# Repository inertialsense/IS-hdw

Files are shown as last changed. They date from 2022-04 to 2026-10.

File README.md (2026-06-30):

Inertial Sense Logo

# Hardware Design Files

The Inertial Sense hardware design files are made available to facilitate product hardware development and integration.

 - **Products** - 3D models and resources for the IMX, Rugged, IG, EVB, and related products useful for printed circuit board CAD and circuit board designs.  Example PCB projects including the IG-1 and EVB-2.  Libraries for schematic and layout designs for printed circuit board. 

------

## LICENSE



Use these Hardware Design files as you wish.  Inertial Sense is not liable for any claim, damages, or other liability resulting from their use.  See the included *LICENSE* file for details.

------

## Support

Email - support@inertialsense.com

------

(c) 2014-2026 Inertial Sense, Inc.

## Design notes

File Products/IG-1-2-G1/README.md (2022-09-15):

# IG-1-G1

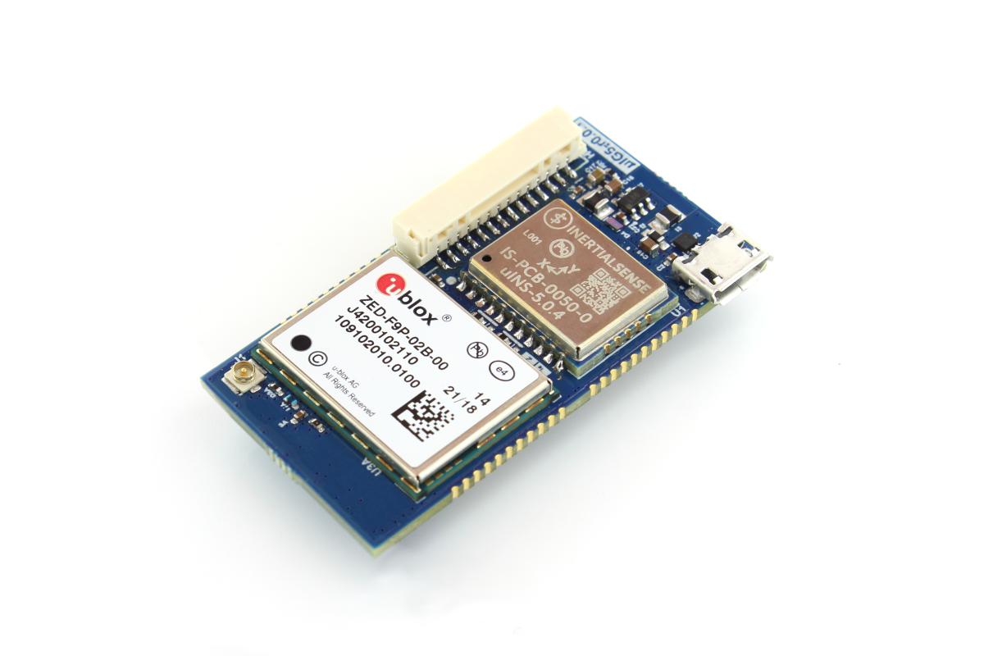
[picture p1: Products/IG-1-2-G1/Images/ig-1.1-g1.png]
IG-1


The InertialSense IG-1 module combines the IMX-5 and a ublox ZED-F9P multi-band GNSS receiver in a compact surface mount modular form factor. 

## Features

- **Tactical Grade IMU (w/ IMX-5)**
  - **Gyro: 1.5 °/hr Bias Instability, 0.16 °/√hr ARW**
  - **Accel: 19 μg Bias Instability, 0.02 m/s/√hr VRW**
- **High Accuracy INS (w/ IMX-5):  0.03° Roll/Pitch, 0.1° Dynamic Heading**
- Up to 1KHz IMU and INS Output Data Rate
- Dual onboard multi-band (L1/L2/E5) GNSS receivers
- Dual U.FL antenna ports for GPS compassing
- Small form factor:  65.2 x 24.5 x 5.9 mm
- Light weight:  <15g
- Low power consumption:  <1500mW
- Surface Mount Reflowable
- Breakout header and micro USB interface to the IMX
- UART x3, SPI interfaces
- Onboard voltage regulation for 3.3V - 17V input

## Applications

- Drone Navigation
- Unmanned Vehicle Payloads
- Ground and Aerial Survey
- Automotive Navigation
- Stabilized Platforms
- Antenna and Camera Pointing
- First Responder and Trackers
- Health, Fitness, and Sport Monitors
- Robotics and Ground Vehicles
- Maritime

## LICENSE



Use these Hardware Design files as you wish.  Inertial Sense is not liable for any claim, damages, or other liability resulting from their use.  See the included *LICENSE* file for details.

------

## Support

Email - support@inertialsense.com

------

(c) 2014-2022 Inertial Sense, Inc.

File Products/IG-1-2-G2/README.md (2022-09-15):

# IG-1-G2

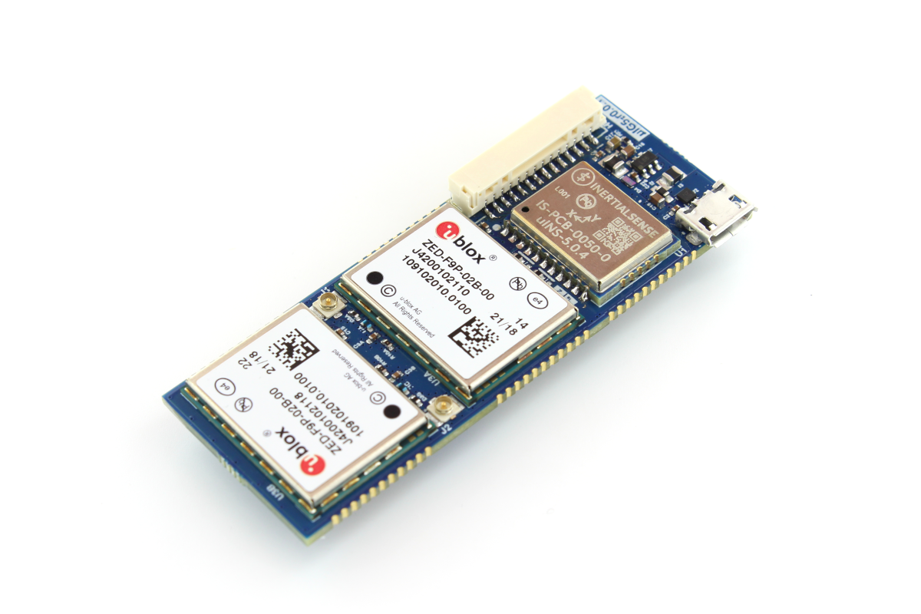
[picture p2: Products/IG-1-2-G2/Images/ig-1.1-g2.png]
IG-1


The InertialSense IG-1-G2 module combines the IMX-5 and two ublox ZED-F9P multi-band GNSS receivers in a compact surface mount modular form factor. 

## Features

- **Tactical Grade IMU (w/ IMX-5)**
  - **Gyro: 1.5 °/hr Bias Instability, 0.16 °/√hr ARW**
  - **Accel: 19 μg Bias Instability, 0.02 m/s/√hr VRW**
- **High Accuracy INS (w/ IMX-5):  0.03° Roll/Pitch, 0.1° Dynamic Heading**
- Up to 1KHz IMU and INS Output Data Rate
- Dual onboard multi-band (L1/L2/E5) GNSS receivers
- Dual U.FL antenna ports for GPS compassing
- Small form factor:  65.2 x 24.5 x 5.9 mm
- Light weight:  <15g
- Low power consumption:  <1500mW
- Surface Mount Reflowable
- Breakout header and micro USB interface to the IMX
- UART x3, SPI interfaces
- Onboard voltage regulation for 3.3V - 17V input

## Applications

- Drone Navigation
- Unmanned Vehicle Payloads
- Ground and Aerial Survey
- Automotive Navigation
- Stabilized Platforms
- Antenna and Camera Pointing
- First Responder and Trackers
- Health, Fitness, and Sport Monitors
- Robotics and Ground Vehicles
- Maritime

## LICENSE



Use these Hardware Design files as you wish.  Inertial Sense is not liable for any claim, damages, or other liability resulting from their use.  See the included *LICENSE* file for details.

------

## Support

Email - support@inertialsense.com

------

(c) 2014-2022 Inertial Sense, Inc.

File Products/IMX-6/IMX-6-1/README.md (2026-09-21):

# IMX-6

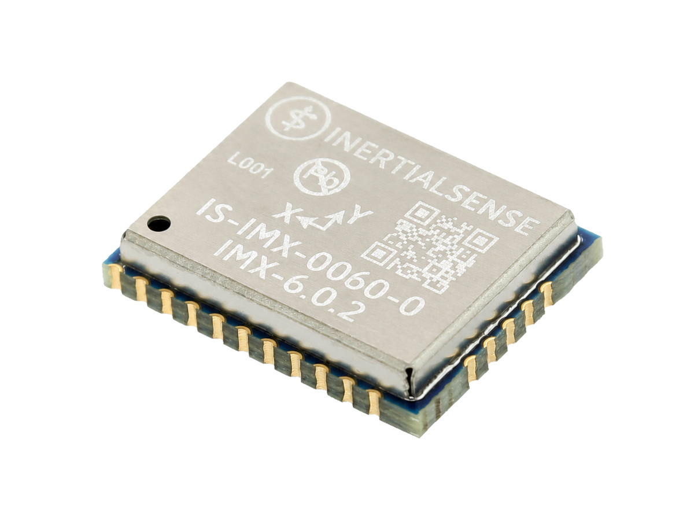
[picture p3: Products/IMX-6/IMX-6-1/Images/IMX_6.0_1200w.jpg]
IMX-6


The **IMX-6**™ is a 10-DOF sensor module consisting of a tactical grade Inertial Measurement Unit (IMU), magnetometer, and barometer. Output includes angular rate, linear acceleration, magnetic vector, and barometric pressure and altitude. IMU calibration consists of bias, scale factor, cross-axis alignment, and temperature compensation. The IMX-6 includes Attitude Heading Reference System (**AHRS**) sensor fusion to estimate roll, pitch, and heading. Adding GNSS input to the IMX-6 enables onboard Inertial Navigation System (**INS**) sensor fusion for roll, pitch, heading, velocity, and position.

## Features

- **Tactical Grade IMU**
  - **Gyro: 0.95 °/hr Bias Instability, 0.10 °/√hr ARW**
  - **Accel: 4.0 µg Bias Instability, 0.011 m/s/√hr VRW**
- **INS, AHRS**
  - **Dynamic: 0.03° Roll/Pitch, 0.09° Heading**
  - **Static: 0.1° Roll/Pitch, 0.5° Heading**
- **Surface Mount Reflowable (PCB Module)**
- Up to 1 KHz IMU and 500 Hz INS Output Data Rate
- Small Form Factor:  15.6 x 12.5 x 2.9 mm
- Light Weight:  0.9 g
- Low power consumption:  <110 mW
- External GNSS Support (Multi-Band)
- Attitude (Roll, Pitch, Yaw, Quaternions), Velocity, and Position UTC Time Synchronized
- Triple Redundant IMUs Calibrated for Bias, Scale Factor, Cross-axis Alignment, and G-sensitivity
- -40°C to 85°C Sensor Temperature Calibration
- Binary and NMEA ASCII Protocol
- Barometric Pressure and Humidity
- Strobe In/Out Data Sync (Camera Shutter Event) 
- Fast Integration with SDK and Example Software

## Applications

- Drone Navigation
- Unmanned Vehicle Payloads
- Ground and Aerial Survey
- Automotive Navigation
- Stabilized Platforms
- Antenna and Camera Pointing
- First Responder and Trackers
- Health, Fitness, and Sport Monitors
- Robotics and Ground Vehicles
- Maritime

## LICENSE



Use these Hardware Design files as you wish.  Inertial Sense is not liable for any claim, damages, or other liability resulting from their use.  See the included *LICENSE* file for details.

------

## Support

Email - support@inertialsense.com

------

(c) 2014-2026 Inertial Sense, Inc.

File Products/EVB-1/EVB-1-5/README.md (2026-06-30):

# EVB-1

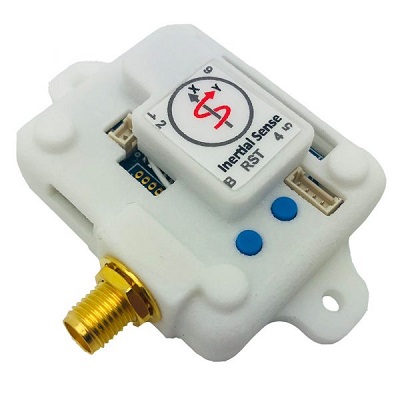
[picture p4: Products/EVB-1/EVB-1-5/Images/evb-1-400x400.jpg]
evb-1


The Inertial Sense EVB1.x is a development board which contains the Inertial Sense µINS, µAHRS, or µIMU module. The EVB1.x functions as a breakout and communications board with the following features:

- Access to all communications pins on the module
- USB connection, either directly to the module or through an on-board FTDI chip
- Integrated RS232 / RS485 transceiver

## LICENSE



Use these Hardware Design files as you wish.  Inertial Sense is not liable for any claim, damages, or other liability resulting from their use.  See the included *LICENSE* file for details.

------

## Support

Email - support@inertialsense.com

------

(c) 2014-2026 Inertial Sense, Inc.

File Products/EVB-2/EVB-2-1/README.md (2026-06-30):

# EVB-2 Evaluation Board

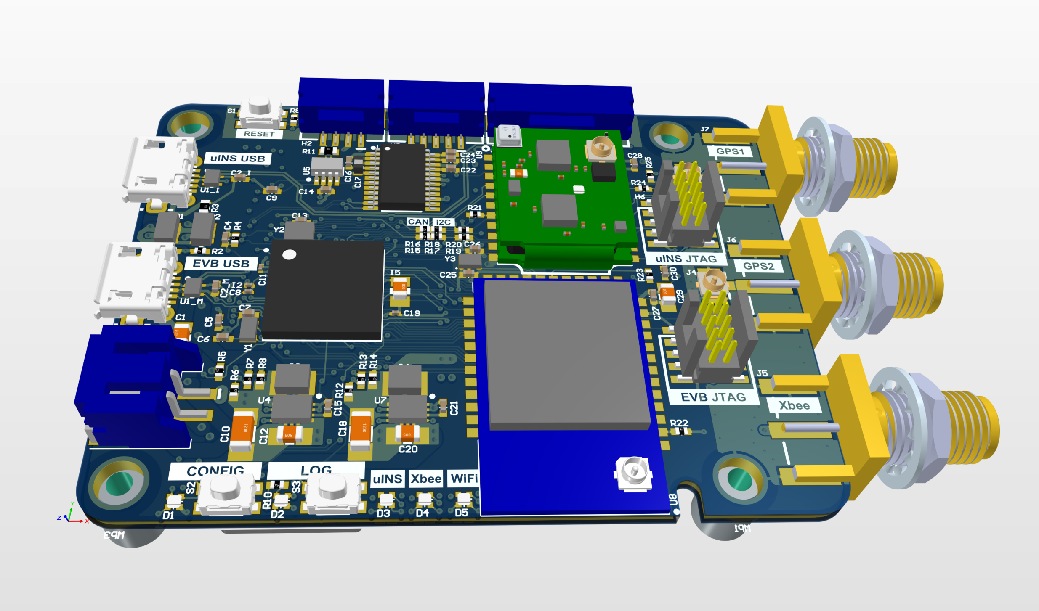
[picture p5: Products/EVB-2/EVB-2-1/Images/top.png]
EVB-2


The Inertial Sense [EVB-2](https://docs.inertialsense.com/user-manual/hardware/EVB2/) is a development board which contains the Inertial Sense µINS, µAHRS, or µIMU module. The EVB-2 builds on the foundation established by the EVB-1, but adds these and other new features.

The EVB-2 PCB assembly design files are provided in Altium Designer format.

## Features

- 915MHz Xbee radio for RTK (real-time-kinematics)
- Wi-Fi and Bluetooth Low energy (BLE) for remote data viewing and logging operation
- Onboard logging to micro SD card.
- Companion Microchip SAME70 processor that serves as a communication bridge between the µINS, µAHRS, or µIMU and all other interfaces.

- **Tactical Grade IMU (w/ IMU-5)**
  - **Gyro: 1.5 °/hr Bias Instability, 0.16 °/√hr ARW**
  - **Accel: 19 μg Bias Instability, 0.02 m/s/√hr VRW**

- **High Accuracy INS (w/ IMU-5):  0.03° Roll/Pitch, 0.1° Dynamic Heading**
- Up to 1KHz IMU and INS Output Data Rate
- Dual onboard GNSS receivers
- Dual SMA antenna ports for GPS compassing
- Size:  70.5 x 45.0 x 12.6 mm
- UART x3, RS232, RS485, CAN, and SPI interfaces
- Integrated CAN and RS232 / RS485 transceivers
- Voltage regulation for 3.3V - 17V input

## Applications

- Drone Navigation
- Unmanned Vehicle Payloads
- Ground and Aerial Survey
- Automotive Navigation
- Stabilized Platforms
- Antenna and Camera Pointing
- First Responder and Trackers
- Health, Fitness, and Sport Monitors
- Robotics and Ground Vehicles
- Maritime

------

## LICENSE



Use these Hardware Design files as you wish.  Inertial Sense is not liable for any claim, damages, or other liability resulting from their use.  See the included *LICENSE* file for details.

------

## Revision Info

### r2.1.2

+ Move TIOA1 (TC input) pin from GPIO1 to GPIO9 for measuring encoder velocity on to GPIO9 (multi-tie).  We would not like to have to tie GPIO9 and GPIO3 together offboard the EVB-2 for wheel encoder input.  We share the QDEC and TC input on the same line for angle and velocity measurement.

+ Consider adding a TC input to each of the QDEC channel A lines so all wheel encoder inputs support velocity measurement.
+ Add second CAN transceiver from EVB E70 to H2 and remove CAN jumper.  We can share H2 with IMX and EVB-E70.  Connect transceivers disable line to jumper or EVB disable line.
+ Enlarge fiducials from 0.76mm to 1.0mm on both sides.
+ Fix the I2C line (SDA, SCL) reversal on EVB-2 SAME70.

________________________________________________________________________________

### r2.1.0

+ Dual purpose reset line to reset IMX and MCU using an RC filters.  One resets
  quickly and the other follows after a delay.
+ Consider loading ICE debugger header for SAME70 MCU by default to support
  developers.
+ Expose IMX data ready pin GPIO13 on H7.
+ Fix top layer copper pour for XBee regulator input that connects C20 pin 2 to
  XBee regulator U7 pin 1.
+ Cut trace (disconnect) VUSB from ESD protection for both USB ports.  It's
  causing voltage to appear on FET switches and partially enable.
+ Add EVB version number to PCB
+ Consider switching battery to Seiko MS621T for -40 to 85 C temp range.
+ Add jumper selection of CAN transceiver to IMX and EVB processor for CAN
  support.
+ Consider exposing SAME70 chip erase (PB12) to SMT resistor pads to 3.3V.
+ Fix reversed IMX CAN Rx and Tx lines.  (Double check this).

________________________________________________________________________________

### r2.0.1

+ Add inverted bold labels for I/O headers.
+ Reverse the H1 power pin order so pin 1 is positive and pin 2 ground.
+ Add fiducials to help SMT machine alignment.
+ Invert and increase label size for I/O headers so they are easier to read.
+ Move to new button style
+ Fit shorter U.FL cables
+ Fix error that applied H1 voltage to the USB port in the power schematic
+ Remove or fix XBee USB power FET logic (Q3).
+ Remove R51 and connect with trace.
+ Fix RX line of XOR gate.
+ Add version label.
+ Update manufacturing docs for new U.FL cables (current cables are good)
+ Jumper to G1_SDA and G2_SCL to CAN transceiver to support future generation
  of IMX which will have new processor with CAN stack. 
+ Consider consolidating the power input FET arrays
+ Move INS reset from common reset to MCU pin.
+ Move voltage sensing circuit to analog capable pin of MCU instead of on INS.
+ Connect QDEC2 and QDEC4 lines to H8 so we can support 3 quadrature encoders.
+ Move to 0.0033uF caps on SS/TR lines on voltage regulators to bring rise time
  into spec.

------

## Support

Email - support@inertialsense.com

------

(c) 2014-2026 Inertial Sense, Inc.

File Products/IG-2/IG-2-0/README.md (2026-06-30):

# IG-2.0

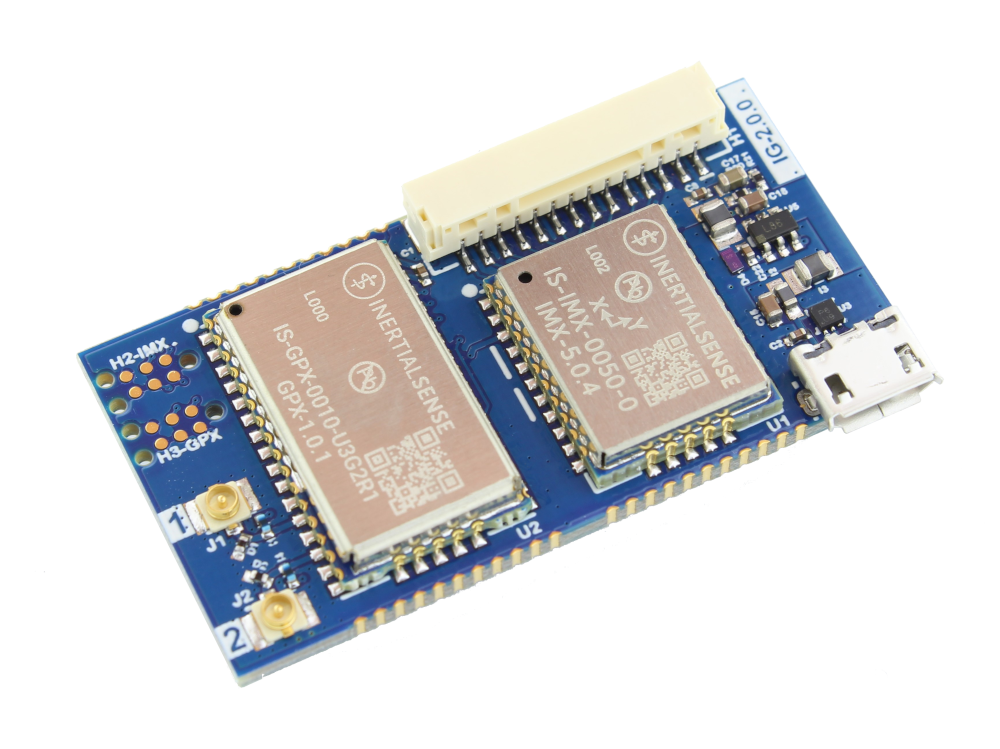
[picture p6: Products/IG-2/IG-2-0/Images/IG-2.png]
IG-2.0


The InertialSense IG-2.0 module combines the IMX-5 and GPX-1 dual multi-band GNSS receiver in a compact surface mount modular form factor. 

## Features

- **Tactical Grade IMU (w/ IMX-5)**
  - **Gyro: 2.0 °/hr Bias Instability, 0.23 °/√hr ARW**
  - **Accel: 27 µg Bias Instability, 0.020 m/s/√hr VRW**
- **High Accuracy INS (w/ IMX-5):  0.03° Roll/Pitch, 0.1° Dynamic Heading**
- Up to 1KHz IMU and INS Output Data Rate
- Dual onboard multi-band (L1/L5) GNSS receivers
- Dual U.FL antenna ports for GPS compassing
- Small form factor:  65.2 x 24.5 x 5.9 mm
- Light weight:  <15g
- Low power consumption:  <1500mW
- Surface Mount Reflowable
- Breakout header and micro USB interface to the IMX
- UART x3, SPI interfaces
- Onboard voltage regulation for 3.3V - 17V input

## Applications

- Drone Navigation
- Unmanned Vehicle Payloads
- Ground and Aerial Survey
- Automotive Navigation
- Stabilized Platforms
- Antenna and Camera Pointing
- First Responder and Trackers
- Health, Fitness, and Sport Monitors
- Robotics and Ground Vehicles
- Maritime

## LICENSE



Use these Hardware Design files as you wish.  Inertial Sense is not liable for any claim, damages, or other liability resulting from their use.  See the included *LICENSE* file for details.

------

## Support

Email - support@inertialsense.com

------

(c) 2014-2026 Inertial Sense, Inc.

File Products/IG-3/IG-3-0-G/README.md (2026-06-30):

# IG-2.1

IG-2.1

The InertialSense IG-2.1 module combines the IMX-6 and GPX-1 dual multi-band GNSS receiver in a compact surface mount modular form factor. 

## Features

- **Tactical Grade IMU (w/ IMX-6)**
  - **Gyro: 1.5 °/hr Bias Instability, 0.10 °/√hr ARW**
  - **Accel: 2.8 µg Bias Instability, 0.013 m/s/√hr VRW**
- **High Accuracy INS (w/ IMX-6):  0.03° Roll/Pitch, 0.1° Dynamic Heading**
- Up to 1KHz IMU and INS Output Data Rate
- Dual onboard multi-band (L1/L5) GNSS receivers
- Dual U.FL antenna ports for GPS compassing
- Small form factor:  65.2 x 24.5 x 5.9 mm
- Light weight:  <15g
- Low power consumption:  <1500mW
- Surface Mount Reflowable
- Breakout header and micro USB interface to the IMX
- UART x3, SPI interfaces
- Onboard voltage regulation for 3.3V - 17V input

## Applications

- Drone Navigation
- Unmanned Vehicle Payloads
- Ground and Aerial Survey
- Automotive Navigation
- Stabilized Platforms
- Antenna and Camera Pointing
- First Responder and Trackers
- Health, Fitness, and Sport Monitors
- Robotics and Ground Vehicles
- Maritime

## LICENSE



Use these Hardware Design files as you wish.  Inertial Sense is not liable for any claim, damages, or other liability resulting from their use.  See the included *LICENSE* file for details.

------

## Support

Email - support@inertialsense.com

------

(c) 2014-2026 Inertial Sense, Inc.

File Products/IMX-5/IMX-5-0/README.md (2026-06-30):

# IMX-5

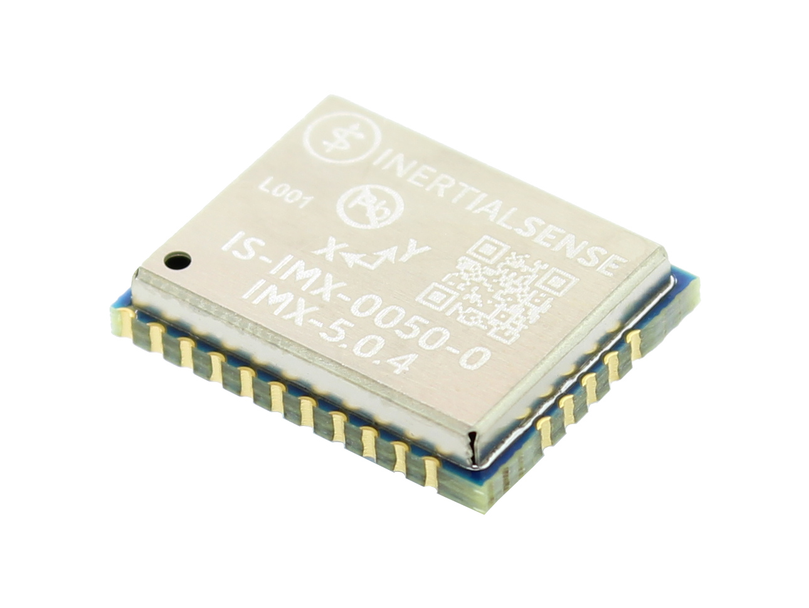
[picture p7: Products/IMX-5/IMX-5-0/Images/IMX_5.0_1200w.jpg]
IMX-5


The **IMX-5**™ is a 10-DOF sensor module consisting of a tactical grade Inertial Measurement Unit (IMU), magnetometer, and barometer. Output includes angular rate, linear acceleration, magnetic vector, and barometric pressure and altitude. IMU calibration consists of bias, scale factor, cross-axis alignment, and temperature compensation. The IMX-5 includes Attitude Heading Reference System (**AHRS**) sensor fusion to estimate roll, pitch, and heading. Adding GNSS input to the IMX-5 enables onboard Inertial Navigation System (**INS**) sensor fusion for roll, pitch, heading, velocity, and position.

## Features

- **Tactical Grade IMU**
  - **Gyro: 2.0 °/hr Bias Instability, 0.23 °/√hr ARW**
  - **Accel: 27 µg Bias Instability, 0.020 m/s/√hr VRW**
- **INS, AHRS**
  - **Dynamic: 0.04° Roll/Pitch, 0.13° Heading**
  - **Static: 0.1° Roll/Pitch, 0.5° Heading**
- **Surface Mount Reflowable (PCB Module)**
- Up to 1 KHz IMU and 142 Hz INS Output Data Rate
- Small Form Factor:  15.6 x 12.5 x 2.9 mm
- Light Weight:  0.8 g
- Low power consumption:  <110 mW
- External GNSS Support (Multi-Band)
- Attitude (Roll, Pitch, Yaw, Quaternions), Velocity, and Position UTC Time Synchronized
- Triple Redundant IMUs Calibrated for Bias, Scale Factor, Cross-axis Alignment, and G-sensitivity
- -40°C to 85°C Sensor Temperature Calibration
- Binary and NMEA ASCII Protocol
- Barometric Pressure and Humidity
- Strobe In/Out Data Sync (Camera Shutter Event) 
- Fast Integration with SDK and Example Software

## Applications

- Drone Navigation
- Unmanned Vehicle Payloads
- Ground and Aerial Survey
- Automotive Navigation
- Stabilized Platforms
- Antenna and Camera Pointing
- First Responder and Trackers
- Health, Fitness, and Sport Monitors
- Robotics and Ground Vehicles
- Maritime

## LICENSE



Use these Hardware Design files as you wish.  Inertial Sense is not liable for any claim, damages, or other liability resulting from their use.  See the included *LICENSE* file for details.

------

## Support

Email - support@inertialsense.com

------

(c) 2014-2026 Inertial Sense, Inc.

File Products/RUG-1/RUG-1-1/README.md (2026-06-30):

# Rugged-1

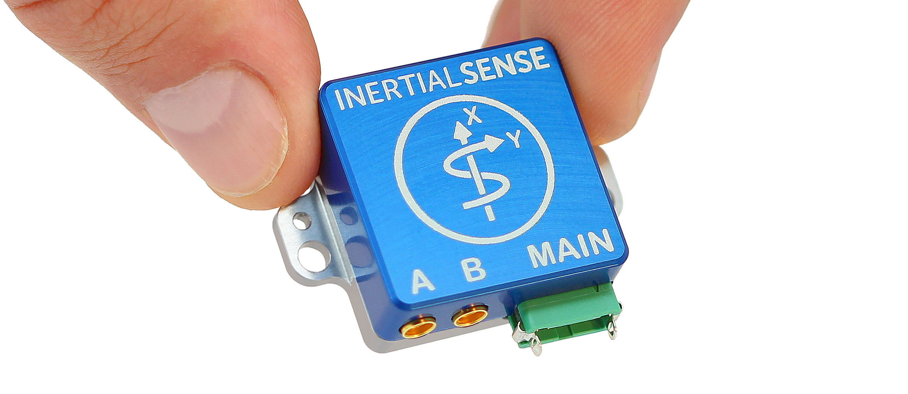
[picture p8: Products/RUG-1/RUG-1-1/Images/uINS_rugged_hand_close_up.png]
Rugged-1


The Inertial Sense Rugged-1 is a ruggedized carrier board and case for the Inertial Sense µINS, µAHRS, or µIMU module. The Rugged-1 has similar functions compared to the EVB-1, but in a more compact form factor with the following added features:

## Features

- **Tactical Grade IMU (w/ IMU-5)**

- - **Gyro: 1.5 °/hr Bias Instability, 0.16 °/√hr ARW**
  - **Accel: 19 μg Bias Instability, 0.02 m/s/√hr VRW**
- **High Accuracy INS (w/ IMU-5):  0.03° Roll/Pitch, 0.1° Dynamic Heading**
- Up to 1KHz IMU and INS Output Data Rate
- Dual onboard multi-band (L1/L2/E5) GNSS receivers
- Dual MMCX antenna ports for GPS compassing
- Size:  25.4 x 25.4 x 11.2 mm
- Light weight:  10.5g
- Low power consumption:  <1100mW
- UART x3, RS232, RS485, CAN, and SPI interfaces
- Integrated CAN and RS232 / RS485 transceivers
- Voltage regulation for 3.3V - 17V input

## Applications

- Drone Navigation
- Unmanned Vehicle Payloads
- Ground and Aerial Survey
- Automotive Navigation
- Stabilized Platforms
- Antenna and Camera Pointing
- First Responder and Trackers
- Health, Fitness, and Sport Monitors
- Robotics and Ground Vehicles
- Maritime

## LICENSE



Use these Hardware Design files as you wish.  Inertial Sense is not liable for any claim, damages, or other liability resulting from their use.  See the included *LICENSE* file for details.

------

## Support

Email - support@inertialsense.com

------

(c) 2014-2026 Inertial Sense, Inc.

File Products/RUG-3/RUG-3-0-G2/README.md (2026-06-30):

# RUG-3-IMX-5-Dual	(Rugged-3 Dual)

<center>

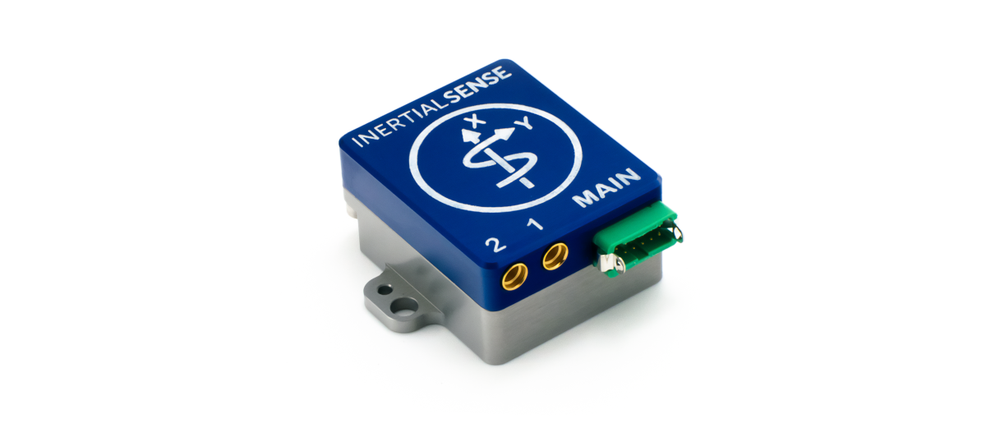
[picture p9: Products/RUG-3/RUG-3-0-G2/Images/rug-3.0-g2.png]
RUG-3-IMX-5-Dual


<center/>

The **RUG-3-IMX-5-Dual** adds a rugged aluminum enclosure and RS232, RS485, and CAN bus to the IMX-5. The **RUG-3-IMX-5-RTK** includes a multi-frequency GNSS receiver with RTK precision position enabling INS sensor fusion for roll, pitch, heading, velocity, and position. The **RUG-3-IMX-5-Dual** includes two multi-frequency GNSS receivers with RTK precision position and dual GNSS heading/compass. 

## Features

- **Tactical Grade IMU (w/ IMU-5)**
  - **Gyro: 2.0 °/hr Bias Instability, 0.23 °/√hr ARW**
  - **Accel: 27 µg Bias Instability, 0.020 m/s/√hr VRW**
- **High Accuracy INS (w/ IMU-5):  0.03° Roll/Pitch, 0.1° Dynamic Heading**
- Up to 1KHz IMU and INS Output Data Rate
- Dual onboard multi-band (L1/L2/E5) GNSS receivers
- Dual MMCX antenna ports for GPS compassing
- Size:  25.4 x 25.4 x 20.0 mm
- Light weight:  14g
- Low power consumption:  <1500mW
- UART x3, RS232, RS485, CAN, and SPI interfaces
- Integrated CAN and RS232 / RS485 transceivers
- Voltage regulation for 3.3V - 17V input

## Applications

- Drone Navigation
- Unmanned Vehicle Payloads
- Ground and Aerial Survey
- Automotive Navigation
- Stabilized Platforms
- Antenna and Camera Pointing
- First Responder and Trackers
- Health, Fitness, and Sport Monitors
- Robotics and Ground Vehicles
- Maritime

## LICENSE



Use these Hardware Design files as you wish.  Inertial Sense is not liable for any claim, damages, or other liability resulting from their use.  See the included *LICENSE* file for details.

------

## Support

Email - support@inertialsense.com

------

(c) 2014-2026 Inertial Sense, Inc.

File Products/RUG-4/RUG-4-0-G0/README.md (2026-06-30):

# RUG-4-G0	(Rugged-4)

<center>

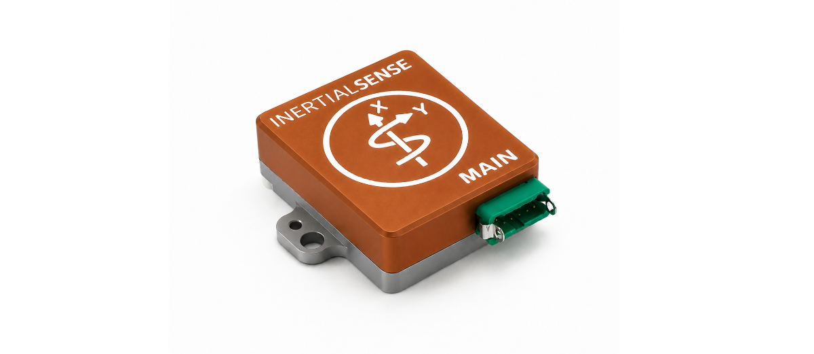
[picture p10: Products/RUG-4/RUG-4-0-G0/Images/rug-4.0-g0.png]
RUG-4-IMX-5


<center/>

The **RUG-4** adds a rugged aluminum enclosure and RS232, RS485, and CAN bus to the **IMX-6**.  Addition of an external GNSS receiver enables the onboard Inertial Navigation System (INS) sensor fusion for roll, pitch, heading, velocity, and position.  

## Features

- **Tactical Grade IMU**
  - **Gyro: 1.5 °/hr Bias Instability, 0.10 °/√hr ARW**
  - **Accel: 2.8 µg Bias Instability, 0.013 m/s/√hr VRW**
- **INS, AHRS**
  - **Dynamic: 0.03° Roll/Pitch, 0.09° Heading**
  - **Static: 0.1° Roll/Pitch, 0.5° Heading**
- Up to 1KHz IMU and INS Output Data Rate
- Dual onboard multi-band (L1/L2/E5) GNSS receivers
- Dual MMCX antenna ports for GPS compassing
- Size:  25.4 x 25.4 x 20.0 mm
- Light weight:  14g
- Low power consumption:  <1500mW
- UART x3, RS232, RS485, CAN, and SPI interfaces
- Integrated CAN and RS232 / RS485 transceivers
- Voltage regulation for 3.1V - 23V input (42V with R1 jumper)

## Applications

- Drone Navigation
- Unmanned Vehicle Payloads
- Ground and Aerial Survey
- Automotive Navigation
- Stabilized Platforms
- Antenna and Camera Pointing
- First Responder and Trackers
- Health, Fitness, and Sport Monitors
- Robotics and Ground Vehicles
- Maritime

## LICENSE



Use these Hardware Design files as you wish.  Inertial Sense is not liable for any claim, damages, or other liability resulting from their use.  See the included *LICENSE* file for details.

------

## Support

Email - support@inertialsense.com

------

(c) 2014-2026 Inertial Sense, Inc.

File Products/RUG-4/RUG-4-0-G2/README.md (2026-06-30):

# RUG-4-Dual	(Rugged-4 Dual)

<center>

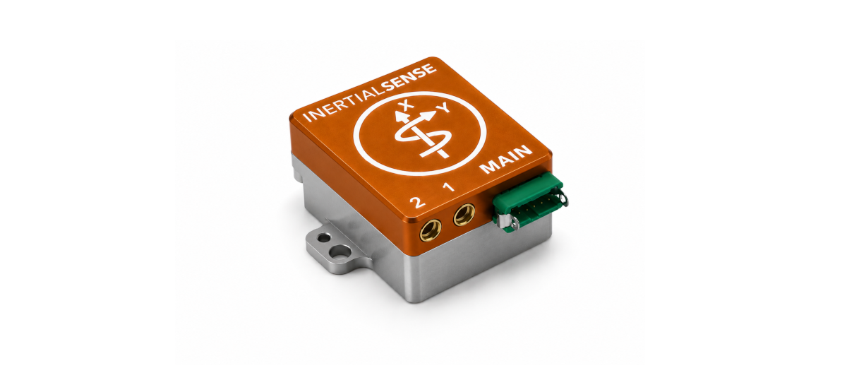
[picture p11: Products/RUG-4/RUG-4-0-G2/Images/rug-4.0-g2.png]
RUG-4-Dual


<center/>

The **RUG-4-Dual** adds a rugged aluminum enclosure and RS232, RS485, and CAN bus to the **IMX-6**. The **RUG-4-RTK** includes a multi-frequency GNSS receiver with RTK precision position enabling INS sensor fusion for roll, pitch, heading, velocity, and position. The **RUG-4-Dual** includes two multi-frequency GNSS receivers with RTK precision position and dual GNSS heading/compass. 

## Features

- **Tactical Grade IMU**
  - **Gyro: 1.5 °/hr Bias Instability, 0.10 °/√hr ARW**
  - **Accel: 2.8 µg Bias Instability, 0.013 m/s/√hr VRW**
- **INS, AHRS**
  - **Dynamic: 0.03° Roll/Pitch, 0.09° Heading**
  - **Static: 0.1° Roll/Pitch, 0.5° Heading**
- Up to 1KHz IMU and INS Output Data Rate
- Dual onboard multi-band (L1/L2/E5) GNSS receivers
- Dual MMCX antenna ports for GPS compassing
- Size:  25.4 x 25.4 x 20.0 mm
- Light weight:  14g
- Low power consumption:  <1500mW
- UART x3, RS232, RS485, CAN, and SPI interfaces
- Integrated CAN and RS232 / RS485 transceivers
- Voltage regulation for 3.1V - 23V input (42V with R1 jumper)

## Applications

- Drone Navigation
- Unmanned Vehicle Payloads
- Ground and Aerial Survey
- Automotive Navigation
- Stabilized Platforms
- Antenna and Camera Pointing
- First Responder and Trackers
- Health, Fitness, and Sport Monitors
- Robotics and Ground Vehicles
- Maritime

## LICENSE



Use these Hardware Design files as you wish.  Inertial Sense is not liable for any claim, damages, or other liability resulting from their use.  See the included *LICENSE* file for details.

------

## Support

Email - support@inertialsense.com

------

(c) 2014-2026 Inertial Sense, Inc.

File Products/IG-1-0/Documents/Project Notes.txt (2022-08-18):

IS-IG-r1.0.3 Project Notes   (- to do, + done, x skipped)

________________________________________________________________________________

Changes for r1.0.3
- Enable GPS PPS input on IMX-5 pin 20 (GPS.TIMEPULSE).  Connect GPS1.TIMEPULSE
  pin to this pin instead of IMX-5 G8 and connect to IG-1 pin 14 (GPS.TIMEPULSE)

________________________________________________________________________________

Changes for r1.0.2
+ Remove ground via that shorts GPS2 Tx line.
+ Fix incorrect header part number.
+ Move USB pads to prevent USB connector from shorting to USB castellated pads.
+ Switch GPS_RESET to G12/SWO/XSCL so that we can make G13/DRDY/XSDA (SPI data
  ready) available.

________________________________________________________________________________

Changes for r0.0.1
+ Remove LDO regulators to reduce power consumption.
+ Add second ZED-F9P.  Use SMD jumpers to connect between Ser2 and Ser1.

________________________________________________________________________________

Changes for r0.0
x Design tabs for mounting in plastic case.
x Make sure other GNSS modules will fit in area of ZED-F9P.

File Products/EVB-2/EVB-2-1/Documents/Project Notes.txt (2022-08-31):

IS-EVB r2.1.2 Project Notes   (- to do, + done, x skipped)

________________________________________________________________________________

Changes for r2.1.3 (future version)
+ Configure EVB-2 to support 2nd external GNSS and not CAN.  We can't support
  both at the same time.  No load U5 and load R17 and R18.
- Update IMX footprint (using either uINS-3.2 or uINS-4.0).  Pads are slightly
  different.
- Add weak pull-up resistor to U2B pin 6 (net M-G2/RXD1/TIOB1_INV) to prevent
  floating input.
- Add second I2C bus to H8 so we can use EVB I2C with using H7 (Luna bump, etc.) 

________________________________________________________________________________

Changes for r2.1.2
+ Fix the I2C line (SDA, SCL) reversal on EVB-2 SAME70.

________________________________________________________________________________

Changes for r2.1.1
+ Move TIOA1 (TC input) pin from GPIO1 to GPIO9 for measuring encoder velocity
  on to GPIO9 (multi-tie).  We would not like to have to tie GPIO9 and GPIO3
  together offboard the EVB-2 for wheel encoder input.  We share the QDEC and
  TC input on the same line for angle and velocity measurement.
+ Consider adding a TC input to each of the QDEC channel A lines so all wheel
  encoder inputs support velocity measurement.
+ Add second CAN transceiver from EVB E70 to H2 and remove CAN jumper.  We can
  share H2 with uINS and EVB-E70.  Connect transceivers disable line to jumper
  or EVB disable line.
+ Enlarge fiducials from 0.76mm to 1.0mm on both sides.

________________________________________________________________________________

Changes for r2.1.0
+ Dual purpose reset line to reset uINS and MCU using an RC filters.  One resets
  quickly and the other follows after a delay.
+ Consider loading ICE debugger header for SAME70 MCU by default to support
  developers.
+ Expose uINS data ready pin GPIO13 on H7.
+ Fix top layer copper pour for XBee regulator input that connects C20 pin 2 to
  XBee regulator U7 pin 1.
+ Cut trace (disconnect) VUSB from ESD protection for both USB ports.  It's
  causing voltage to appear on FET switches and partially enable.
+ Add EVB version number to PCB
+ Consider switching battery to Seiko MS621T for -40 to 85 C temp range.
X Consider Seiko SC-20S for 32.768 KHz crystal. Is it better?
+ Add jumper selection of CAN tranceiver to uINS and EVB processor for CAN
  support.
+ Consider exposing SAME70 chip erase (PB12) to SMT resistor pads to 3.3V.
+ Fix reversed uINS CAN Rx and Tx lines.  (Double check this).

________________________________________________________________________________

Changes for r2.0.1
X Consider adding a battery management IC.
+ Add inverted bold labels for I/O headers.
+ Reverse the H1 power pin order so pin 1 is positive and pin 2 ground.
+ Add fiducials to help SMT machine alignment.
+ Invert and increase label size for I/O headers so they are easier to read.
+ Move to new button style
+ Fit shorter U.FL cables
+ Fix error that applied H1 voltage to the USB port in the power schematic
+ Remove or fix XBee USB power FET logic (Q3).
+ Remove R51 and connect with trace.
+ Fix RX line of XOR gate.
+ Add version label.
+ Update manufacturing docs for new U.FL cables (current cables are good)
X Consider removing second micro USB connector and use a USB switch instead. We
  could use Microchip USB2422 or similar. Extra space freed up can be used for
  battery circuitry.
+ Jumper to G1_SDA and G2_SCL to CAN transciever to support future generation
  of uINS which will have new processor with CAN stack. 
+ Consider consolidating the power input FET arrays
+ Move INS reset from common reset to MCU pin.
+ Move voltage sensing circuit to analog capable pin of MCU instead of on INS.
+ Connect QDEC2 and QDEC4 lines to H8 so we can support 3 quadrature encoders.
x Add pull-up or pull-down resistors on serial Rx lines (or enable SAME70) for
  TTL serial.  (Not necessary. Both SAME70 and SP330 already includes these.)
+ Move to 0.0033uF caps on SS/TR lines on voltage regulators to bring rise time
  into spec.

________________________________________________________________________________

Changes for r2.0
+ parts: ATSAMS70, ATWINC3400-MR210UA122
+ WiFi/BT power down
+ Radio power down
+ XOR gate on GPIO serial port for hobby SBUS input.
+ Put chip erase on semi-convenient pads that can be shorted together.
+ SPI config enable pin on uINS should be controlled by MCU.
+ Consider adding dual LEDs for communications status for XBee and WINC.
+ Consider adding MOSFETs instead of two diodes to prioritize the USB power
  source to elimiate forward voltage drop and power loss.
+ Ensure MCU USB OTG ID detect is connected.
+ Consider making buttons vertical.
+ LED: uINS com, XBee, Wifi, Log/status (tri color).
X Add blue color line to communications LEDs IF there is room.
+ Move LED traces to closest PADs for easier routing.  Keep status/log on PWM.
+ Add series termination resistors inline with serial lines between Xbee and
  MCU.
X Do Xbee Tx/Rx pins go into tristate when powered down.  If not, we need a switch for
  radio data lines to connector.
X Do we need the RTS and CTS pins on the external radio header? If so, consider
  moving back to XBee serial. (We don't)
+ Equalize SD card trace lengths.
+ Double check USB pair spacing and trace lengths.
+ Reconsider whether we should share a common reset pin between uINS and MCU.
  (Jumper)
+ Run ground plane on L2 just below WiFi RTC trace.
+ Add SPI flash chip to uINS.  Use Micron# MT29F2G01ABAGDWB-IT:G TR
  (Digikey# 557-1664-1-ND) Datasheet is here:
  https://www.dropbox.com/s/32wbtqslqhy62je/m79a_2gb_3v_nand_spi.pdf?dl=0
  Dropbox (Inertial Sense)\IS Shared\Datasheets Manuals\Memory - Flash\NAND\m79a_2gb_3v_nand_spi.pdf
  Also added footprint for SOIC-8 memory chips
+ Add CAN jumpers to uINS (for future rev that has onboard CAN).  Use I2C pins
  on uINS.
+ Double check pin directions for serial ports and flow control (CTS, RTS) is
  correct.  Crossovers are needed.
X Consider adding 2 more GPIO pins to SAME70 GPIO header to fill the last two
  empty pins.
+ Check chip select for FLASH chip (added pullup)
+ Identify another RS232/422/485 chip. The one currently on the board only has
  2000 pieces in stock at digikey, is out of stock everywhere else. (SP330)
+ Add decoupling caps between 3.3V and GND planes at high speed digital layer
  transitions.
+ Consider connecting GPS timepulse pin to SAME70
X Consider connecting USB ID pin to uINS through jumper.
+ Check ATSAME70 part number
+ Push button on strobe pin? (control via software)
+ Add ground fence and reinforce connector GND planes
+ Cutback copper pour around GPS and 900MHz RF connectors.
+ Larry thinks non-threaded standoffs would be more versatile.
+ Removed copper below ATWINC BLE WiFi device so we have the option to use the
  integrated antenna module.
x Consider adding a board cutout for the ATWINC.  There's room.
+ Add U.FL cable install instructions (use picture of the real thing!).

________________________________________________________________________________

Changes for r1.4
X Headers for both serial ports (alternate LoRa radio and when USB is not
  connected.
X Power header/connector if USB is not used.
X Add SD card.
x Add SAMA5D27_SOM1 as embedded computer.
+ Ensure GPS timepulse on uINS pin 20 is tied to a header for access.
X Reversing Molex pin order so pin 1 matches Molex labels.  (This causes
  customers problems).
+ Add +3.3V and +5V (and extra grounds) on dev interface to power external
  devices.
+ Add H122039-ND CABLE ASSEM UFL-UFL 35MM 0.81 to BOM.
X Move connectors out of way of uINS pads so we can solder/desolder the uINS w/o
  removing the connectors. (We don't want to support removing uINS from EVB)
X Consider configuring the connector pinouts so that Tx and Rx are always the
  same pins, that way we can swap connectors and still get connectivity.
X Invert USB connector so USB-B label faces up.  Either get inverted style or
  move to the bottom of the board.
X Remove JTAG header and reset button.
X Add CAN bus interface back.
+ Change JTAG (SWD) connector pinout to use the SAM port not AVR, on the
  ATMELICE debugger.
+ Add solder paste back to uINS pads (so we can more quickly assemble the uINS).
X Get uINS to SMD reflow capability.  Assemble all headers.
+ Remove kapton tape from under the uINS.
+ Remove voltage divider to FTDI reset pin.  This is no longer necessary since
  we moved the FTDI VCC from +3.3V to USB.VBUS.  It used to be that this voltage
  divider would hold the device in a tri-state mode if no USB connection was
  present.  Now the device is entirely off.
+ Switch micro USB connector to through hole version to prevent pop-offs.
  Amphenol# 10118194-0001LF or Molex# 1050170001
+ Add 2nd GPS antenna connector (GPS compassing support).
+ Add Zigbee U.FL and SMA connector
X Espressif ESP32 Wifi/BT chip - move micro SD card to it?
+ Consider side actuating button:
    https://www.digikey.com/product-detail/en/panasonic-electronic-components/
    EVQ-P7J01P/P16767CT-ND/4429460
x Switch SMA connectors to rugged INS style RF connectors to save space.
X Switch back to AB USB connector so we can use the device as a master or a slave.
X Consider including ethernet port (ESP32 has support for it). External PHY and code is available,
  part number is LAN8720. Maybe better would be to use the ethernet if we are making a test bed
  networking board.
+ Fix chip select on SPI bus
+ Consider adding Pi SPI bus (MOSI, MISO, CLK, CS) to GPIO header.
X Consider adding wifi RP-SMA connector (not needed, range is pretty good)
X Consider integrating power header pins into comm header
+ Ensure the USB interface on the INS works or consider adding switch to connect
  Serial port on INS to Pi UART
+ Remove alignment pins for uINS
+ Add way to disable radio and plug in own radio
+ Removed uINS solder paste.
+ Consider moving Xbee radio Tx/Rx LEDs from FTDI to Tx/Rx lines using FETs.
x Consider adding another USB switch to switch INS between slave USB on hub
  and master on USB host post
x Consider adding third FTDI chip to connect uINS to USB hub in case USB driver
  falls through.
+ Decide to use 5mm or 6mm standoffs for compute module. (We chose 5mm).
+ Add RP-SMA part number and description for XBee part.
+ Consider adding notch for WiFi U.FL coax to route to 2nd GPS SMA connector...
+ Ensure all active parts have at least one 10nF decoupling cap.
+ Change board standoffs (non-Pi) to correct height.
+ Consider adding additional AP2331 to host USB port to prevent reset of RPi
  when device plugged in.
+ Confirm that varistor is rated correctly.
x Can we add Pi PWM to header to drive servo motors?  Would be nice to have 4
  PWM.  Maybe we can double up I/O to get this.
+ Method to disable Xbee radio? SMD power jumper?
+ Add dedicated oscilator so we don't have to do anything special on the PI.
  Consider using SiTime# SIT1533AI-H4-DCC-32.768E ($1, 2x1.2mm).
  Added a different part from the WiFi shield
+ Ensure that the USB interface to the uINS still works even if Pi power supply
  is not present.  (i.e. if H1 is not connected, the uINS and USB interface
  should still work).  Supply 3.3V (INS.3V3) to FTDI devices as long as it
  doesn't effect performance.
+ Fix H2 pin order - try to arrage so we get GPIO numbering in order.
x Reconsider need for XBee full handshake UART, add jumper to INS GPIO for DTR
  so it can program
+ Switching USB ESD protection to TI# TPD2EUSB30DRTR.
+ Reinforce SMD headers with copper pour to prefent them from tearing off.
X Change XBee power switch to MCU control?
+ Check JTAG pinouts

Items to test before fabrication:
- Ability to reconfigure Xbee modems through uINS.  Do we need to connect DTR for this?

________________________________________________________________________________

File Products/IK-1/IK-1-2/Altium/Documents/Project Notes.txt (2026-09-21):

IS-IK-r1.2.1 Project Notes   (- to do, + done, x skipped)

Changes for r1.2.2 (Future)
-

________________________________________________________________________________

Changes for r1.2.1 (Current)
+ Minor layout changes to address polygon pour over same net issue.

________________________________________________________________________________

Changes for r1.2.0
+ Fixed VSUB (+5V) through hole connection point that was incorrectly connected
  to ground.
+ Clean up design rules.

________________________________________________________________________________

Changes for r1.1.1
+ Fixed U2 USB TVS footprint.
+ Added keepout around USB-C connector alignment pins.

________________________________________________________________________________

Changes for r1.1.0 (Current)
+ Add VUSB (+5V) to a through hole that can be used to wire USB pigtail to. USB
  data and ground are already available.
+ Ensure VAUX (VUSB) jumper is always loaded.  Users must remove that for 1.8V
  operation.

________________________________________________________________________________

Changes for r1.0.0 (Current)
-

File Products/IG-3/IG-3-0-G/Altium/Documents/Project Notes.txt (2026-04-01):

IS-IG-r2.1.0 Project Notes   (- to do, + done, x skipped)

________________________________________________________________________________

Changes for r2.1.1 (Future)
- Consider making switching regulator configurable via jumper for 1.8V output.
  This could also be done by changing the resistor divider.

________________________________________________________________________________

Changes for r2.1.0 (Current)
+ Switch IMX-5 to IMX-6.  Connect VUSB (pin 30).
+ Switch SWD debug connector from TagConnect to Samtec SMT style.
+ Connect GPX GNSS2_PPS to IMX G13/DRDY/XSDA.
x Add supercap backup batter used on RUG (if it fits).

________________________________________________________________________________

Changes for r2.0.3
+ Add pull-up resistor on GPS reset line so that GPS will be disabled won't
  interfere with bootloader update.  Alternatively, the IMX could assert the
  GPS reset during bootloader update.
+ Add missing GPX I/O pins to IG-2 SMT pins: USB, chip erase (boot mode).

________________________________________________________________________________

Changes for r2.0.2
+ Add diode from 3.3V to VBAT to supply VBAT when powered (if USB is used or
  VBAT is not supplied).
+ Add 1-2uF cap to VBAT to suppress transients when main power is cut.

________________________________________________________________________________

Changes for r2.0.1
+ Expose GPX-1 serial port pins on IG pads so GPX can be accesse IF IMX5 is not
  loaded.
+ Separate reset lines between IMX5 and GPX1 so SWD debug interfaces aren't tied
  together.
+ Connected TRACE/SWO from lines to debugger interface and IMX and GPX.
+ Consider adding GPX-1 SPI to LGA pads.
x Consider adding shunt resistor to GPX-1 power.
+ Space tag-connect debug connnectors further appart so we can use both ports
  at the same time.  Ideal spacing is 5.5mm.
+ Fix version number on the silkscreen.

________________________________________________________________________________

Changes for r2.0.0
-

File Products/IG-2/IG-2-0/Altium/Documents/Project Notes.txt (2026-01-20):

IS-IG-r2.1.0 Project Notes   (- to do, + done, x skipped)

________________________________________________________________________________

Changes for r2.1.1 (Future)
-

________________________________________________________________________________

Changes for r2.1.0 (Current)
- Consider making switching regulator configurable via jumper for 1.8V output.
  This could also be done by changing the resistor divider.
- Consider adding the JTAG header (either SMD default style or tag connect with
  locking pins.
+ Connect GPX GNSS2_PPS to IMX G13/DRDY/XSDA.

________________________________________________________________________________

Changes for r2.0.3
+ Add pull-up resistor on GPS reset line so that GPS will be disabled won't
  interfer with bootloader update.  Alternatively, the IMX could assert the
  GPS reset during bootloader update.
+ Add missing GPX I/O pins to IG-2 SMT pins: USB, chip erase (boot mode).

________________________________________________________________________________

Changes for r2.0.2
+ Add diode from 3.3V to VBAT to supply VBAT when powered (if USB is used or
  VBAT is not supplied).
+ Add 1-2uF cap to VBAT to suppress transients when main power is cut.

________________________________________________________________________________

Changes for r2.0.1
+ Expose GPX-1 serial port pins on IG pads so GPX can be accesse IF IMX5 is not
  loaded.
+ Separate reset lines between IMX5 and GPX1 so SWD debug interfaces aren't tied
  together.
+ Connected TRACE/SWO from lines to debugger interface and IMX and GPX.
+ Consider adding GPX-1 SPI to LGA pads.
x Consider adding shunt resistor to GPX-1 power.
+ Space tag-connect debug connnectors further appart so we can use both ports
  at the same time.  Ideal spacing is 5.5mm.
+ Fix version number on the silkscreen.

________________________________________________________________________________

Changes for r2.0.0
-

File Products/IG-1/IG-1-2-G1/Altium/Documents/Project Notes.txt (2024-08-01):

IS-IG-r1.2.0-G1 Project Notes   (- to do, + done, x skipped)

________________________________________________________________________________

Changes for r1.2.1 (Future)
- 

________________________________________________________________________________

Changes for r1.2.0
x Consider adding Tag-Connect SWD interface.
+ Add diode from 3.3V to VBAT to supply VBAT when powered (if USB is used or
  VBAT is not supplied).
+ Add 1-2uF cap to VBAT to suppress transients when main power is cut.
+ Add pull-up resistor on GPS reset line so that GPS will be disabled won't
  interfere with bootloader update.  Alternatively, the IMX could assert the
  GPS reset during bootloader update.
+ Expose the ZED-F9P second serial port on IG-1 unused pads.
+ Switch the SMT pins/pads from ground to no connect for the pins that
  correspond with the IG-2 so they share the same footprint. 
________________________________________________________________________________

Changes for r1.1.1
+ Switched pin H1-4 from GPS_RESET_N to G13/DRDY/XSDA (SPI data ready).
+ Switched pin 4 on U1 LGA pads from GPS_RESET_N to RESERVED.
________________________________________________________________________________

Changes for r1.1.0
+ Enable GPS PPS input on IMX-5 pin 20 (GPS.TIMEPULSE).  Connect GPS1.TIMEPULSE
  pin to this pin instead of IMX-5 G8 and connect to IG-1 pin 14
  (GPS.TIMEPULSE).  This will free up the SPI bus for use on the IG-1.
+ Add jumper for GPS2.TIMEPULSE to IMX-5 G9 pin 10 to support GPS2 PPS input.

________________________________________________________________________________

Changes for r1.0.2
+ Remove ground via that shorts GPS2 Tx line.
+ Fix incorrect header part number.
+ Move USB pads to prevent USB connector from shorting to USB castellated pads.
+ Switch GPS_RESET to G12/SWO/XSCL so that we can make G13/DRDY/XSDA (SPI data
  ready) available.

________________________________________________________________________________

Changes for r0.0.1
+ Remove LDO regulators to reduce power consumption.
+ Add second ZED-F9P.  Use SMD jumpers to connect between Ser2 and Ser1.

________________________________________________________________________________

Changes for r0.0
x Design tabs for mounting in plastic case.
x Make sure other GNSS modules will fit in area of ZED-F9P.

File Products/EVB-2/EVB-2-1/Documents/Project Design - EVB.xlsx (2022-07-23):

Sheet: E70 Pinout
Primary Signal | LFBGA 144 Ball | Power Rail | I/O Type | Dir | Alternate | Dir | PIO Peripheral A | Dir | PIO Peripheral B | Dir | PIO Peripheral C | Dir | PIO Peripheral D | Dir | Reset State | EVB Connection | EVB Pin | Multi Tie |  | Unassigned Connections | Pin
PA0 | C11 | VDDIO | GPIO_AD | I/O | WKUP0(1) | I | PWMC0_PWMH0 | O | TIOA0 (QDEC0 A) | I/O | A17/BA1 | O | I2SC0_MCK | – | PIO,I,PU,ST | GPIO3 | QDEC0 A | Yes
PA1 | D12 | VDDIO | GPIO_AD | I/O | WKUP1(1) | I | PWMC0_PWML0 | O | TIOB0 (QDEC0 B) | I/O | A18 | O | I2SC0_CK | – | PIO,I,PU,ST | GPIO4 | QDEC0 B | Yes
PA2 | E12 | VDDIO | GPIO | I/O | WKUP2(1) | I | PWMC0_PWMH1 | O | – | – | DATRG | I | – | – | PIO,I,PU,ST
PA3 | F12 | VDDIO | GPIO_AD | I/O | PIODC0(2) | I | TWD0 | I/O | LONCOL1 | I | PCK2 | O | – | – | PIO,I,PU,ST | uINS - I2C | SDA
PA4 | K12 | VDDIO | GPIO | I/O | WKUP3/PIODC1(3) | I | TWCK0 | O | TCLK0 | I | UTXD1 | O | – | – | PIO,I,PU,ST | uINS - I2C | SCL
PA5 | M11 | VDDIO | GPIO_AD | I/O | WKUP4/PIODC2(3) | I | PWMC1_PWML3 | O | ISI_D4 | I | URXD1 | I | – | – | PIO,I,PU,ST | uINS - Ser0 | Tx (cross)
PA6 | B9 | VDDIO | GPIO_AD | I/O | – | – | – | – | PCK0 | O | UTXD1 | O | – | – | PIO,I,PU,ST | uINS - Ser0 | Rx (cross)
PA7 | L2 | VDDIO | CLOCK | I/O | XIN32(4) | I | – | – | PWMC0_PWMH3 | O | – | – | – | – | PIO,HiZ | Xin32
PA8 | M2 | VDDIO | CLOCK | I/O | XOUT32(4) | O | PWMC1_PWMH3 | O | AFE0_ADTRG | I | – | – | – | – | PIO,HiZ | Xout32
PA9 | M12 | VDDIO | GPIO_AD | I/O | WKUP6/PIODC3(3) | I | URXD0 | I | ISI_D3 | I | PWMC0_PWMFI0 | I | – | – | PIO,I,PU,ST | uINS - Ser1, SPI | Tx (cross) | Yes
PA10 | L9 | VDDIO | GPIO_AD | I/O | PIODC4(2) | I | UTXD0 | O | PWMC0_PWMEXTRG0 | I | RD | I | – | – | PIO,I,PU,ST | uINS - Ser1, SPI | Rx (cross) | Yes
PA11 | J9 | VDDIO | GPIO_AD | I/O | WKUP7/PIODC5(3) | I | QCS | O | PWMC0_PWMH0 | O | PWMC1_PWML0 | O | – | – | PIO,I,PU,ST | LED - Log | Red
PA12 | L10 | VDDIO | GPIO_AD | I/O | PIODC6(2) | I | QIO1 | I/O | PWMC0_PWMH1 | O | PWMC1_PWMH0 | O | – | – | PIO,I,PU,ST | LED - Log | Blue
PA13 | M3 | VDDIO | GPIO_AD | I/O | PIODC7(2) | I | QIO0 | I/O | PWMC0_PWMH2 | O | PWMC1_PWML1 | O | – | – | PIO,I,PU,ST | LED - Config | Green
PA14 | K6 | VDDIO | GPIO_CLK | I/O | WKUP8/PIODCEN1(3) | I | QSCK | O | PWMC0_PWMH3 | O | PWMC1_PWMH1 | O | – | – | PIO,I,PU,ST
PA15 | L5 | VDDIO | GPIO_AD | I/O | – | – | D14 | I/O | TIOA1 | I/O | PWMC0_PWML3 | O | I2SC0_WS | – | PIO,I,PU,ST | GPIO9 |  | Yes
PA16 | K5 | VDDIO | GPIO_AD | I/O | – | – | D15 | I/O | TIOB1 (QDEC0 Idx) | I/O | PWMC0_PWML2 | O | I2SC0_DI | – | PIO,I,PU,ST | GPIO2 | QDEC0 Idx | Yes |  |  | Header | Connection | EVB SAM Pins | Option1 | Pin | Option2 | Pin | Option3 | Pin | Option4 | Pin | Option5 | Pin
PA17 | J1 | VDDIO | GPIO_AD | I/O | AFE0_AD6(5) | I | QIO2 | I/O | PCK1 | O | PWMC0_PWMH3 | O | – | – | PIO,I,PU,ST | M-USB ID |  |  |  |  | H8-5 | M1 | PB4 | TXD1 (MISO) | PB4
PA18 | H2 | VDDIO | GPIO_AD | I/O | AFE0_AD7(5) | I | PWMC1_PWMEXTRG1 | I | PCK2 | O | A14 | O | – | – | PIO,I,PU,ST | SP330-SLEW |  |  |  |  | H8-6 | M2 | PA16, PA21 | RXD1 (MOSI) | PA21 | TIOB1 (QDEC0 Idx) | PA16 | AFE0_AD1 | PA21 | PWMC0_PWML2 | PA16
PA19 | H1 | VDDIO | GPIO_AD | I/O | AFE0_AD8/WKUP9(6) | I | – | – | PWMC0_PWML0 | O | A15 | O | I2SC1_MCK | – | PIO,I,PU,ST | SP330-SHDN |  |  |  |  | H8-7 | M3 | PA0, PA23, PE3 | SCK1 (SCLK) | PA23 | TIOA0 (QDEC0 A) | PA0 | AFE1_AD10(5) |  | PWMC0_PWMH0 | PA0 | TIOA10 | PE3
PA20 | H3 | VDDIO | GPIO_AD | I/O | AFE0_AD9/WKUP10(6) | I | – | – | PWMC0_PWML1 | O | A16/BA0 | O | I2SC1_CK | – | PIO,I,PU,ST | SP330-RXEN |  |  |  |  | H8-8 | M4 | PA1, PA24, | RTS1 (CS) | PA24 | TIOB0 (QDEC0 B) | PA1 |  |  | PWMC0_PWML0 | PA1
PA21 | K2 | VDDIO | GPIO_AD | I/O | AFE0_AD1/PIODCEN2(8) | I | RXD1 | I | PCK1 | O | PWMC1_PWMFI0 | I | – | – | PIO,I,PU,ST | GPIO2 | Rx | Yes |  |  | H8-9 | M5 | PB13, PC5, PC29 | DAC0 | PB13 | TIOA6 (QDEC2 A) | PC5 | AFE1_AD4 | PC29 | PWMC0_PWML2 | PB13 | TIOA5 | PC29
PA22 | K3 | VDDIO | GPIO_AD | I/O | PIODCCLK(2) | I | RK | I/O | PWMC0_PWMEXTRG1 | I | NCS2 | O | – | – | PIO,I,PU,ST |  |  |  |  |  | H8-10 | M6 | PC6, PD0 | DAC1 | PD0 | TIOB6 (QDEC2 B) | PC6 |  |  | PWMC1_PWML0 | PD0
PA23 | L4 | VDDIO | GPIO_AD | I/O | – | – | SCK1 | I/O | PWMC0_PWMH0 | O | A19 | O | PWMC1_PWML2 | O | PIO,I,PU,ST | GPIO3 | SCK | Yes |  |  | H8-11 | M7 | PC9 |  |  | TIOB7 (QDEC2 Idx) | PC9
PA24 | L7 | VDDIO | GPIO_AD | I/O | – | – | RTS1 | O | PWMC0_PWMH1 | O | A20 | O | ISI_PCK | I | PIO,I,PU,ST | GPIO4 | CS | Yes |  |  | H8-12 | M8 | PD27, PE4 |  |  | TIOB10 (QDEC3 Idx) | PE4 | AFE0_AD4 (PC29) | PE4 | PWMC0_PWML3 | PD27
PA25 | K8 | VDDIO | GPIO_AD | I/O | – | – | CTS1 | I | PWMC0_PWMH2 | O | A23 | O | MCCK | O | PIO,I,PU,ST | SD Card | CLK |  |  |  | H8-13 | M9 | PA15, PC13, PE0 |  |  | TIOA9 (QDEC3 A) | PE0 | AFE1_AD1/AFE1_AD10 | PC13/PE0 | PWMC0_PWMH3 | PC13 | TIOA1 | PA15
PA26 | J8 | VDDIO | GPIO_AD | I/O | – | – | DCD1 | I | TIOA2 | O | MCDA2 | I/O | PWMC1_PWMFI1 | I | PIO,I,PU,ST | SD Card | D2 |  |  |  | H8-14 | M10 | PC15, PE1 |  |  | TIOB9 (QDEC3 B) | PE1 | AFE1_AD2 | PC15 | PWMC0_PWML3 | PC15
PA27 | J10 | VDDIO | GPIO_AD | I/O | – | – | DTR1 | O | TIOB2 | I/O | MCDA3 | I/O | ISI_D7 | I | PIO,I,PU,ST | SD Card | D3 |  |  |  | H7-7 | uINS-Ser0.TxD | PA5 | URXD1 | PA5
PA28 | C9 | VDDIO | GPIO_AD | I/O | – | – | DSR1 | I | TCLK1 | I | MCCDA | I/O | PWMC1_PWMFI2 | I | PIO,I,PU,ST | SD Card | CMD |  |  |  | H7-8 | uINS-Ser0.RxD | PA6 | UTXD1 | PA6
PA29 | A6 | VDDIO | GPIO_AD | I/O | – | – | RI1 | I | TCLK2 | I | – | – | – | – | PIO,I,PU,ST | Xbee - UART | RST |  |  |  | H7-11 | uINS-Ser1.TxD, SPI | PA9 | URXD0 | PA9 | SPI0_MISO | PD20
PA30 | A10 | VDDIO | GPIO_AD | I/O | WKUP11(1) | I | PWMC0_PWML2 | O | PWMC1_PWMEXTRG0 | I | MCDA0 | I/O | I2SC0_DO | – | PIO,I,PU,ST | SD Card | D0 |  |  |  | H7-10 | uINS-Ser1.RxD, SPI | PA10 | UTXD0 | PA10 | SPI0_MOSI | PD21
PA31 | C8 | VDDIO | GPIO_AD | I/O | – | – | SPI0_NPCS1 | I/O | PCK2 | O | MCDA1 | I/O | PWMC1_PWMH2 | O | PIO,I,PU,ST | SD Card | D1 |  |  |  | H7-9 | uINS-Ser1.SCLK,SPI | PD22 |  |  | SPI0_SPCK | PD22
PB0 | H4 | VDDIO | GPIO_AD | I/O | AFE0_AD10/RTCOUT0(7) | I | PWMC0_PWMH0 | O | – | – | RXD0 | I | TF | I/O | PIO,I,PU,ST | Xbee - UART | Tx (cross) |  |  |  | H7-12 | uINS-Ser1.CS,SPI | PD12 |  |  | SPI0_NPCS2 | PD12
PB1 | G3 | VDDIO | GPIO_AD | I/O | AFE1_AD0/RTCOUT1(7) | I | PWMC0_PWMH1 | O | GTSUCOMP | O | TXD0 | I/O | TK | I/O | PIO,I,PU,ST | Xbee - UART | Rx (cross) |  |  |  | H7-6 | uINS-Ser2.TxD (I2C0.SCL) | PA4 | TWCK0 | PA4
PB2 | J2 | VDDIO | GPIO_AD | I/O | AFE0_AD5(5) | I | CANTX0 | O | – | – | CTS0 | I | SPI0_NPCS0 | I/O | PIO,I,PU,ST | Xbee - UART | CTS (no cross) |  |  |  | H7-5 | uINS-Ser2.RxD (I2C0.SDA) | PA3 | TWD0 | PA3
PB3 | J3 | VDDIO | GPIO_AD | I/O | AFE0_AD2/WKUP12(6) | I | CANRX0 | I | PCK2 | O | RTS0 | O | ISI_D2 | I | PIO,I,PU,ST | Xbee - UART | RTS (no cross) |  |  |  | H4-7 | Ext Radio Rx | PD25 | URXD2 | PD25 | PWMC0_PWML1 | PD25
PB4 | A12 | VDDIO | GPIO_AD | I/O | TDI(9) | I | TWD1 | I/O | PWMC0_PWMH2 | O | – | – | TXD1 | I/O | PIO,I,PD,ST | GPIO1 | Tx |  |  |  | H4-8 | Ext Radio Tx | PD26 | UTXD2 | PD26 | PWMC0_PWML2 | PD26
PB5 | C10 | VDDIO | GPIO_AD | I/O | TDO/TRACESWO/WKUP13(9) | O | TWCK1 | O | PWMC0_PWML0 | O | – | – | TD | O | O,PU | JTAG | SWO/TDO |  |  |  | H4-9 | Ext Radio Reset | PD7 |  |  | PWMC1_PWMH3 | PD7
PB6 | J11 | VDDIO | GPIO_AD | I/O | SWDIO/TMS(9) | I | – | – | – | – | – | – | – | – | PIO,I,ST | JTAG | SWDIO/TMS
PB7 | F9 | VDDIO | GPIO_AD | I/O | SWCLK/TCK(9) | I | – | – | – | – | – | – | – | – | PIO,I,ST | JTAG | SWCLK/TCK
PB8 | A3 | VDDIO | GPIO_AD | I/O | XOUT(10) | O | – | – | – | – | – | – | – | – | PIO,HiZ | Xout
PB9 | A2 | VDDIO | GPIO_AD | I/O | XIN(10) | I | – | – | – | – | – | – | – | – | PIO,HiZ | Xin
PB12 | G12 | VDDIO | GPIO_AD | I/O | ERASE(9) | I | PWMC0_PWML1 | O | GTSUCOMP | O | – | – | PCK0 | O | PIO,I,PD,ST
PB13 | B2 | VDDIO | GPIO_AD | I/O | DAC0(11) | O | PWMC0_PWML2 | O | PCK0 | O | SCK0 | I/O | – | – | PIO,I,PU,ST | GPIO5 | DAC | Yes
PC0 | E4 | VDDIO | GPIO_AD | I/O | AFE1_AD9(5) | I | D0 | I/O | PWMC0_PWML0 | O | – | – | – | – | PIO,I,PU,ST | Hardware Detect 0
PC1 | J4 | VDDIO | GPIO_AD | I/O | – | – | D1 | I/O | PWMC0_PWML1 | O | – | – | – | – | PIO,I,PU,ST | Hardware Detect 1
PC2 | K4 | VDDIO | GPIO_AD | I/O | – | – | D2 | I/O | PWMC0_PWML2 | O | – | – | – | – | PIO,I,PU,ST | Hardware Detect 2
PC3 | L3 | VDDIO | GPIO_AD | I/O | – | – | D3 | I/O | PWMC0_PWML3 | O | – | – | – | – | PIO,I,PU,ST | Config Button
PC4 | J5 | VDDIO | GPIO_AD | I/O | – | – | D4 | I/O | – | – | – | – | – | – | PIO,I,PU,ST
PC5 | L8 | VDDIO | GPIO_AD | I/O | – | – | D5 | I/O | TIOA6 (QDEC2 A) | I/O | – | – | – | – | PIO,I,PU,ST | GPIO5 | QDEC2 A | Yes
PC6 | K7 | VDDIO | GPIO_AD | I/O | – | – | D6 | I/O | TIOB6 (QDEC2 B) | I/O | – | – | – | – | PIO,I,PU,ST | GPIO6 | QDEC2 B
PC7 | M4 | VDDIO | GPIO_AD | I/O | – | – | D7 | I/O | TCLK6 | I | – | – | – | – | PIO,I,PU,ST | Log Button
PC8 | J12 | VDDIO | GPIO_AD | I/O | – | – | NWR0/NWE | O | TIOA7 | I/O | – | – | – | – | PIO,I,PU,ST | LED INS Rx
PC9 | G11 | VDDIO | GPIO_AD | I/O | – | – | NANDOE | O | TIOB7 (QDEC2 Idx) | I/O | – | – | – | – | PIO,I,PU,ST | GPIO7 | QDEC2 Idx
PC10 | F10 | VDDIO | GPIO_AD | I/O | – | – | NANDWE | O | TCLK7 | I | – | – | – | – | PIO,I,PU,ST | LED Bee Rx
PC11 | F11 | VDDIO | GPIO_AD | I/O | – | – | NRD | O | TIOA8 | I/O | – | – | – | – | PIO,I,PU,ST | LED Bee Tx
PC12 | F4 | VDDIO | GPIO_AD | I/O | AFE1_AD3(5) | I | NCS3 | O | TIOB8 | I/O | CANRX1 | I | – | – | PIO,I,PU,ST | CAN - Xcvr | Rx |  | Cross in transciever
PC13 | G2 | VDDIO | GPIO_AD | I/O | AFE1_AD1(5) | I | NWAIT | I | PWMC0_PWMH3 | O | SDA10 | O | – | – | PIO,I,PU,ST | GPIO9 |  | Yes
PC14 | E10 | VDDIO | GPIO_AD | I/O | – | – | NCS0 | O | TCLK8 | I | CANTX1 | O | – | – | PIO,I,PU,ST | CAN - Xcvr | Tx |  | Cross in transciever
PC15 | G1 | VDDIO | GPIO_AD | I/O | AFE1_AD2(5) | I | NCS1/SDCS | O | PWMC0_PWML3 | O | – | – | – | – | PIO,I,PU,ST | GPIO10 |  | Yes
PC16 | D11 | VDDIO | GPIO_AD | I/O | – | – | A21/NANDALE | O | – | – | – | – | – | – | PIO,I,PU,ST | SD Card | Detect
PC17 | B12 | VDDIO | GPIO_AD | I/O | – | – | A22/NANDCLE | O | – | – | – | – | – | – | PIO,I,PU,ST | WINC LED Rx
PC18 | B10 | VDDIO | GPIO_AD | I/O | – | – | A0/NBS0 | O | PWMC0_PWML1 | O | – | – | – | – | PIO,I,PU,ST | SP330 Duplex
PC19 | D8 | VDDIO | GPIO_AD | I/O | – | – | A1 | O | PWMC0_PWMH2 | O | – | – | – | – | PIO,I,PU,ST
PC20 | A9 | VDDIO | GPIO_AD | I/O | – | – | A2 | O | PWMC0_PWML2 | O | – | – | – | – | PIO,I,PU,ST | uINS SPI Enable
PC21 | A7 | VDDIO | GPIO_AD | I/O | – | – | A3 | O | PWMC0_PWMH3 | O | – | – | – | – | PIO,I,PU,ST | ATWINC - WiFi | RST
PC22 | C7 | VDDIO | GPIO_AD | I/O | – | – | A4 | O | PWMC0_PWML3 | O | – | – | – | – | PIO,I,PU,ST | ATWINC - WiFi | CHIP-EN
PC23 | C6 | VDDIO | GPIO_AD | I/O | – | – | A5 | O | TIOA3 (QDEC1 A) | I/O | – | – | – | – | PIO,I,PU,ST | ATWINC - WiFi | WiFi-IRQN
PC24 | B6 | VDDIO | GPIO_AD | I/O | – | – | A6 | O | TIOB3 (QDEC1 B) | I/O | SPI1_SPCK | O | – | – | PIO,I,PU,ST | ATWINC - WiFi | SCLK
PC25 | C5 | VDDIO | GPIO_AD | I/O | – | – | A7 | O | TCLK3 | I | SPI1_NPCS0 | I/O | – | – | PIO,I,PU,ST | ATWINC - WiFi | CS
PC26 | F2 | VDDIO | GPIO_AD | I/O | AFE1_AD7(5) | I | A8 | O | TIOA4 | I/O | SPI1_MISO | I | – | – | PIO,I,PU,ST | ATWINC - WiFi | MISO
PC27 | E2 | VDDIO | GPIO_AD | I/O | AFE1_AD8(5) | I | A9 | O | TIOB4 (QDEC1 Idx) | I/O | SPI1_MOSI | O | – | – | PIO,I,PU,ST | ATWINC - WiFi | MOSI
PC28 | L12 | VDDIO | GPIO_AD | I/O | – | – | A10 | O | TCLK4 | I | SPI1_NPCS1 | I/O | – | – | PIO,I,PU,ST | LED INS Tx
PC29 | F3 | VDDIO | GPIO_AD | I/O | AFE1_AD4(5) | I | A11 | O | TIOA5 | I/O | SPI1_NPCS2 | O | – | – | PIO,I,PU,ST | GPIO5 | TC, AD | Yes |  | Can be removed if needed
PC30 | F1 | VDDIO | GPIO_AD | I/O | AFE1_AD5(5) | I | A12 | O | TIOB5 | I/O | SPI1_NPCS3 | O | – | – | PIO,I,PU,ST |  |  |  |  | GPS Timepulse
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

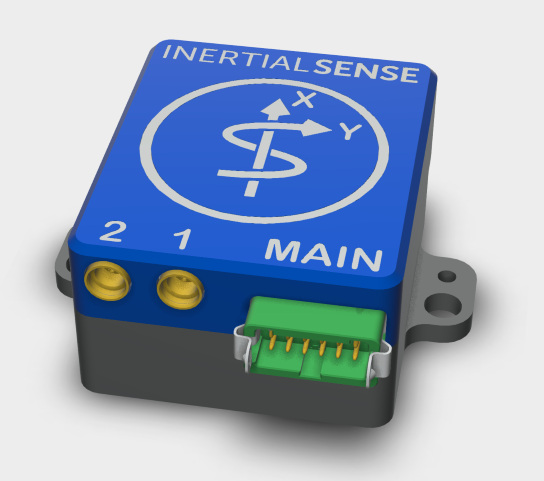
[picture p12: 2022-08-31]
Products/RUG-3/RUG-3-0-G2/Images/rug-3.0-G2_cad.png

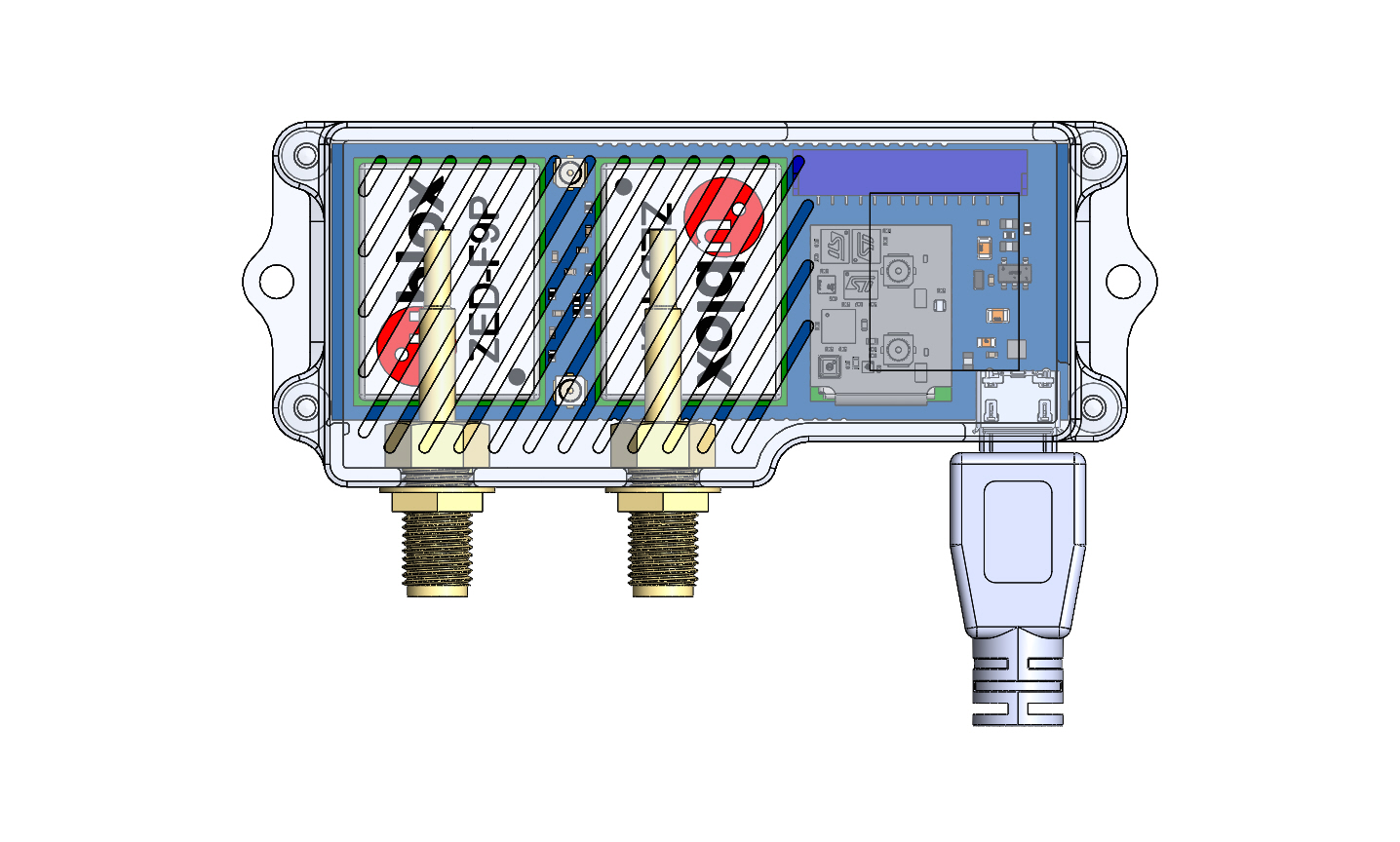
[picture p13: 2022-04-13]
Products/IG-1/IG-1-2-G2/Images/IG-1.1_shaded_top.jpg

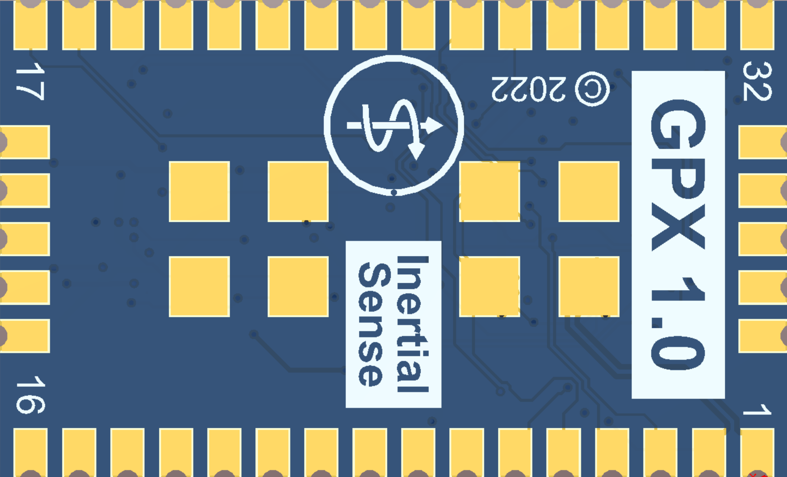
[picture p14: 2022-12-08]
Products/GPX-1/GPX-1-0/Images/GPX_1.0.1_bottom.png

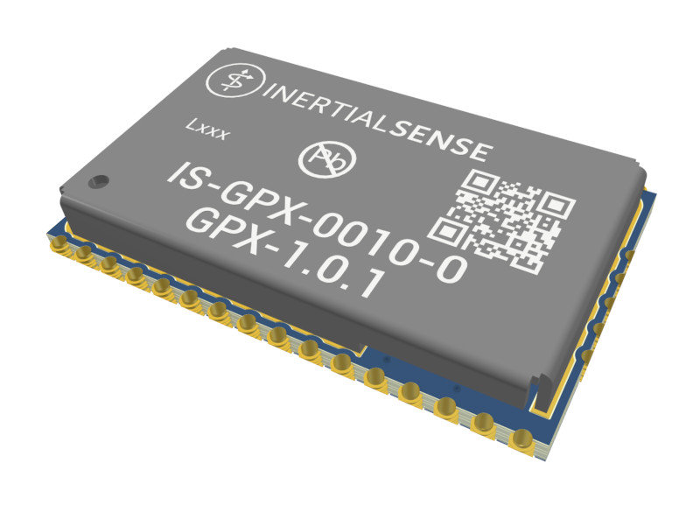
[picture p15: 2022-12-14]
Products/GPX-1/GPX-1-0/Images/GPX_1.0_800w.jpg

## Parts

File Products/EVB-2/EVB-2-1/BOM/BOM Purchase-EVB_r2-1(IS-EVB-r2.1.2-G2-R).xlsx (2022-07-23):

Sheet: BOM
BOM | IS-EVB-r2.1.2-G2-R |  |  | C O N F I D E N T I A L / P R O R I E T A R Y
 | Evaluation Board |  |  |  |  | InertialSense
PCB Part Number: | IS-EVB-r2.1.2 |  |  | Production Qty: | 100 | 3000 S Sierra Vista Way Suite 2
 |  |  |  | Total Cost: | $18316.07 | Provo, UT 84606
Report Date: | 1/22/2021 | 10:26 AM |  |  |  | 801-610-6359
Print Date: | 2021-01-22 | 10:27:03 |  |  |  | info@inertialsense.com
Fitted | Quantity | Description | Designator | Manufacturer Part Number | Manufacturer | Supplier Part Number 1 | Supplier 1 | Supplier Unit Price 1 | Supplier Subtotal 1
Fitted | 1 | BATTERY LITH 3V RECHARGE SMD | BAT1 | MS621T-FL11E | Seiko | 728-1080-ND | Digi-Key | $1.79 | $179.14
Fitted | 8 | CAP CER 10UF 35V X5R 0805 | C1, C12, C20, C29, C52, C54, C55, C56 | C2012X5R1V106K085AC | TDK | 445-14417-6-ND | Digi-Key | $0.16 | $131.87
Fitted | 19 | CAP CER .10UF 50V X7R 10% 0402 | C2_I, C2_M, C5, C9, C13, C14, C16, C22, C23, C24, C25, C26, C27, C28, C30, C32, C41, C51, C57 | C1005X7R1H104K | TDK Corporation | 445-5932-1-ND | Digi-Key | $0.02 | $40.81
Fitted | 1 | CAP CER 0.22UF 16V X7R 0402 | C3 | GRM155R71C224KA12D | Murata | 490-5418-6-ND | Digi-Key | $0.04 | $3.78
Fitted | 1 | CAP CER 10PF 50V C0G 0402 | C4 | C1005C0G1H100D050BA | TDK | 445-1235-6-ND | Digi-Key | $0.03 | $2.91
Fitted | 2 | CAP CER 15PF 16V C0G/NP0 0402 | C6, C7 | C0402C150J4GACTU | KEMET | 399-8947-6-ND | Digi-Key | $0.01 | $1.94
Fitted | 17 | CAP CER 0.1UF 25V X5R 0201 | C8, C11, C19, C36, C37, C38, C39, C40, C42, C43, C44, C45, C46, C47, C48, C49, C50 | GRM033R6YA104KE14D | Murata | 490-10430-1-ND | Digi-Key | $0.01 | $21.59
Fitted | 3 | CAP CER 22UF 10V X5R 1206 | C10, C18, C33 | CL31A226KPHNNNE | Samsung | 1276-1287-6-ND | Digi-Key | $0.17 | $50.49
Fitted | 2 | CAP CER 0.0033UF 50V X7R 0402 | C15, C21 | CL05B332JB5NNNC | Samsung | 1276-1548-6-ND | Digi-Key | $0.01 | $2.68
Fitted | 2 | CAP CER 1UF 25V X7R 0603 | C17, C31 | CL10B105KA8NNNC | Samsung | 1276-1184-6-ND | Digi-Key | $0.02 | $4.02
Fitted | 1 | CAP CER 0.047UF 16V Y5V 0402 | C34 | CC0402ZRY5V7BB473 | Yageo | 311-1046-6-ND | Digi-Key | $0.01 | $1.12
Fitted | 2 | CAP CER 2.2UF 6.3V X5R 0603 | C35, C53 | CL10A225KQ8NNWC | Samsung | 1276-1886-1-ND | Digi-Key | $0.03 | $6.34
Fitted | 5 | LED RGB DIFFUSED 0404 SMD | D1, D2, D3, D4, D5 | SMLP34RGB2W3 | Rohm Semiconductor | SMLP34RGB2W3TR-ND | Digi-Key | $0.36 | $1787.95
Fitted | 2 | DIODE SCHOTTKY 30V 2A 0603 | D6, D7 | VSKY20301608-G4-08 | Vishay | VSKY20301608-G4-08GICT-ND | Digi-Key
Fitted | 1 | CONN HEADER PH SIDE 2POS 2MM SMD | H1 | S2B-PH-SM4-TB(LF)(SN) | JST | 455-1749-1-ND | Digi-Key | $0.38 | $38.13
Fitted | 1 | CONN HEADER GH SIDE 4POS 1.25MM | H2 | SM04B-GHS-TB(LF)(SN)- | JST | 455-1566-1-ND | Digi-Key | $0.31 | $31.42
Fitted | 1 | CONN HEADER GH SIDE 5POS 1.25MM | H3 | SM05B-GHS-TB(LF)(SN) | JST | 455-1567-1-ND | Digi-Key
Fitted | 1 | CONN HEADER GH SIDE 9POS 1.25MM | H4 | SM09B-GHS-TB(LF)(SN) | JST | 455-1571-2-ND | Digi-Key
Fitted | 1 | CONN HEADER 10POS DUAL .05" SMD | H5 | FTSH-105-01-L-DV-K-A-P | Samtec | SAM9440-ND | Digi-Key | $3.32 | $332.00
Fitted | 2 | CONN HEADER GH SIDE 14POS 1.25MM | H7, H8 | SM14B-GHS-TB(LF)(SN) | JST | 455-1576-6-ND | Digi-Key
Fitted | 1 | CONN MICRO SD CARD PUSH-PULL R/A | H9 | 114-00841-68 | Amphenol Commercial | 114-00841-68-6-ND | Digi-Key | $1.09 | $108.57
Fitted | 4 | FIXED IND 1UH 3.3A 40 MOHM | I1, I3, I4, I8 | DFE252012F-1R0M=P2 | Murata | 490-13053-6-ND | Digi-Key | $0.34 | $136.30
Fitted | 1 | FERRITE BEAD 240 OHM 0201 1LN | I2 | MMZ0603S241HT000 | TDK Corporation | 445-172341-1-ND | Digi-Key | $0.06 | $5.50
Fitted | 1 | FIXED IND 10UH 350MA 1.066 OHM | I5 | CBC2016T100M | Taiyo Yuden | 587-1606-1-ND | Digi-Key | $0.14 | $14.40
Fitted | 2 | FERRITE BEAD 470 OHM 0402 | I6, I7 | BK1005HM471-T | Taiyo Yuden | 587-1838-6-ND | Digi-Key | $0.02 | $4.95
Fitted | 2 | CONN USB MICRO B RECPT SMT R/A | J2_I, J2_M | 10118194-0001LF | Amphenol FCI | 609-4618-6-ND | Digi-Key | $0.32 | $63.16
Fitted | 3 | CONN UMC RCPT STR 50 OHM SMD | J3, J4, J8 | 128-0711-201 | Emerson Network Power Connectivity Johnson | J983CT-ND | Digi-Key | $0.49 | $145.80
Fitted | 1 | CONN RPSMA JCK STR 50OHM EDGEMNT | J5 | 132255RP | Amphenol Connex | ACX1425-ND | Digi-Key | $7.10 | $710.40
Fitted | 2 | CONN SMA RCPT STR 50OHM EDGE MNT | J6, J7 | 732511150 | Molex | WM5534-ND | Digi-Key | $2.10 | $420.32
Fitted | 3 | CBL ASSY UMCC PLUG-PLUG 1.969" | J9, J10, J11 | 415-0084-050 | Bel Cinch | J918-ND | Digi-Key
Fitted | 4 | RND STANDOFF M2.5X0.45 STEEL 5MM | MP1, MP2, MP3, MP4 | 9774050951R | Wurth Electronics | 732-7098-1-ND | Digi-Key | $0.74 | $295.60
Fitted | 4 | 4V DRIVE PCH+PCH MOSFET | Q1, Q2, Q5, Q6 | TT8J3TR | Rohm | TT8J3TRCT-ND | Digi-Key | $0.36 | $145.60
Fitted | 11 | RES SMD 100K OHM 1% 1/16W 0402 | R1, R2, R8, R14, R23, R38, R39, R44, R45, R48, R49 | ERJ-2RKF1003X | Panasonic | P100KLDKR-ND | Digi-Key | $0.00398 | $4.38
Fitted | 1 | RES SMD 5.62K OHM 1% 1/10W 0402 | R4 | ERJ-2RKF5621X | Panasonic | P5.62KLDKR-ND | Digi-Key | $0.01 | $0.88
Fitted | 7 | RES 10K OHM 1/16W 1% 0402 SMD | R5, R9, R19, R20, R35, R41, R43 | ERJ-2RKF1002X | Panasonic | P10.0KLDKR-ND | Digi-Key | $0.00398 | $3.98
Fitted | 2 | RES SMD 560K OHM 1% 1/10W 0402 | R6, R12 | ERJ-2RKF5603X | Panasonic | P560KLDKR-ND | Digi-Key | $0.01 | $1.76
Fitted | 2 | RES SMD 150K OHM 1% 1/10W 0402 | R7, R13 | ERJ-2RKF1503X | Panasonic | P150KLDKR-ND | Digi-Key | $0.01 | $1.78
Fitted | 12 | RES SMD 470 OHM 5% 1/16W 0402 | R10, R28, R29, R30, R31, R32, R36, R40, R42, R46, R55, R56 | CRCW0402470RJNED | Vishay Dale | 541-470JDKR-ND | Digi-Key | $0.01 | $6.13
Fitted | 1 | RES SMD 120 OHM 5% 1/4W 0603 | R11 | ESR03EZPJ121 | Rohm | RHM120DDKR-ND | Digi-Key | $0.03 | $2.75
Fitted | 4 | RES 470 OHM 1/16W 1% 0402 SMD | R21, R24, R33, R34 | CRCW0402470RFKED | Vishay Dale | 541-470LCT-ND | Digi-Key | $0.01 | $5.32
Fitted | 1 | RES SMD 1M OHM 5% 1/10W 0402 | R22 | ERJ-2GEJ105X | Panasonic | P1.0MJDKR-ND | Digi-Key | $0.01 | $0.77
Fitted | 1 | RES 1.00K OHM 1/16W 1% 0402 SMD | R26 | RC0402FR-071KL | Yageo | 311-1.00KLRCT-ND | Digi-Key | $0.01 | $0.58
Fitted | 1 | RES SMD 0 OHM JUMPER 1/16W 0402 | R51 | RC0402JR-070RL | Yageo | 311-0.0JRDKR-ND | Digi-Key | $0.0047 | $0.47
Fitted | 1 | RES SMD 1M OHM 1% 1/16W 0402 | R54 | RC0402FR-071ML | Yageo | 311-1.00MLRCT-ND | Digi-Key | $0.01 | $0.58
Fitted | 3 | SWITCH TACTILE SPST-NO 0.05A 16V | S1, S2, S3 | PTS810SJK250SMTRLFS | ITT C&K | CKN10503DKR-ND | Digi-Key | $0.25 | $73.60
Fitted | 2 | TVS DIODE 5.5V SOT5 | U1_I, U1_M | TPD3E001DRLR | Texas Instruments | 296-21885-1-ND | Digi-Key | $0.29 | $58.24
Fitted | 1 | IC GATE XOR 2CH 2-INP US8 | U2 | SN74LVC2G86DCUR | Texas Instruments | 595-SN74LVC2G86DCUR | Mouser | $0.36 | $36.40
Fitted | 1 | IC MCU 32BIT 1MB FLASH 144LFBGA | U3 | ATSAME70Q20B-CNT | Microchip | ATSAME70Q20B-CNTDKR-ND | Digi-Key | $16.53 | $1653.00
Fitted | 2 | IC REG BUCK ADJ 3.5A 11VQFN | U4, U7 | TPS62135RGXR | Texas Instruments | 296-47242-6-ND | Digi-Key | $1.55 | $309.52
Fitted | 2 | IC TXRX CAN 3.3V SOT23-8 | U5, U13 | TCAN334DCNR | Texas Instruments | 296-47830-1-ND | Digi-Key | $1.81 | $362.94
Fitted | 1 | IC TXRX RS232/485 24TSSOP | U6 | SP330EEY-L | Exar | 1016-1977-ND | Digi-Key | $2.87 | $286.89
Fitted | 1 | WIFI/BLE MODULE | U8 | ATWINC3400-MR210UA122 | Microchip | ATWINC3400-MR210UA122-ND | Digi-Key | $10.20 | $1020.00
Fitted | 1 | Inertial Sense uINS | U9 | IS-uINS-3.2-G2 | Inertial Sense | IS-uINS-3.2-G2 | Inertial Sense
Fitted | 1 | XBEE PRO MOD TXRX ISM 915MHZ UFL | U10 | XBP9X-DMUS-001 | Digi International | 602-1890-ND | Digi-Key | $86.25 | $8625.00
Fitted | 1 | VARISTOR 0402 | V1 | CG0402MLC-12LG | Bourns | CG0402MLC-12LGCT-ND | Digi-Key | $0.23 | $22.75
Fitted | 1 | CRYSTAL 32.7680KHZ 9PF SMD | Y1 | ABS06-32.768KHZ-9-1-T | Abracon LLC | 535-10247-1-ND | Digi-Key | $1.42 | $141.75
Fitted | 1 | OSC XO 12.000MHZ HCMOS SMD | Y2 | ECS-2520S33-120-FN-TR | ECS Inc. | XC2194TR-ND | Digi-Key | $0.93 | $929.25
Fitted | 1 | OSC MEMS 32.768KHZ LVCMOS SMD | Y3 | SIT1533AI-H4-DCC-32.768E | SiTime | 1473-1239-1-ND | Digi-Key | $0.81 | $80.56
Not Fitted | 0 | CONN HEADER 10POS DUAL .05" SMD | H6 | FTSH-105-01-L-DV-K-A-P | Samtec | SAM9440-ND | Digi-Key
Not Fitted | 0 | RES SMD 0 OHM JUMPER 1/10W 0603 | R3 | RC0603JR-070RL | Yageo | 311-0.0GRDKR-ND | Digi-Key
Not Fitted | 0 | RES SMD 0 OHM JUMPER 1/16W 0402 | R17, R18, R27, R37 | RC0402JR-070RL | Yageo | 311-0.0JRDKR-ND | Digi-Key
Not Fitted | 0 | RES 1.00K OHM 1/16W 1% 0402 SMD | R25, R53
Not Fitted | 0 | RES 1.00K OHM 1/16W 1% 0402 SMD | R47 | RC0402FR-071KL | Yageo | 311-1.00KLRCT-ND | Digi-Key
Not Fitted | 0 | IC FLASH 128M SPI 133MHZ 8SOIC | U11 | W25Q128JVSIQTR | Winbond | W25Q128JVSIQCT-ND | Digi-Key
Not Fitted | 0 | IC FLASH 1G/2G SPI 8UPDFN | U12 | MT29F2G01ABAGDWB-IT:GTR | Micron Technology | 557-1664-6-ND | Digi-Key

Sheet: Digikey Order
Production Qty: | 100
 |  | Quantity | Total | Supplier Part Number 1 | Designator
 |  | 1 | 100 | 728-1080-ND | BAT1
 |  | 8 | 800 | 445-14417-6-ND | C1, C12, C20, C29, C52, C54, C55, C56

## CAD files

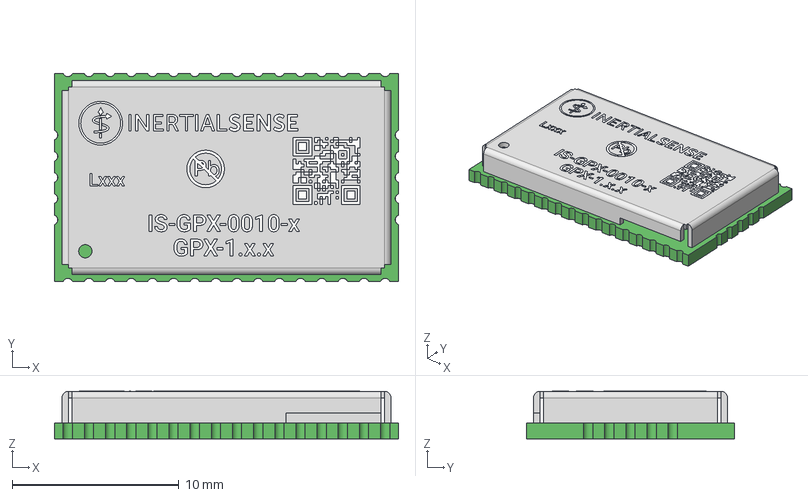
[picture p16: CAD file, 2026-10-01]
Products/GPX-1/GPX-1-0/3D_Model/GPX-r1.0.step
20.6 x 12.5 x 2.87 mm
Can
Extruded x 56

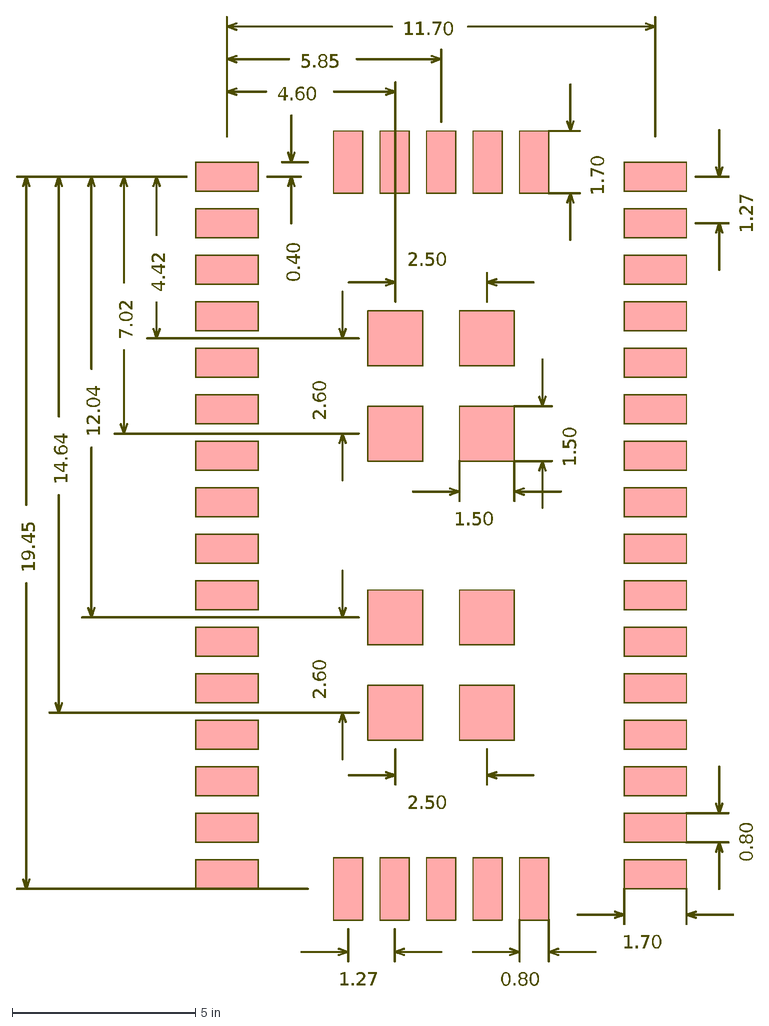
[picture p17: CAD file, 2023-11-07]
Products/GPX-1/GPX-1-0/PCB_Library/Altium/IS-GPX-1_recommended_layout.DXF
1.70
0.40
19.45
14.64
12.04
7.02
0.80
1.27
11.70
5.85
4.60
1.50
2.50
2.60
4.42

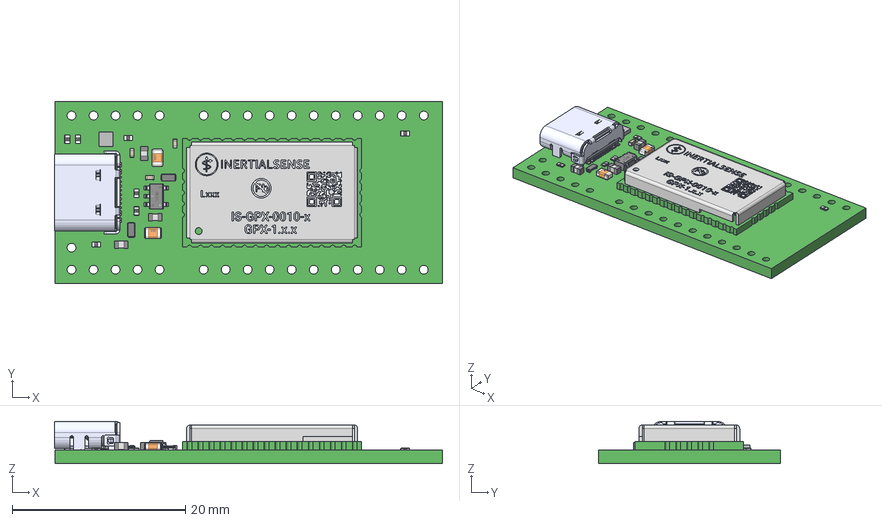
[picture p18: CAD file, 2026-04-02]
Products/IK-1/IK-1-1/3D_Model/IK-r1-1.step
44.8 x 21.0 x 4.89 mm
Lead x 4
SW3dPS-0402 SMD Resistor x 7
USB4105
Extruded x 57
Can
User Library-SMD CAPACITOR (1) x 3
SW3dPS-0805 SMD Capacitor x 2
SW3DPS-CAPACITOR 0603-DEFAULT x 3
SW3dPS-SOT23-5_SOT23-5 Connector x 5
SW3dPS-SOT23-5_SOT23-5 Body

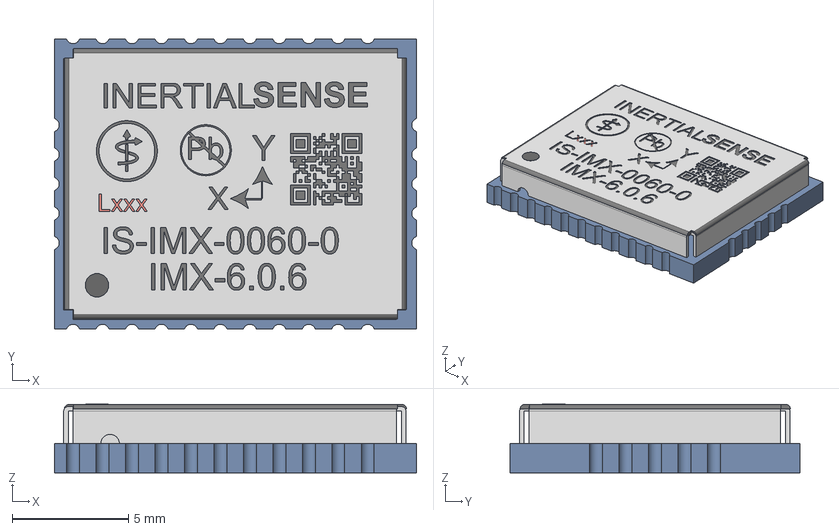
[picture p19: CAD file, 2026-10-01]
Products/IMX-6/IMX-6-1/3D_Model/IMX-6.step
15.6 x 12.5 x 2.96 mm
IMX Can v30
label v1
Extruded

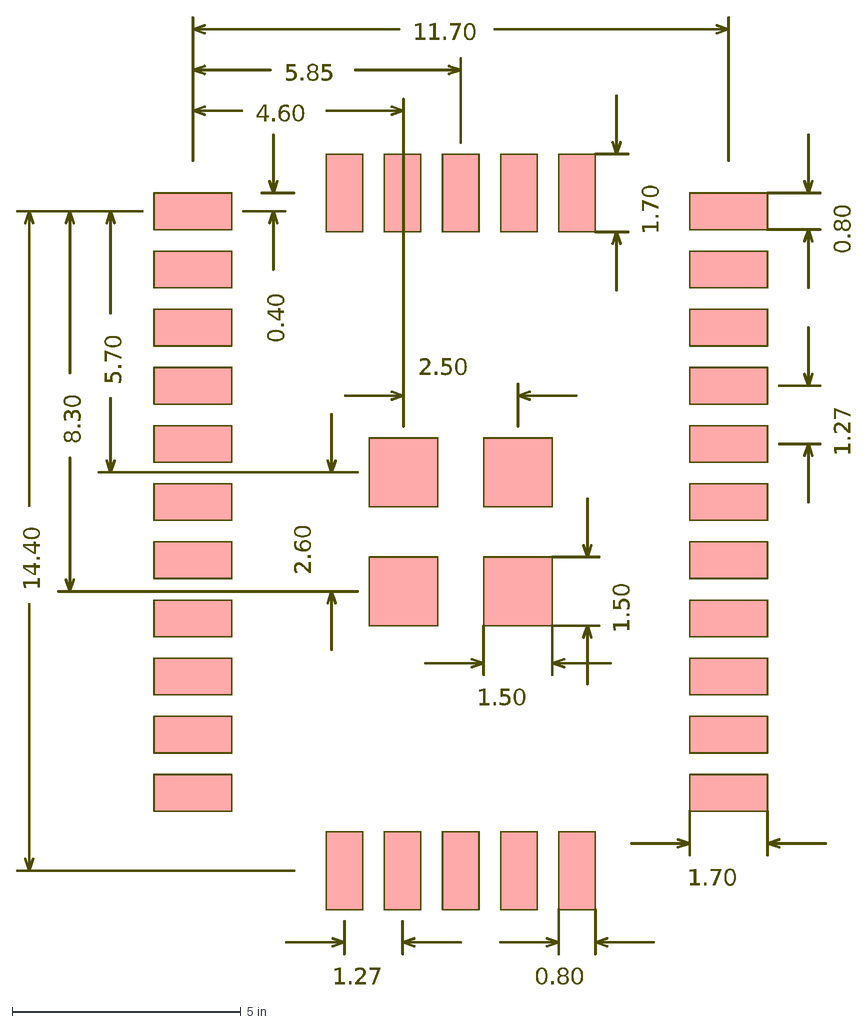
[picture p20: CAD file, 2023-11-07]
Products/IMX-6/IMX-6-1/PCB_Library/Altium/IS-IMX-6_recommended_layout.DXF
4.60
1.70
11.70
0.80
2.50
2.60
1.27
5.85
5.70
8.30
0.40
1.50
14.40

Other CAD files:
Products/IK-1/IK-1-2/3D_Model/IK-r1-2-IMX.step
Products/IK-1/IK-1-2/3D_Model/IK-r1-2-GPX.step

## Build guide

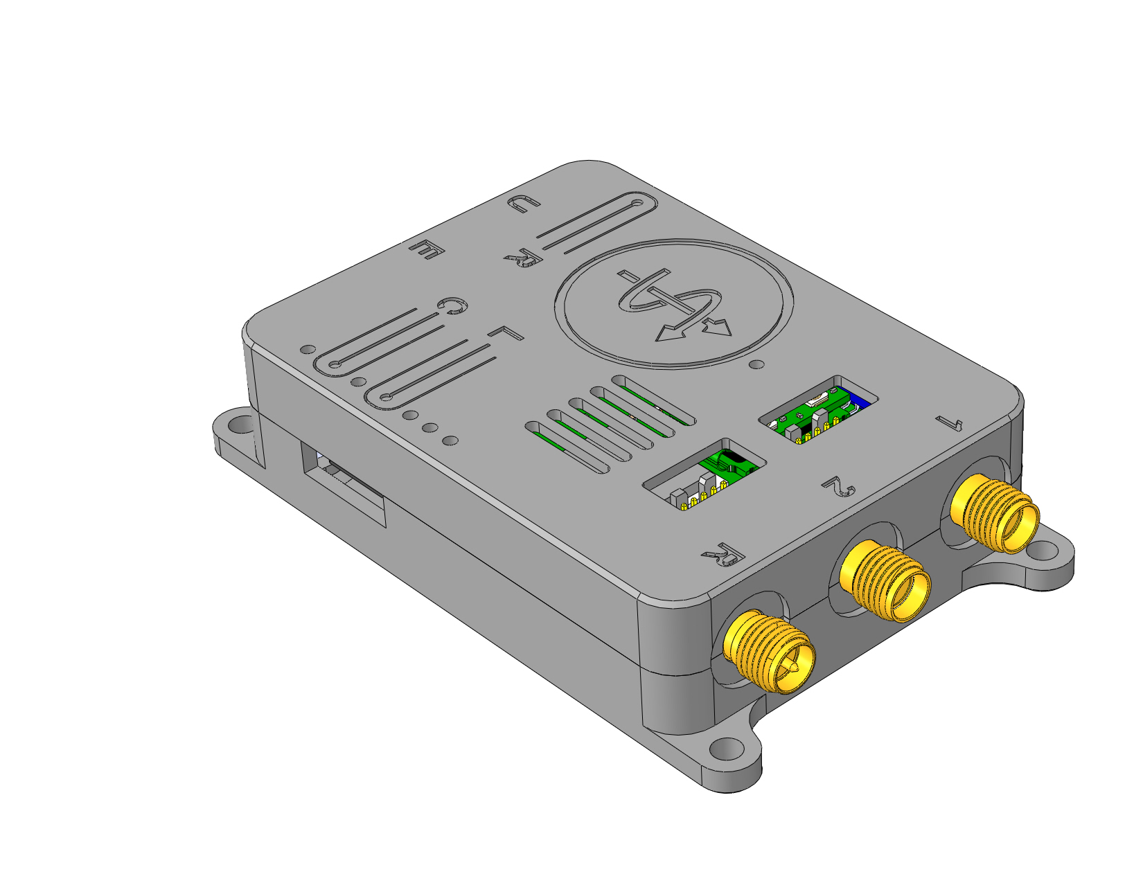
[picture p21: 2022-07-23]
Products/EVB-2/EVB-2-1/Images/EVB-2 Case Assembly shaded iso rf.jpg

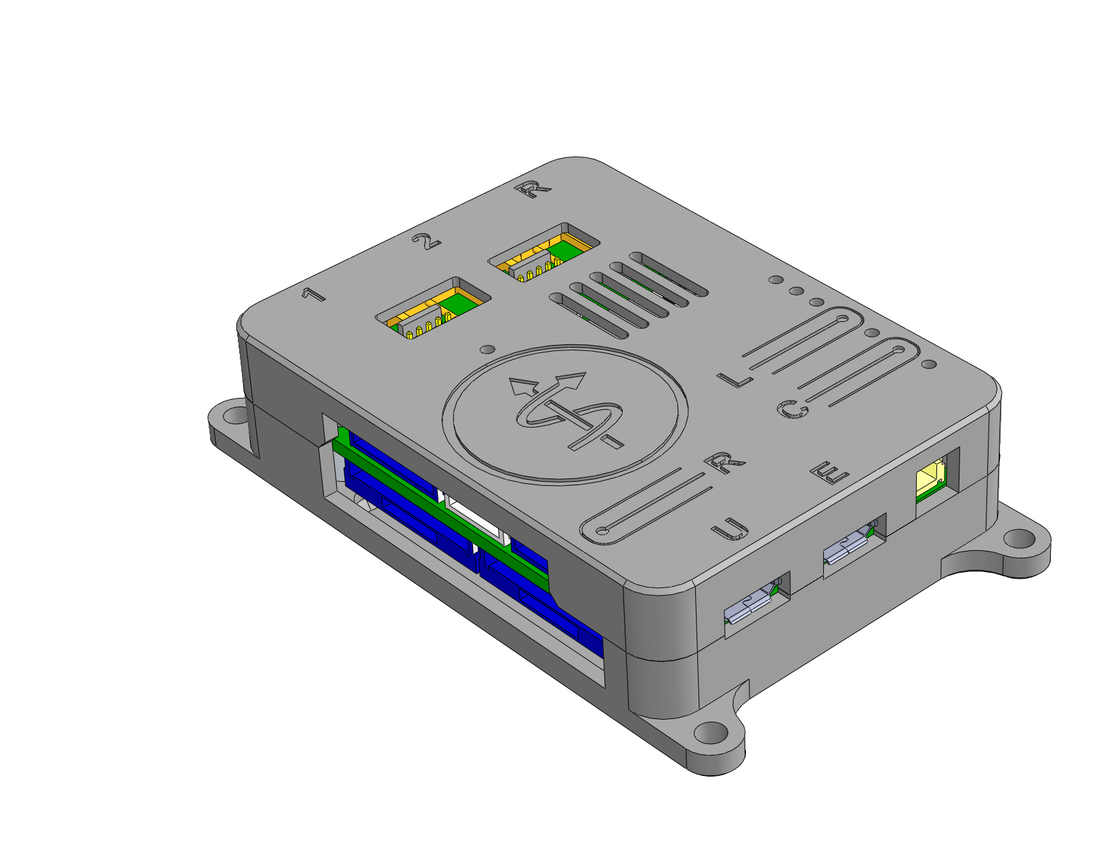
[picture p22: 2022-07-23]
Products/EVB-2/EVB-2-1/Images/EVB-2 Case Assembly shaded iso usb.jpg

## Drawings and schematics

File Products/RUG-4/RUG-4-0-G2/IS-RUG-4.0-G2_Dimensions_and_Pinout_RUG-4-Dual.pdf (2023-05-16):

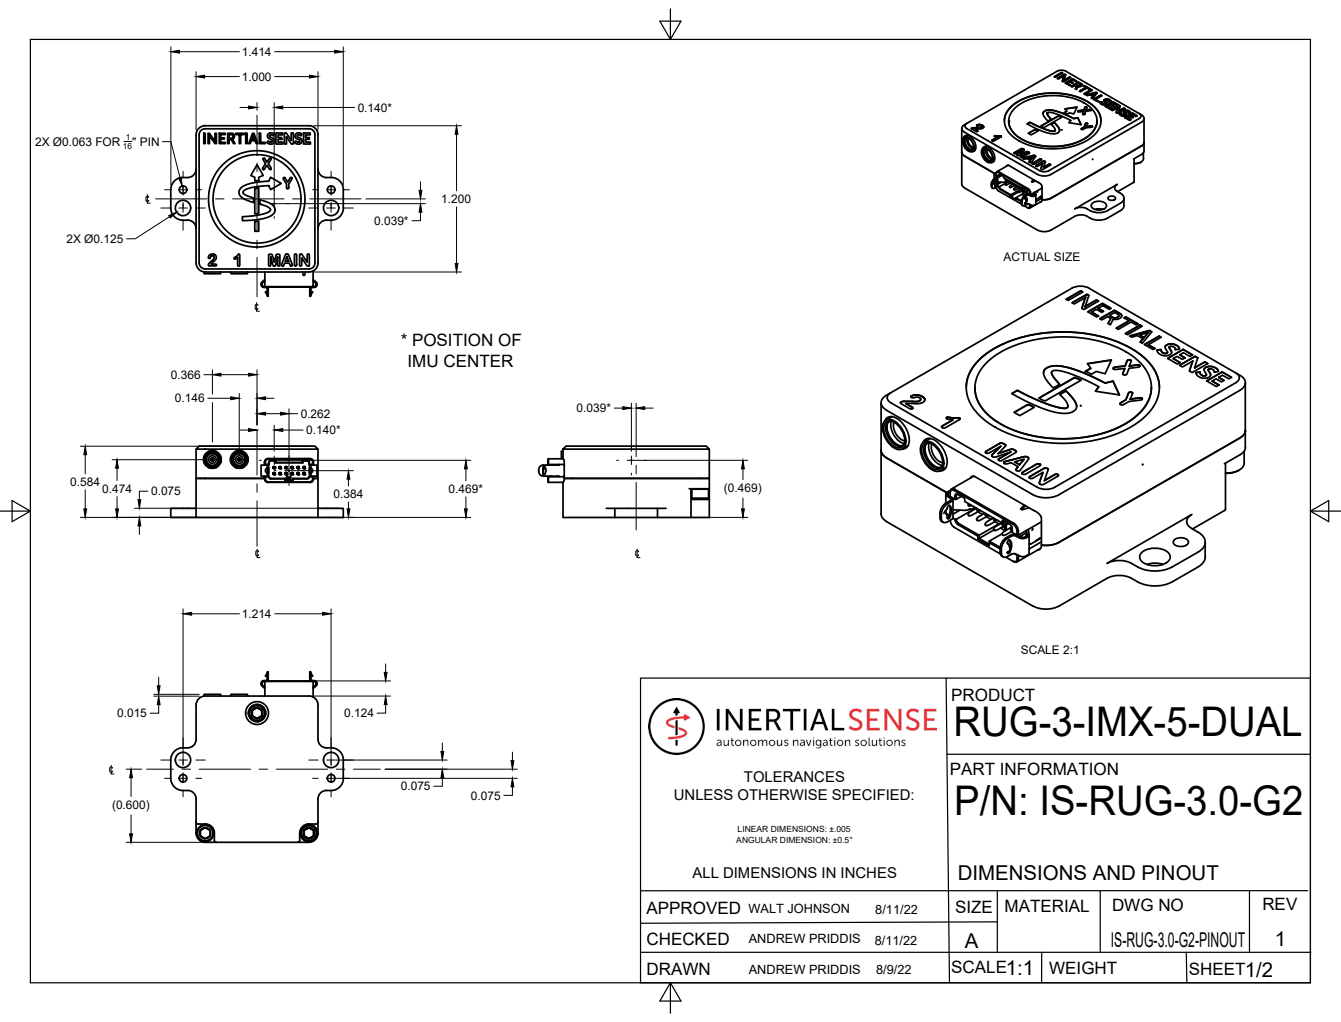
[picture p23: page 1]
2X Ø0.063 FOR 1 16" PIN; * POSITION OF IMU CENTER; ACTUAL SIZE; PART INFORMATION P/N: IS-RUG-3.0-G2

SCALE 2:1
RUG-3-IMX-5-DUAL

UNLESS OTHERWISE SPECIFIED: LINEAR DIMENSIONS: ±.005 ANGULAR DIMENSION: ±0.5° ALL DIMENSIONS IN INCHES

DIMENSIONS AND PINOUT

APPROVED WALT JOHNSON 8/11/22 | SIZE | MATERIAL | DWG NO IS-RUG-3.0-G2-PINOUT | REV 1

CHECKED ANDREW PRIDDIS 8/11/22 | A
ANDREW PRIDDIS 8/9/22 DRAWN | 1:1 SCALE | 1/2 WEIGHT SHEET

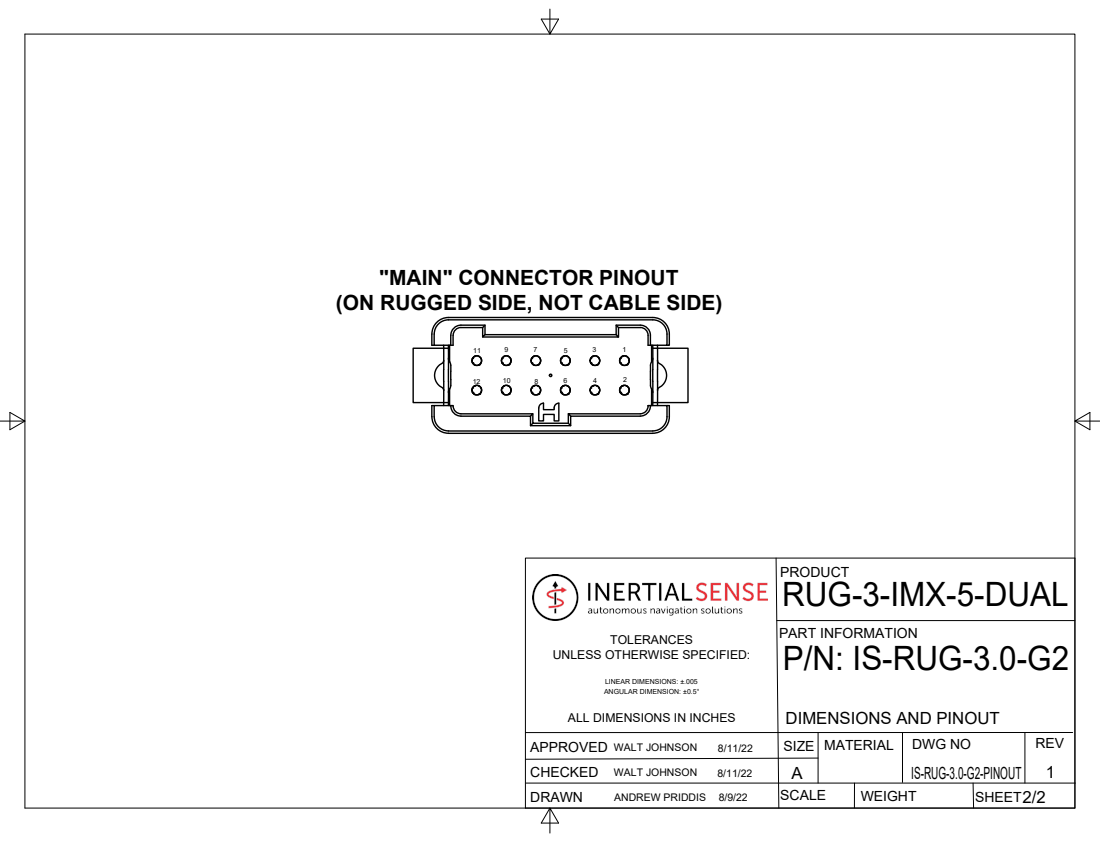
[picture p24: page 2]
PART INFORMATION P/N: IS-RUG-3.0-G2

"MAIN" CONNECTOR PINOUT
(ON RUGGED SIDE, NOT CABLE SIDE)

PRODUCT
RUG-3-IMX-5-DUAL

UNLESS OTHERWISE SPECIFIED: LINEAR DIMENSIONS: ±.005 ANGULAR DIMENSION: ±0.5° ALL DIMENSIONS IN INCHES

DIMENSIONS AND PINOUT

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

CHECKED WALT JOHNSON 8/11/22 | A
DRAWN ANDREW PRIDDIS 8/9/22 | SCALE | WEIGHT SHEET 2/2

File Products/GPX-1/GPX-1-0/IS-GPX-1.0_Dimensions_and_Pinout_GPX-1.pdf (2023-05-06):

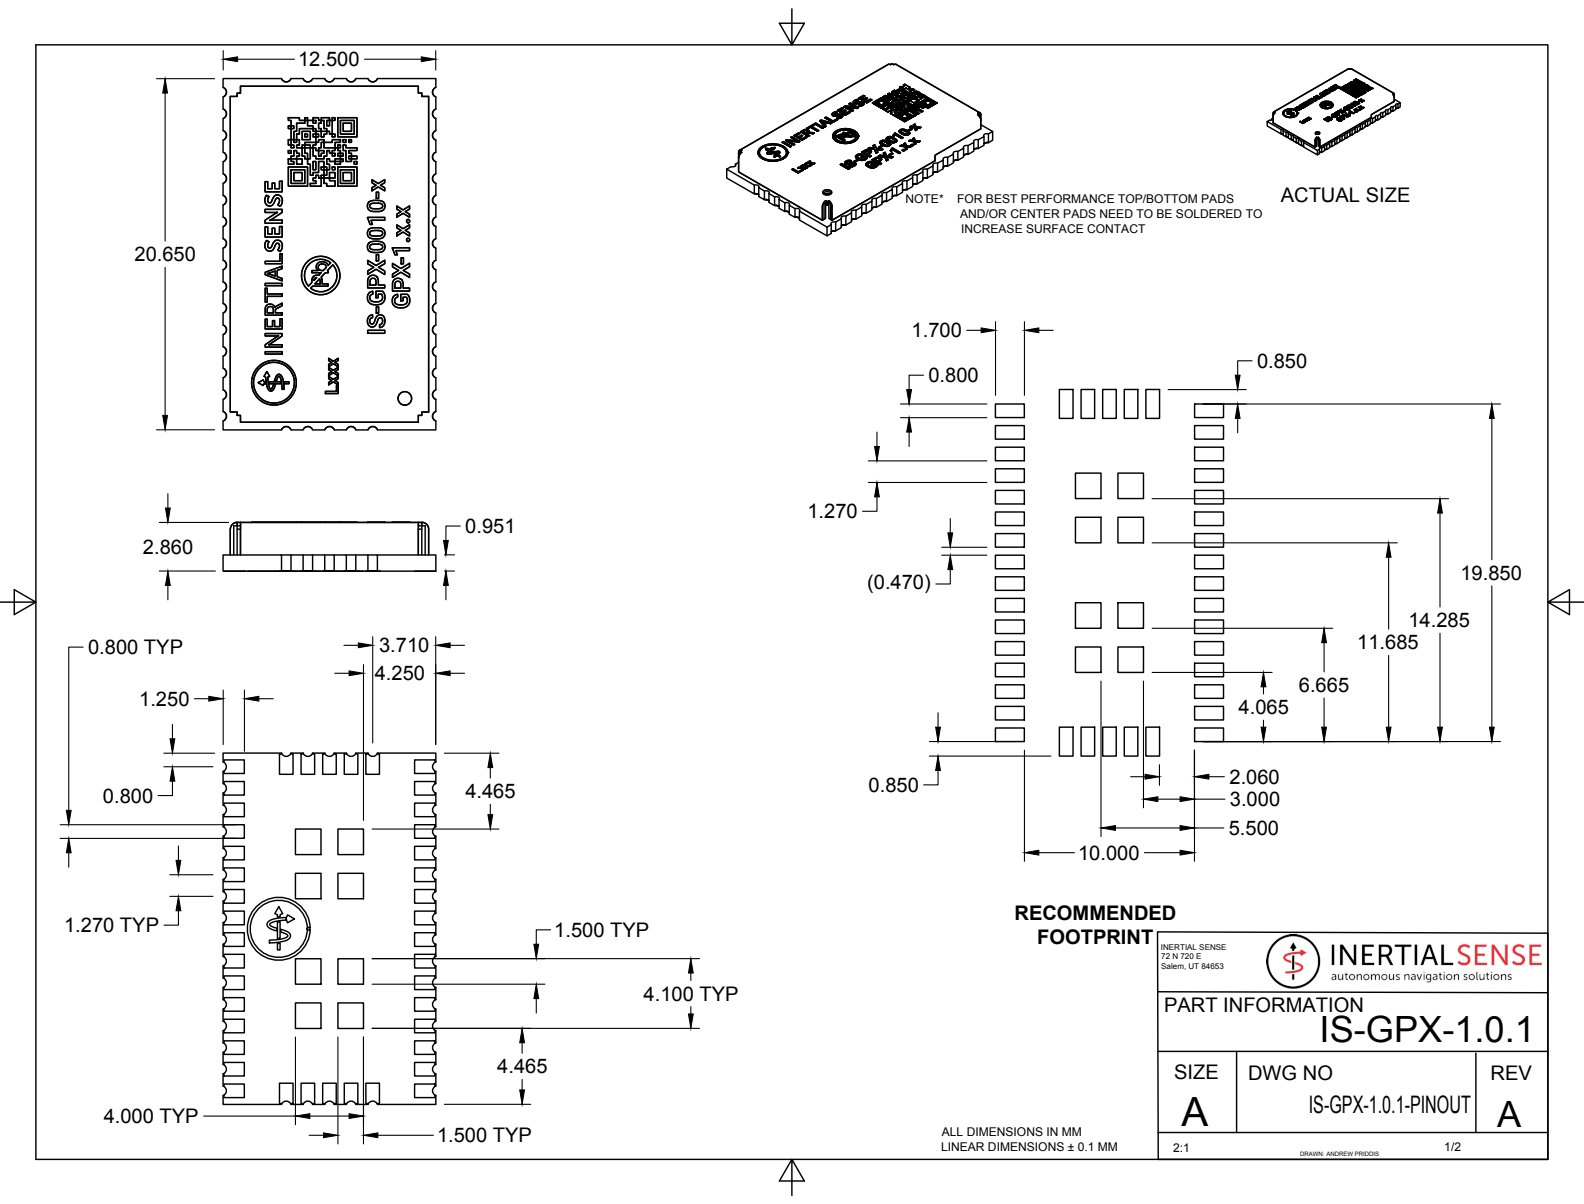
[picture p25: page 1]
PART INFORMATION; SIZE; DWG NO; REV; INERTIAL SENSE 72 N 720 E Salem, UT 84653; IS-GPX-1.0.1-PINOUT A; ACTUAL SIZE; 0.800 TYP; 1.270 TYP; 1.500 TYP; 4.100 TYP; 4.000 TYP

NOTE* FOR BEST PERFORMANCE TOP/BOTTOM PADS

AND/OR CENTER PADS NEED TO BE SOLDERED TO
INCREASE SURFACE CONTACT

ALL DIMENSIONS IN MM
LINEAR DIMENSIONS ± 0.1 MM

DRAWN: ANDREW PRIDDIS

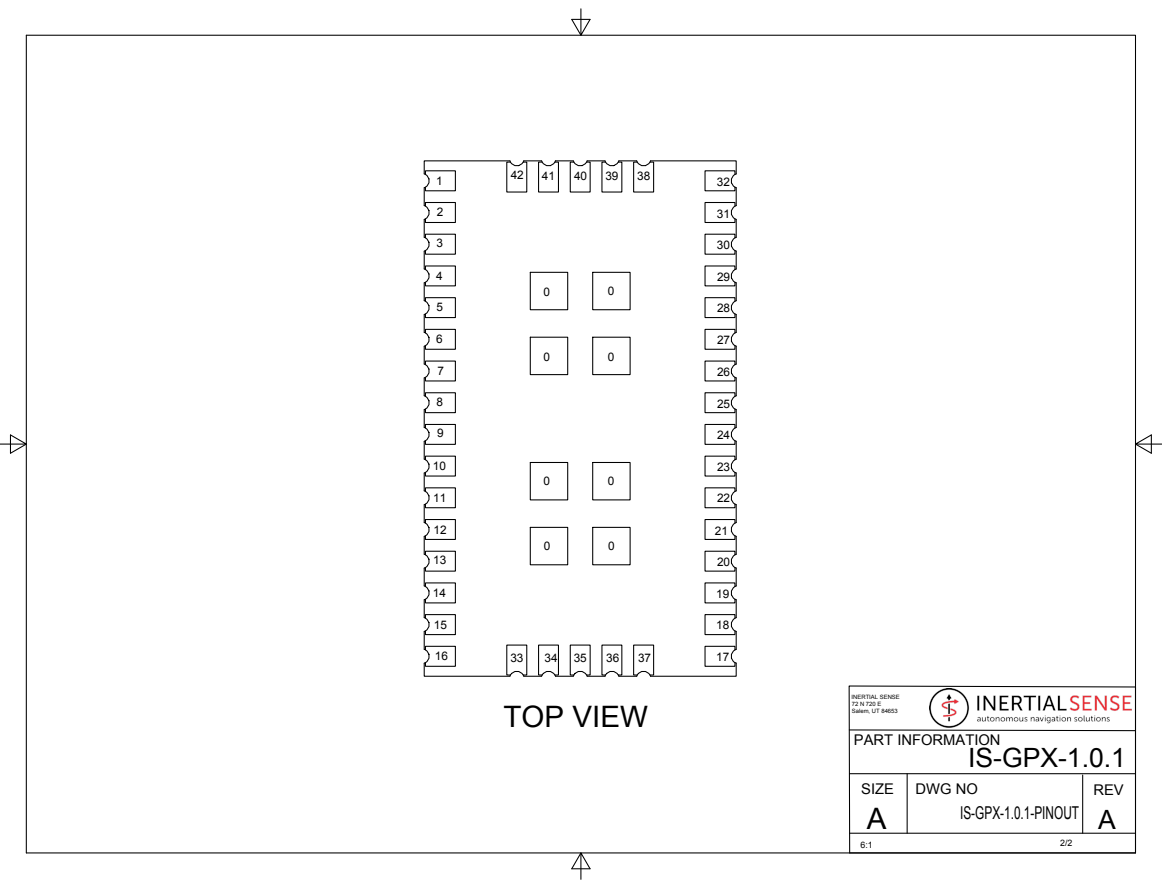
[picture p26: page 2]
PART INFORMATION; SIZE; DWG NO; REV; INERTIAL SENSE 72 N 720 E Salem, UT 84653; TOP VIEW

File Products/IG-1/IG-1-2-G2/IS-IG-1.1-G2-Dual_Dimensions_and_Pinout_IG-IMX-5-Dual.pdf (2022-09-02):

3.33*

## *POSITION OF IMU

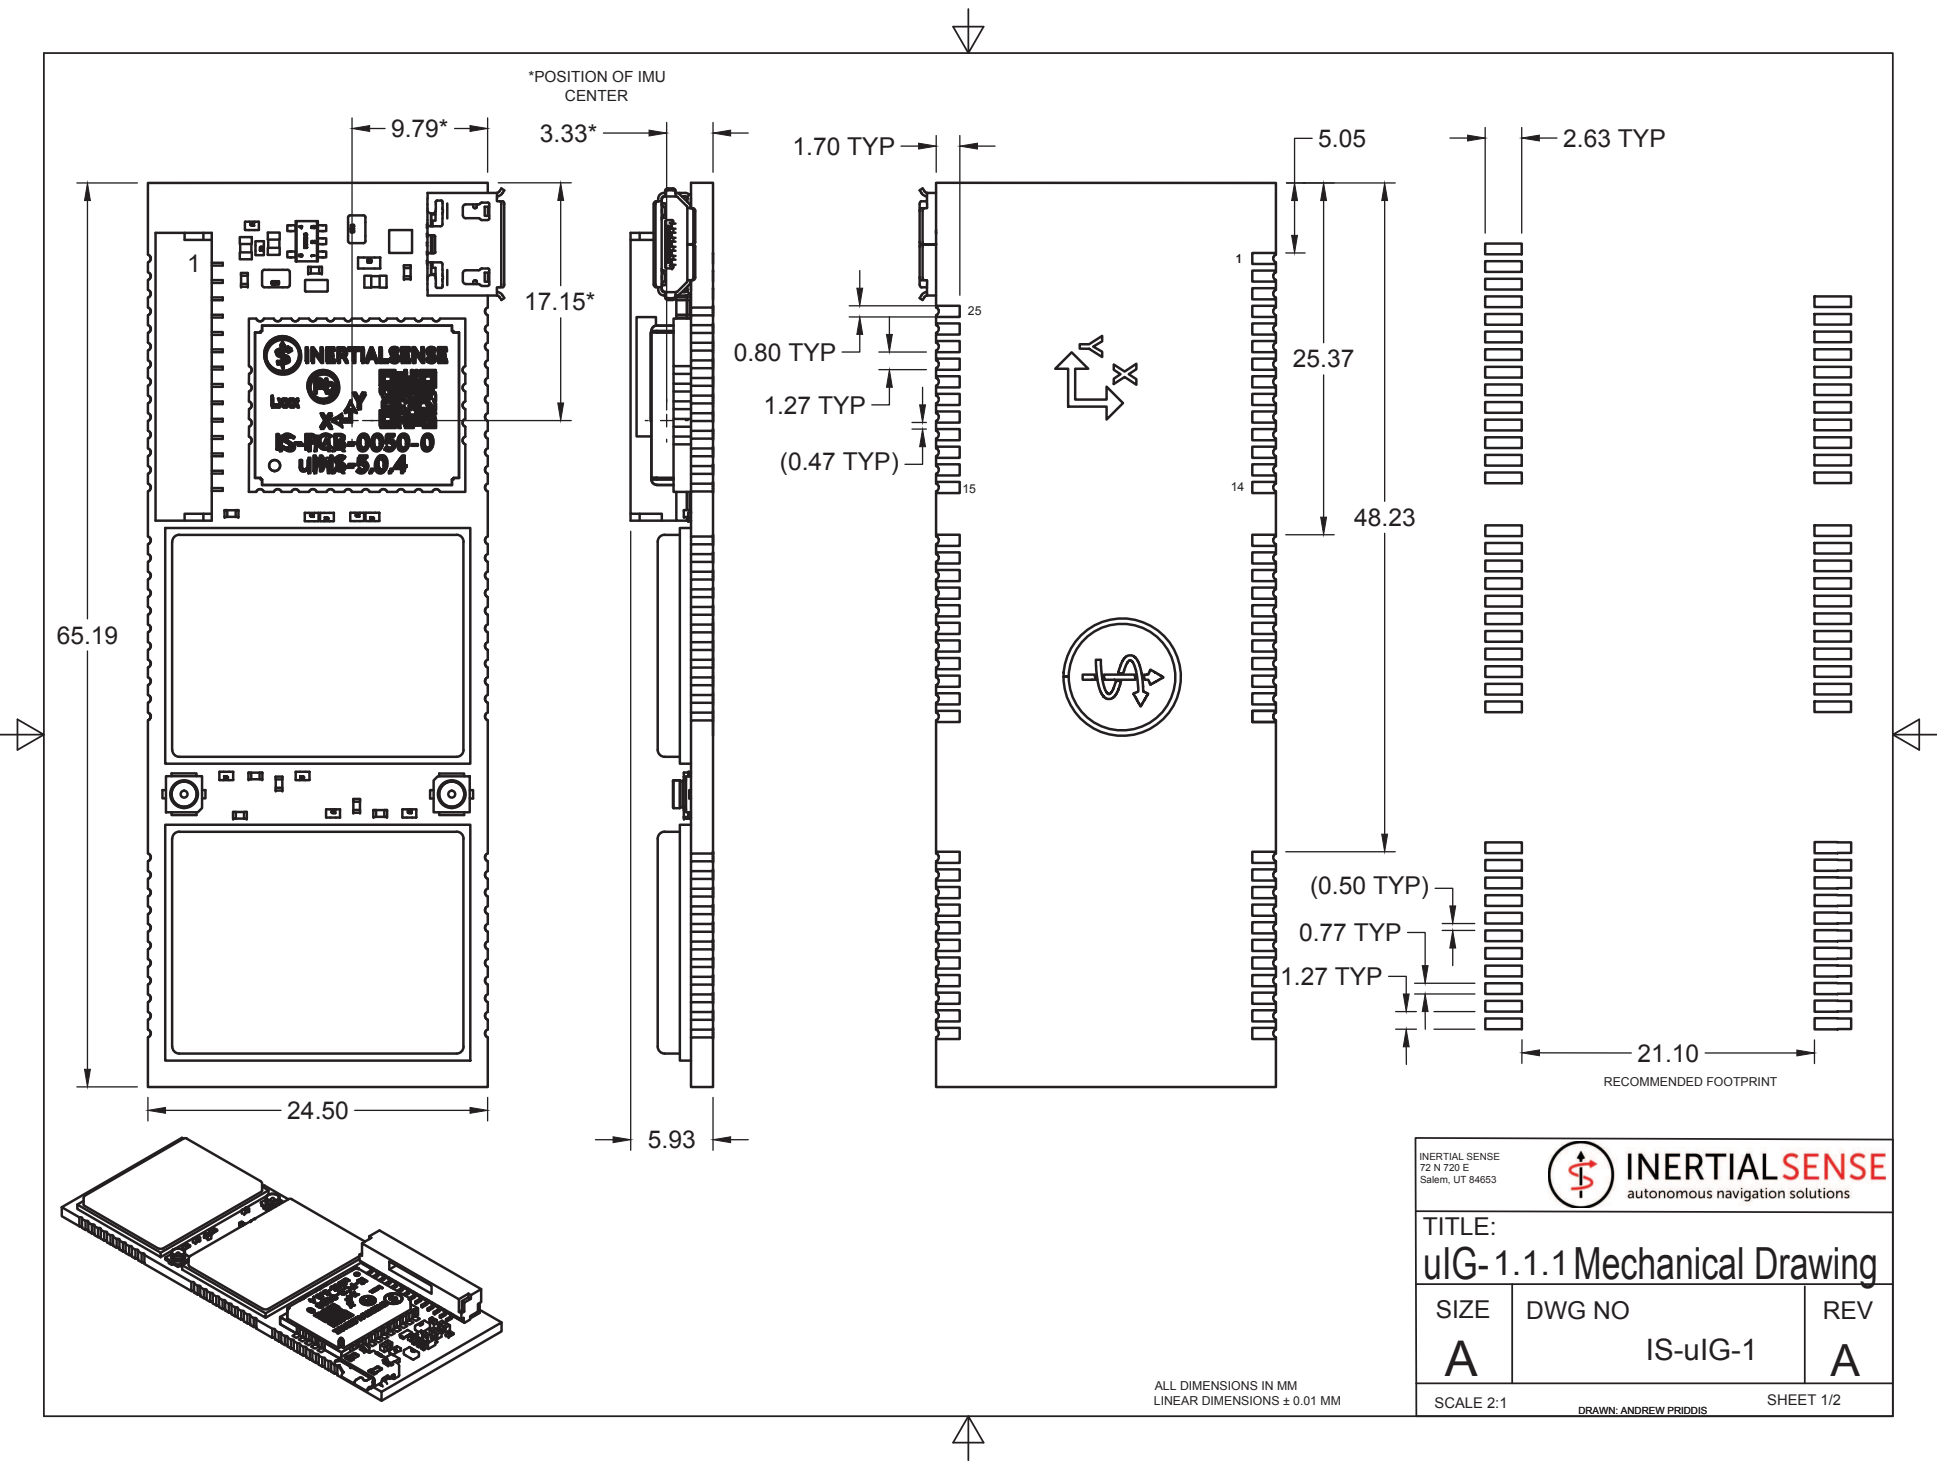
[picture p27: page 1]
TITLE:; SIZE; DWG NO; REV; INERTIAL SENSE 72 N 720 E Salem, UT 84653; SCALE 2:1; SHEET 1/2; IS-uIG-1; uIG-1.0.3 Mechanical Drawing; CENTER; 1.70 TYP; 0.80 TYP; 1.27 TYP; (0.47 TYP); RECOMMENDED FOOTPRINT; 2.63 TYP; (0.50 TYP); 0.77 TYP

ALL DIMENSIONS IN MM
LINEAR DIMENSIONS ± 0.01 MM

DRAWN: ANDREW PRIDDISDRAWN: ANDREW PRIDDIS

# TOP VIEW

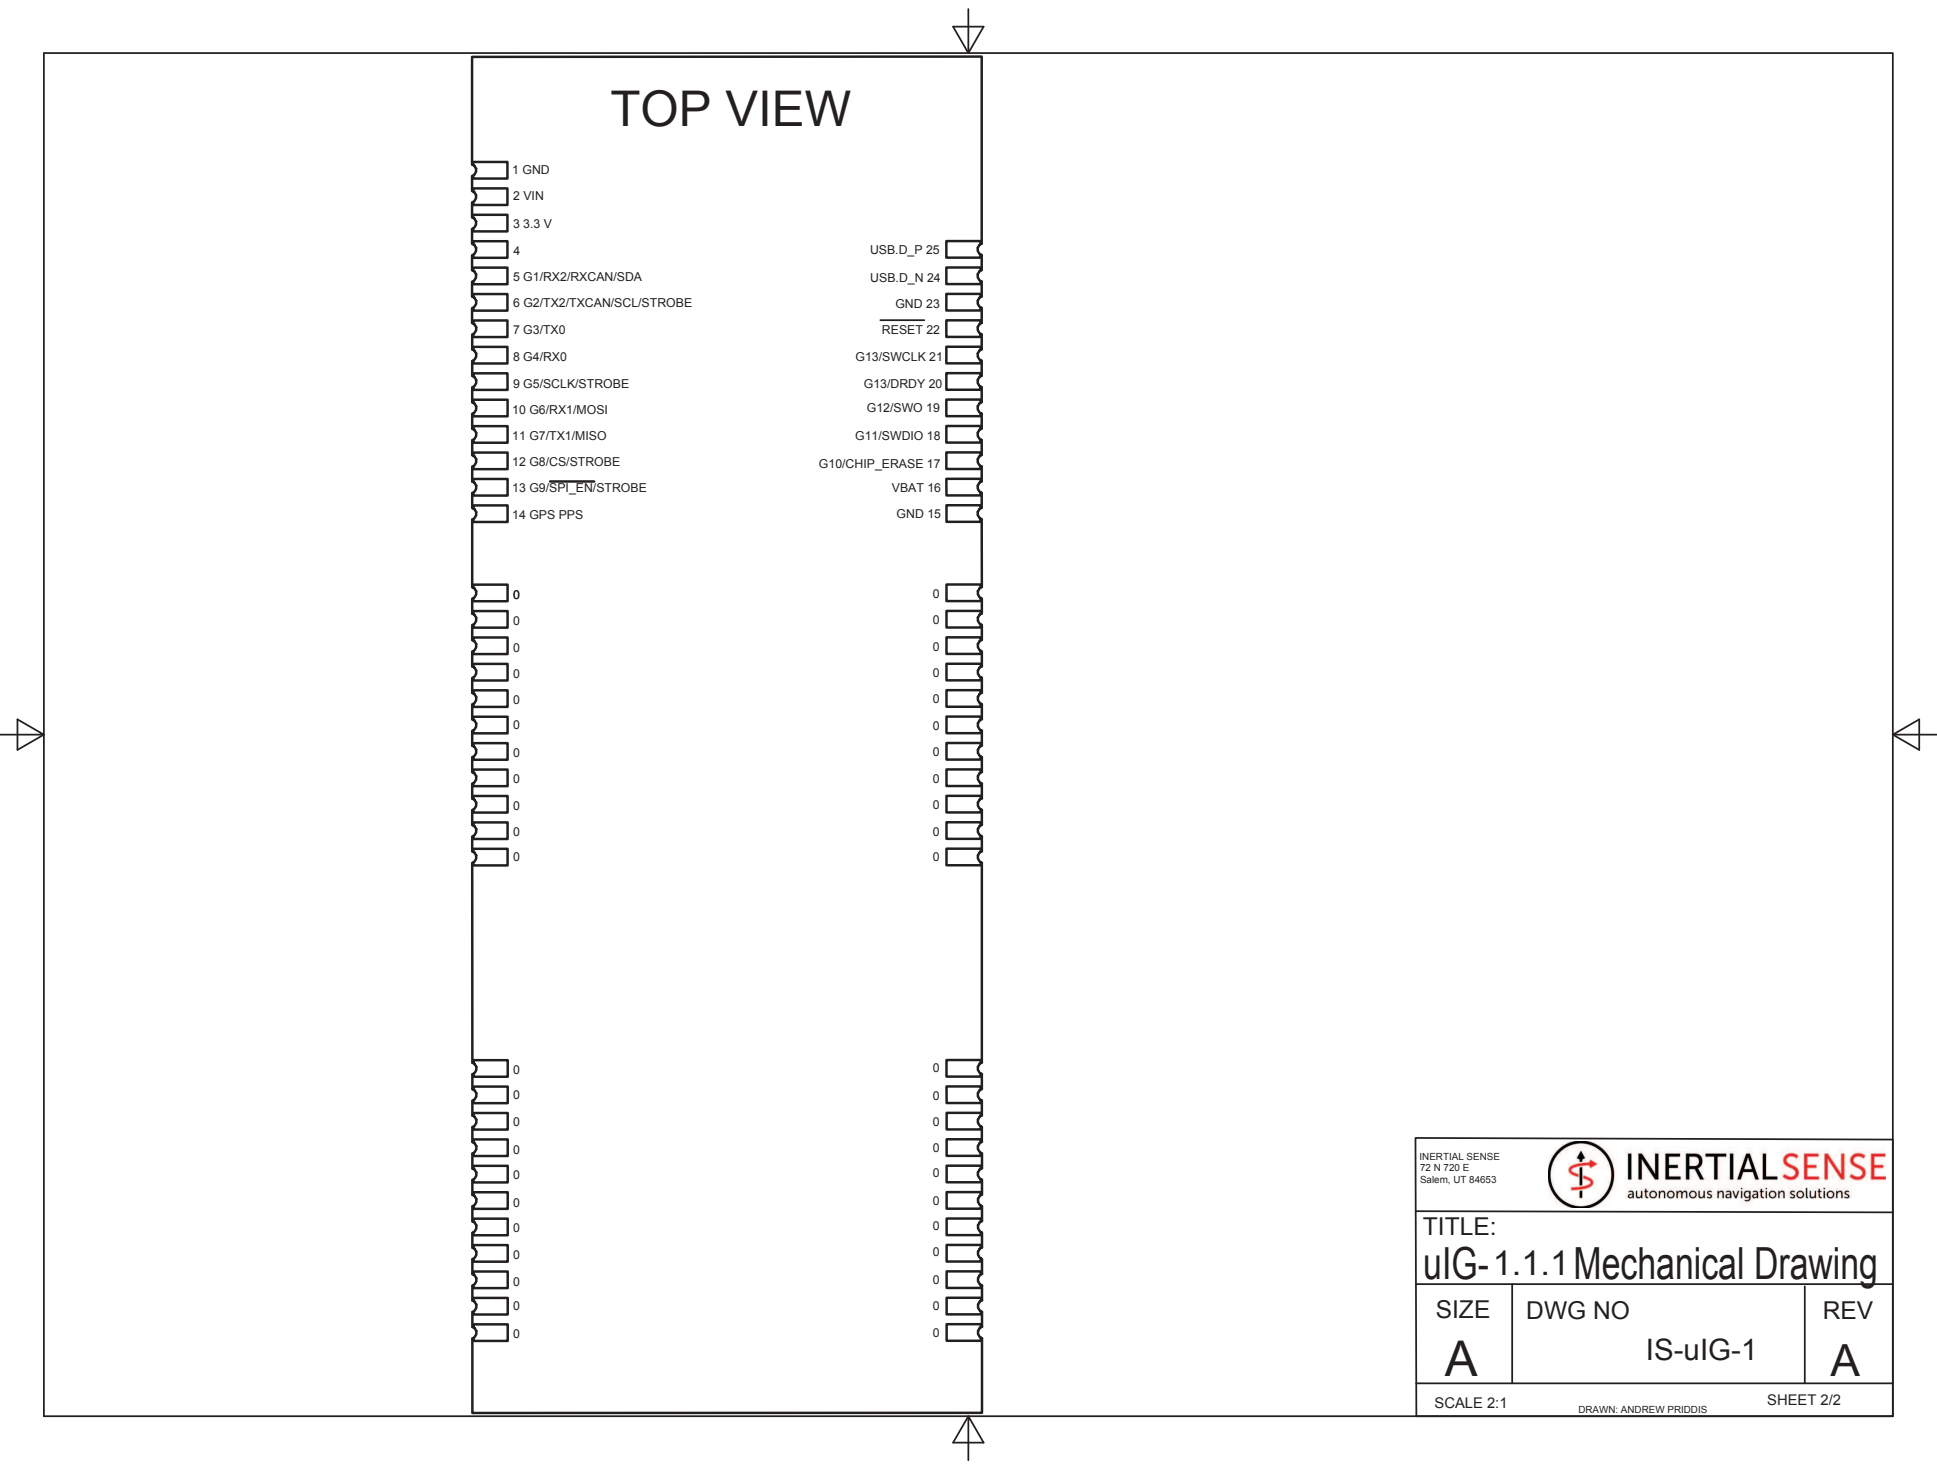
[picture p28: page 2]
TITLE:; SIZE; DWG NO; REV; INERTIAL SENSE 72 N 720 E Salem, UT 84653; SCALE 2:1; SHEET 2/2; IS-uIG-1; uIG-1.0.3 Mechanical Drawing; 1 GND; 2 VIN; 4 GPS_RESET _N; 5 G1/RX2/RXCAN/SDA; 9 G5/SCLK/STROBE; 10 G6/RX1/MOSI; 11 G7/TX1/MISO; 12 G8/CS/STROBE; 13 G9/SPI_EN/STROBE; 14 GPS PPS; USB.D_P 25; USB.D_N 24; GND 23; RESET 22; G13/SWCLK 21; G13/DRDY 20; G12/SWO 19; G11/SWDIO 18; G10/CHIP_ERASE 17; VBAT 16; GND 15

6 G2/TX2/TXCAN/SCL/STROBE

DRAWN: ANDREW PRIDDIS

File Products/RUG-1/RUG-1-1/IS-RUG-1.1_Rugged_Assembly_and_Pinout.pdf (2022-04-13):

### ACTUAL SIZE

CL

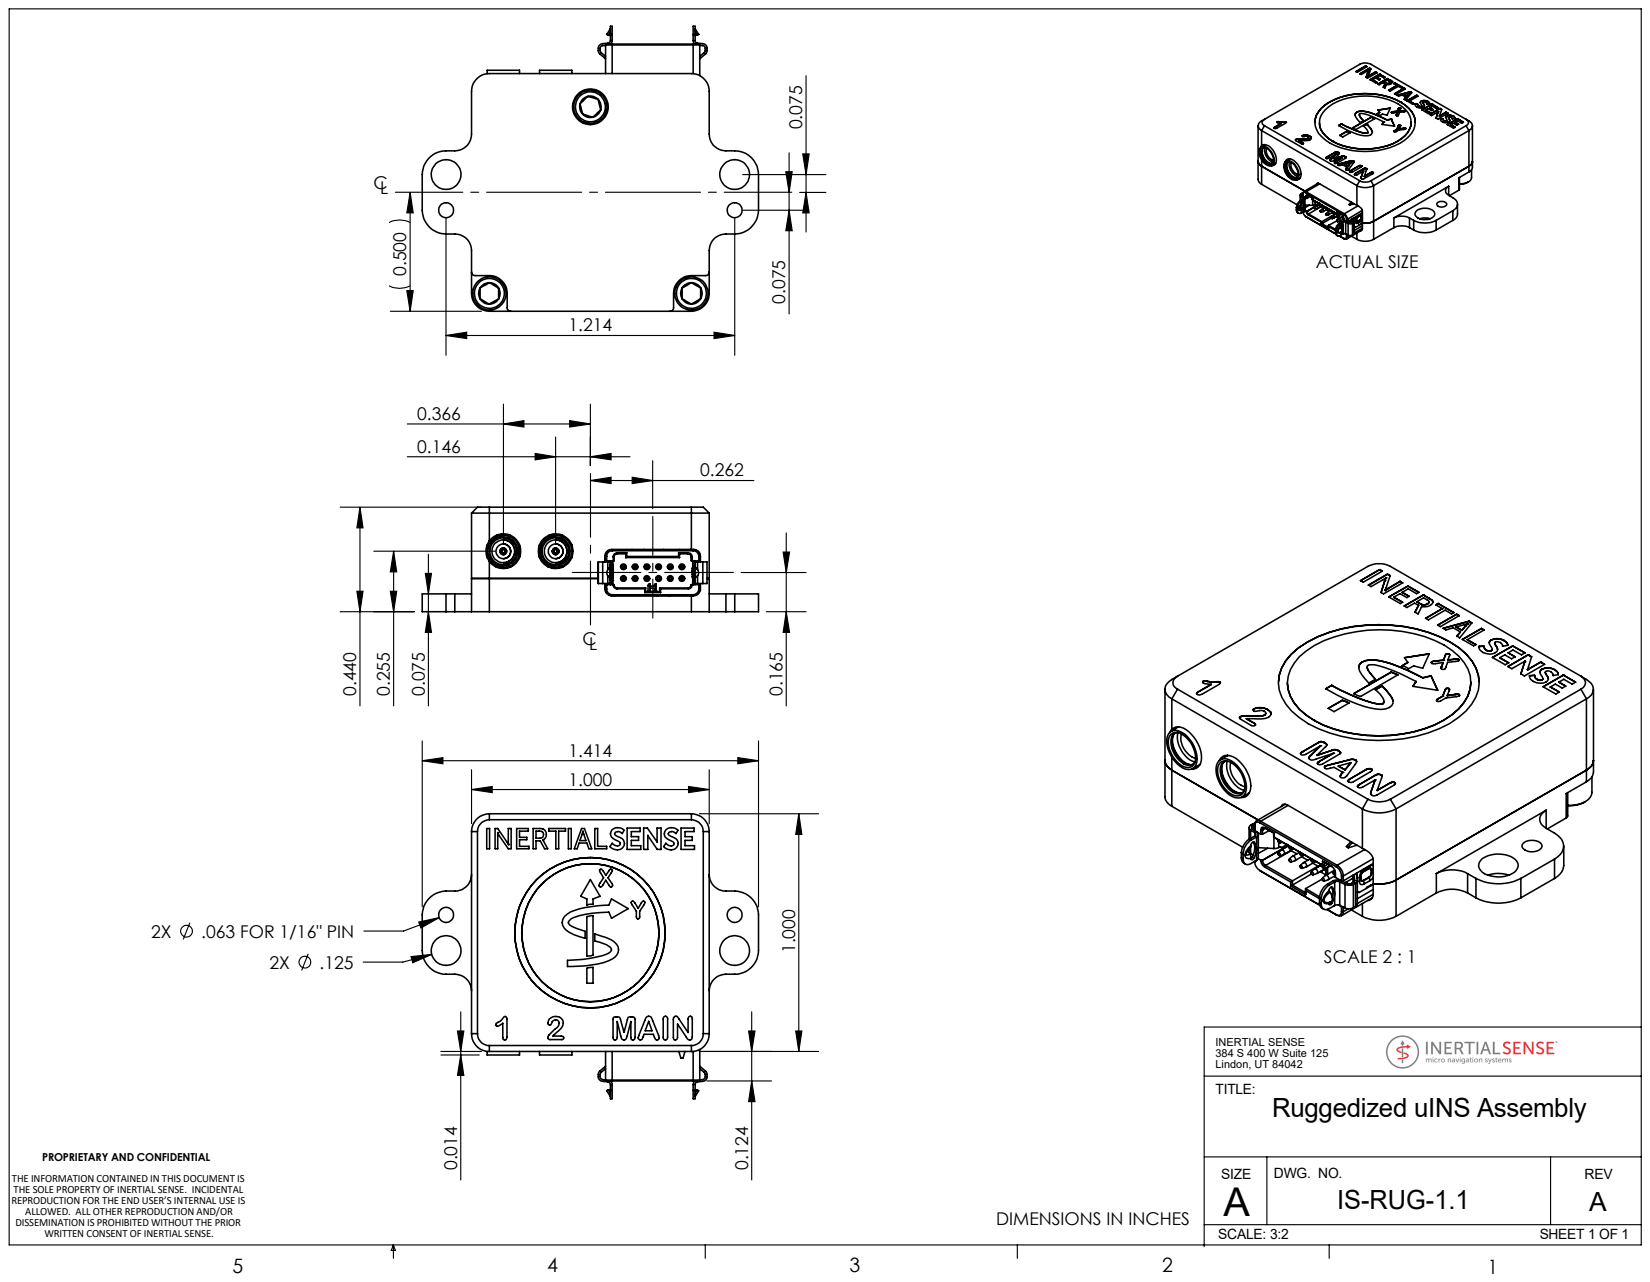
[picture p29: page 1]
.063 FOR 1/16" PIN; SCALE 2 : 1; IS-RUG-1.1; SCALE: 3:2; SHEET 1 OF 1; DWG. NO.; REV; SIZE

INERTIAL SENSE
384 S 400 W Suite 125
Lindon, UT 84042
TITLE:
Ruggedized uINS Assembly

PROPRIETARY AND CONFIDENTIAL

THE INFORMATION CONTAINED IN THIS DOCUMENT IS
THE SOLE PROPERTY OF INERTIAL SENSE. INCIDENTAL
REPRODUCTION FOR THE END USER’S INTERNAL USE IS
ALLOWED. ALL OTHER REPRODUCTION AND/OR
DISSEMINATION IS PROHIBITED WITHOUT THE PRIOR
WRITTEN CONSENT OF INERTIAL SENSE.

DIMENSIONS IN INCHES

## “MAIN” Connector Pinout

### (on Rugged side, not cable side)

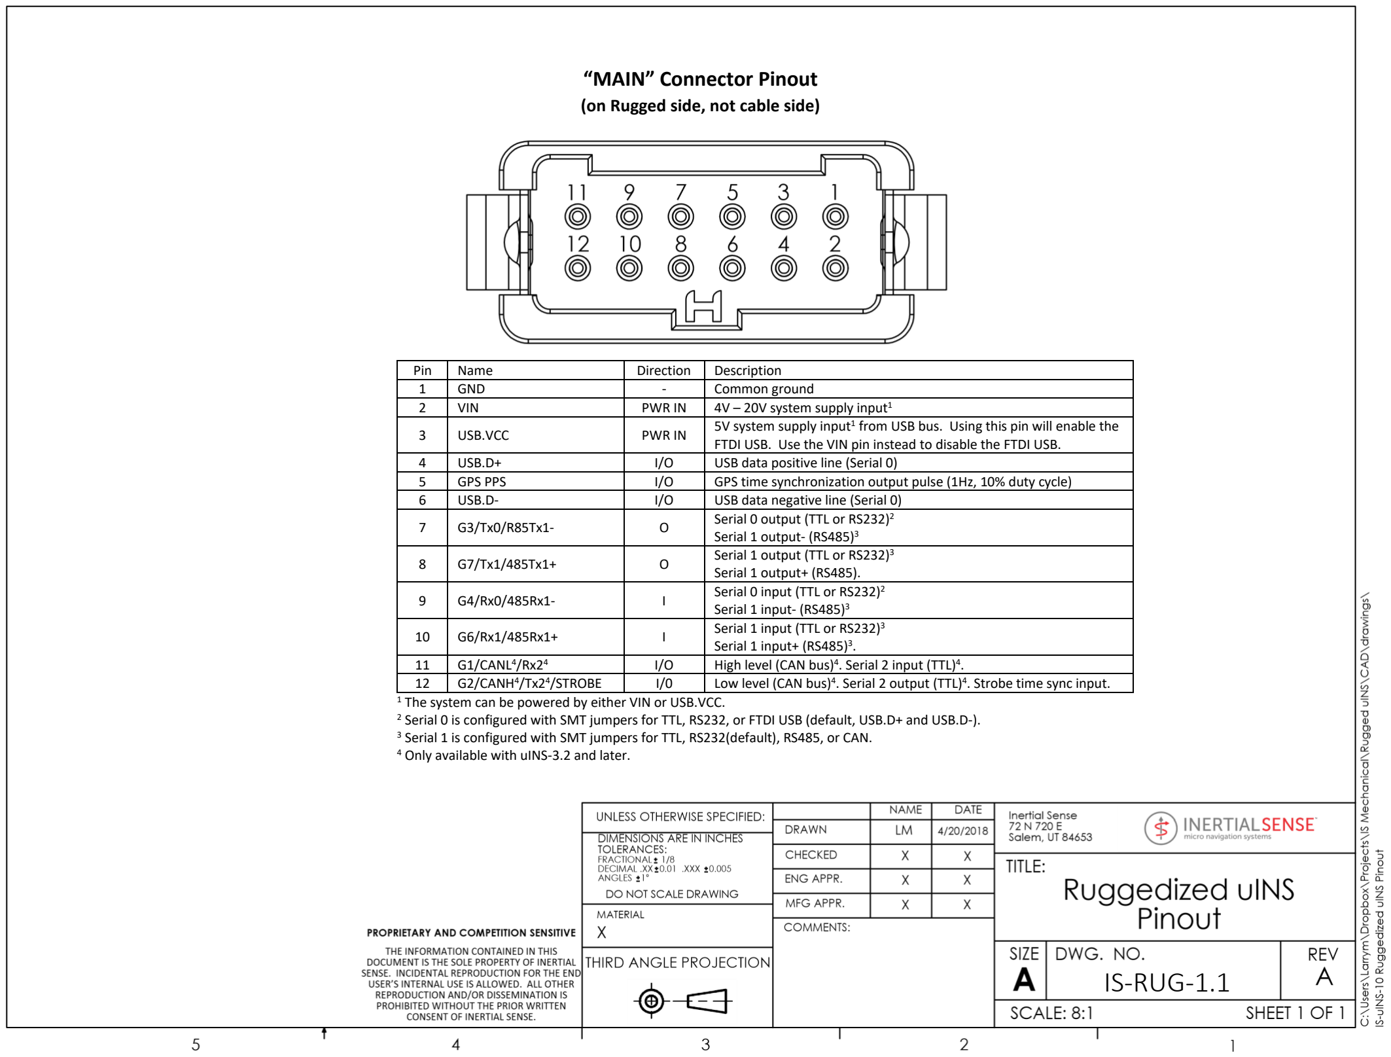
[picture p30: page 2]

Pin | Name | Direction | Description
1 | GND | - | Common ground
2 | VIN | PWR IN | 4V – 20V system supply input¹
3 | USB.VCC | PWR IN | 5V system supply input¹ from USB bus. Using this pin will enable the FTDI USB. Use the VIN pin instead to disable the FTDI USB.
4 | USB.D+ | I/O | USB data positive line (Serial 0)
5 | GPS PPS | I/O | GPS time synchronization output pulse (1Hz, 10% duty cycle)
6 | USB.D- | I/O | USB data negative line (Serial 0)
7 | G3/Tx0/R85Tx1- | O | Serial 0 output (TTL or RS232) 2 Serial 1 output- (RS485)³
8 | G7/Tx1/485Tx1+ | O | Serial 1 output (TTL or RS232) 3 Serial 1 output+ (RS485).
9 | G4/Rx0/485Rx1- | I | 2 Serial 0 input (TTL or RS232) Serial 1 input- (RS485) 3
10 | G6/Rx1/485Rx1+ | I | Serial 1 input (TTL or RS232) 3 Serial 1 input+ (RS485)³ .
11 | G1/CANL⁴ /Rx2⁴ | I/O | High level (CAN bus)⁴ . Serial 2 input (TTL)⁴ .
12 | G2/CANH⁴ /Tx2⁴ /STROBE | I/0 | Low level (CAN bus)⁴ . Serial 2 output (TTL)⁴ . Strobe time sync input.
1 The system can be powered by either VIN or USB.VCC.
2 Serial 0 is configured with SMT jumpers for TTL, RS232, or FTDI USB (default, USB.D+ and USB.D-).
3 Serial 1 is configured with SMT jumpers for TTL, RS232(default), RS485, or CAN.
4 Only available with uINS-3.2 and later.

# IS-RUG-1.1

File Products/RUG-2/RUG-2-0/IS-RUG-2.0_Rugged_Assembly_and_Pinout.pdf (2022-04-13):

### ACTUAL SIZE

CL

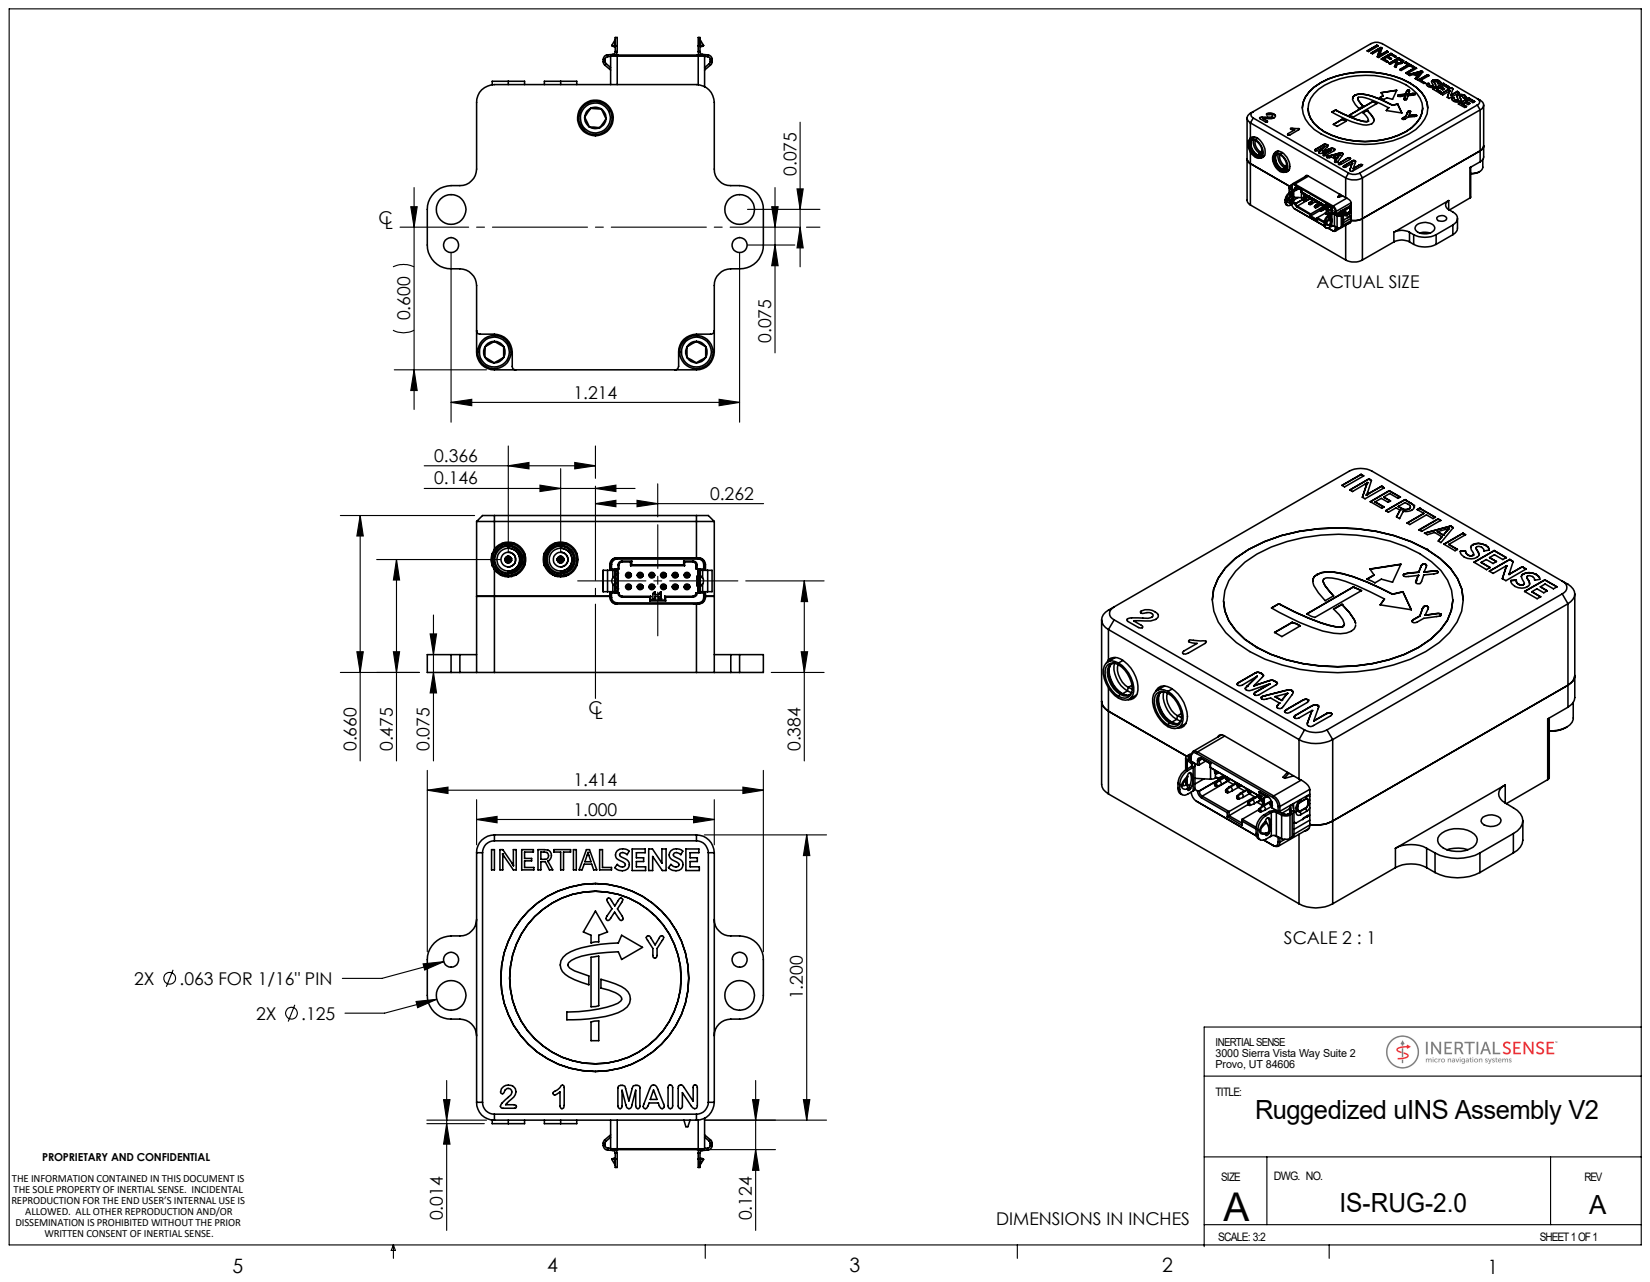
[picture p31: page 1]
2X .063 FOR 1/16" PIN; SCALE 2 : 1; IS-RUG-2.0; SCALE: 3:2; SHEET 1 OF 1; DWG. NO.; REV; SIZE; TITLE:

INERTIAL SENSE
3000 Sierra Vista Way Suite 2
Provo, UT 84606
Ruggedized uINS Assembly V2

PROPRIETARY AND CONFIDENTIAL

THE INFORMATION CONTAINED IN THIS DOCUMENT IS
THE SOLE PROPERTY OF INERTIAL SENSE. INCIDENTAL
REPRODUCTION FOR THE END USER’S INTERNAL USE IS
ALLOWED. ALL OTHER REPRODUCTION AND/OR
DISSEMINATION IS PROHIBITED WITHOUT THE PRIOR
WRITTEN CONSENT OF INERTIAL SENSE.

DIMENSIONS IN INCHES

## “MAIN” Connector Pinout

### (on Rugged side, not cable side)

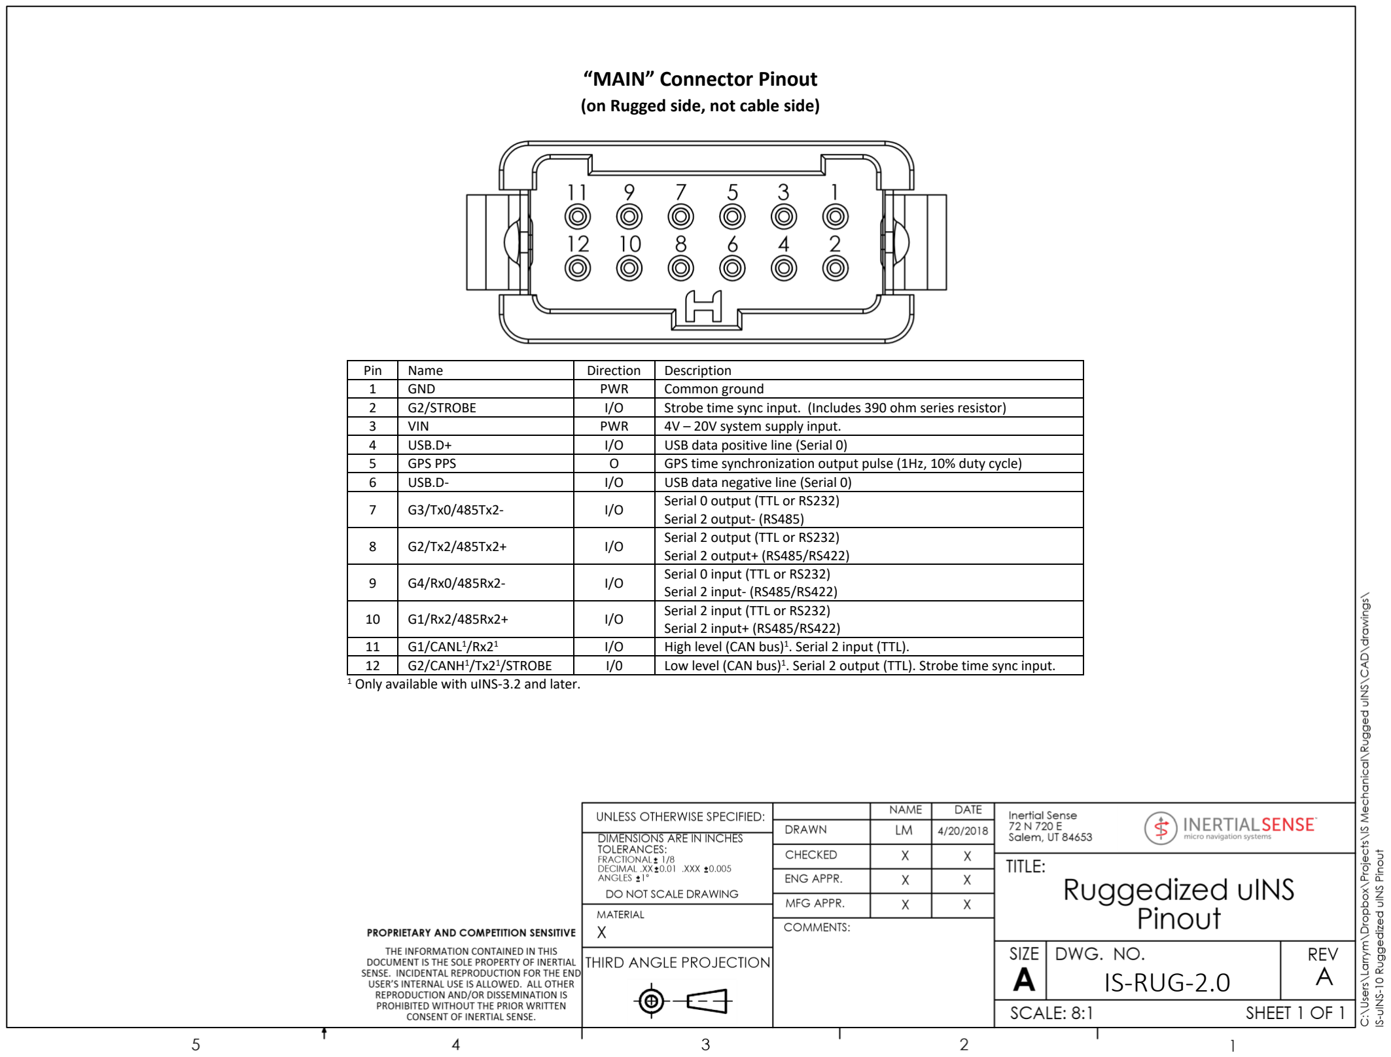
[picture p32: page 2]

Pin | Name | Direction | Description
1 | GND | PWR | Common ground
2 | G2/STROBE | I/O | Strobe time sync input. (Includes 390 ohm series resistor)
3 | VIN | PWR | 4V – 20V system supply input.
4 | USB.D+ | I/O | USB data positive line (Serial 0)
5 | GPS PPS | O | GPS time synchronization output pulse (1Hz, 10% duty cycle)
6 | USB.D- | I/O | USB data negative line (Serial 0)
7 | G3/Tx0/485Tx2- | I/O | Serial 0 output (TTL or RS232) Serial 2 output- (RS485)
8 | G2/Tx2/485Tx2+ | I/O | Serial 2 output (TTL or RS232) Serial 2 output+ (RS485/RS422)
9 | G4/Rx0/485Rx2- | I/O | Serial 0 input (TTL or RS232) Serial 2 input- (RS485/RS422)
10 | G1/Rx2/485Rx2+ | I/O | Serial 2 input (TTL or RS232) Serial 2 input+ (RS485/RS422)
11 | G1/CANL¹ /Rx2¹ | I/O | High level (CAN bus)¹ . Serial 2 input (TTL).
12 | G2/CANH¹ /Tx2¹ /STROBE | I/0 | Low level (CAN bus)¹ . Serial 2 output (TTL). Strobe time sync input.
1 Only available with uINS-3.2 and later.

# IS-RUG-2.0

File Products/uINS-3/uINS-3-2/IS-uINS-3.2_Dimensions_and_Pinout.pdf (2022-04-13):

0.81

0.46

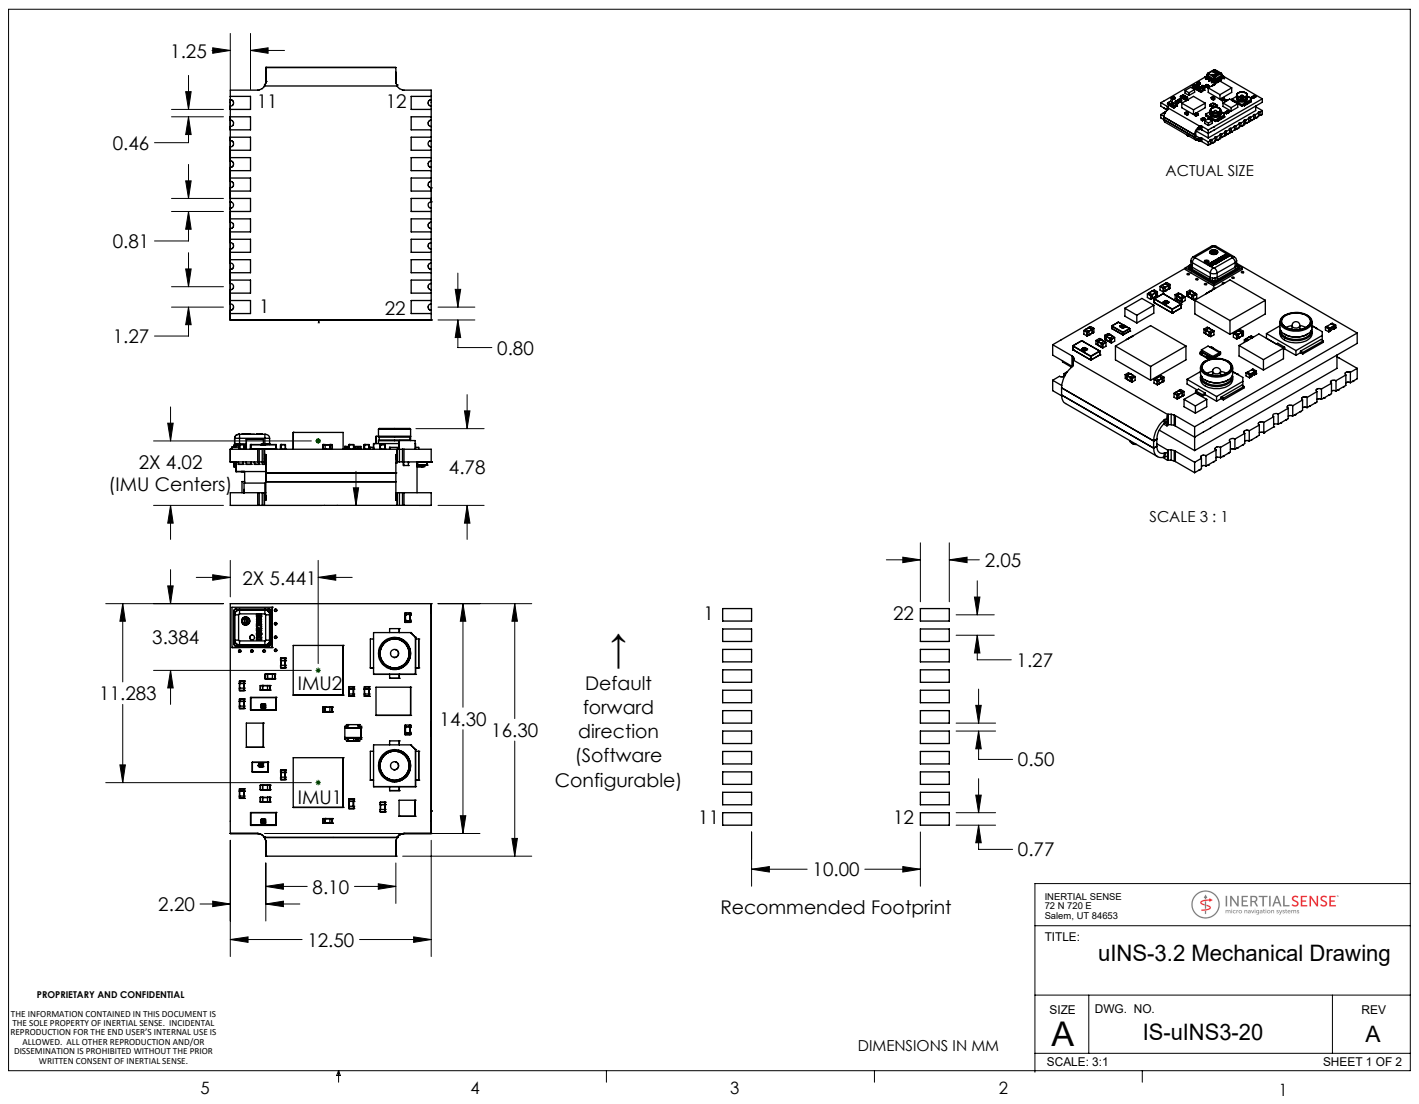
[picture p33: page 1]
IMU2; IMU1; 2X 4.02 (IMU Centers); ACTUAL SIZE; SCALE 3 : 1; Recommended Footprint; Default forward direction (Software Configurable); IS-uINS3-20; SCALE: 3:1; SHEET 1 OF 2; DWG. NO.; REV; SIZE

INERTIAL SENSE
Salem, UT 84653
TITLE:
uINS-3.2 Mechanical Drawing

PROPRIETARY AND CONFIDENTIAL

THE INFORMATION CONTAINED IN THIS DOCUMENT IS
THE SOLE PROPERTY OF INERTIAL SENSE. INCIDENTAL
REPRODUCTION FOR THE END USER’S INTERNAL USE IS
ALLOWED. ALL OTHER REPRODUCTION AND/OR
DISSEMINATION IS PROHIBITED WITHOUT THE PRIOR
WRITTEN CONSENT OF INERTIAL SENSE.

DIMENSIONS IN MM

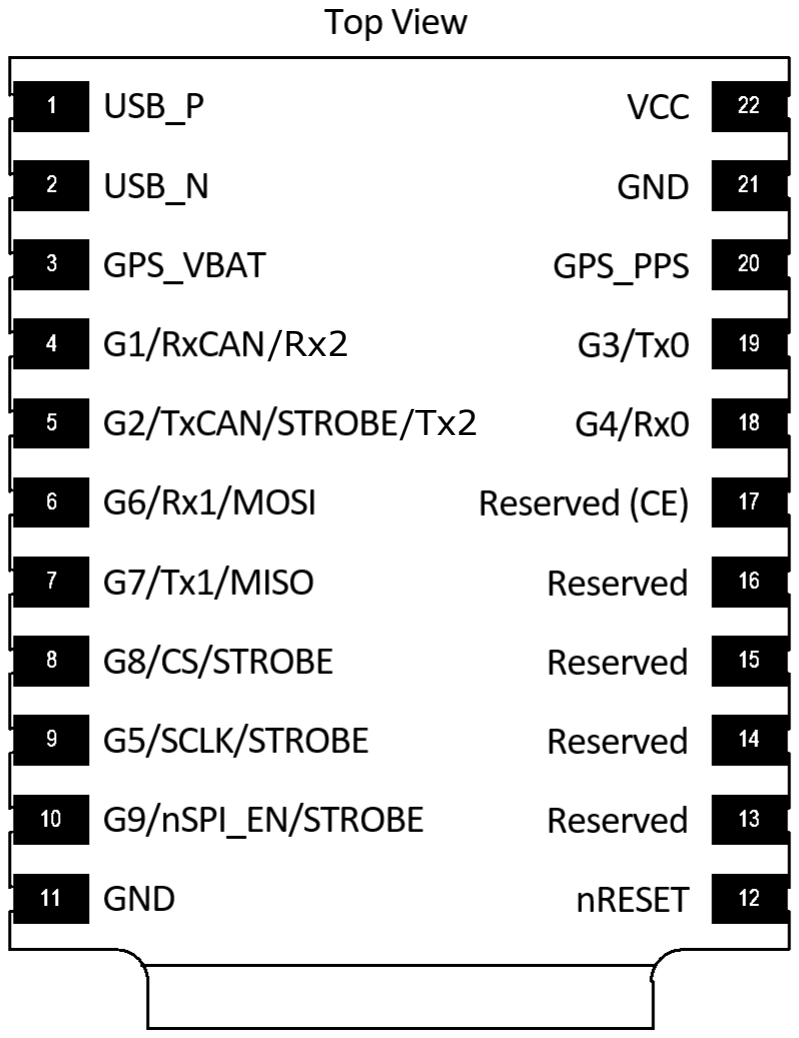
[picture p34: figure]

# uINS-3.2 Pinout

IS-uINS3-20 | A
SCALE: 3:1 | SHEET 2 OF 2
DWG. NO. | REV
A

## SIZE

## TITLE:

PROPRIETARY AND CONFIDENTIAL

THE INFORMATION CONTAINED IN THIS DOCUMENT IS THE SOLE PROPERTY OF INERTIAL SENSE. INCIDENTAL REPRODUCTION FOR THE END USER’S INTERNAL USE IS ALLOWED. ALL OTHER REPRODUCTION AND/OR DISSEMINATION IS PROHIBITED WITHOUT THE PRIOR WRITTEN CONSENT OF INERTIAL SENSE.
5 | 4 | 3 | 2 | 1

INERTIAL SENSE
72 N 720 E
Salem, UT 84653

# µIMU, µAHRS, µINS Module - Top View

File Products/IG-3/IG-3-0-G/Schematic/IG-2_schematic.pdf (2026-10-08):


Optional Interface: UART or SPI
G5/SCLK/STRBE G8/CS/STRB G9/SPI_EN/DRDY/STRB G6/Rx1/MOSI G7/Tx1/MISO

G6/Rx1/MOSI G5/SCLK/STRBE G8/CS/STRB G2/Tx2TxCAN/SDA/STRB G1/Rx2/RxCAN/SCL
GPX_Tx GPX_Rx

SPI interface is enabled
by holding G9 low during
boot up.

GNSS2_ANT | VCC 32 GND (CPAD) 0 GND 11 | 9 | GPX_Tx GPX_Rx GNSS1_PPS

120nH | 120nH | | VAUX 40 | 2

D1 | GPX_nRESET VANT D2 | | VCC_RF 16 GND 15 GNSS1_RF 12 GNSS2_RF 14 GND 13 G14/SWCLK 23 G13/DRDY/XSDA 24 G12/SWO/XSCL 25 G11/SWDIO 26 G10/BOOT 27

Pins 1-14 assignments must match on U4 and H1

G6/Rx1/MOSI G5/SCLK/STRBE G8/CS/STRB G2/Tx2TxCAN/SDA/STRB G1/Rx2/RxCAN/SCL G9/SPI_EN/DRDY/STRB G7/Tx1/MISO GNSS1_PPS

GNSS2_PPS

GPX_G10/BOOT
GPX_G6/Rx1/MOSI GPX_G7/Tx1/MISO GPX_G5/SCLK GPX_G8/CS GPX_G9/SPI_EN

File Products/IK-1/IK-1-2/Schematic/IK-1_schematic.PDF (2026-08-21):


GPX-1 GNSS or IMX-6 Module

G6/Rx1/MOSI G7/Tx1/MISO G5/SCLK G8/CS G9/SPI_EN

VAUX supplies VUSB on IMX-6 and
VUSB and VCC_RF on GPX-1.
Remove this jumper for 1.8V VCC

Project IK Breadboard Adapter | PCB IS-IK-r1-2-0 | 3000 S. Sierra Vista Way Provo, UT 84606 info@interialsense.com

Connectors Sheet | Assy IS-IK-r1.2.0-IMX-6-0

Date 8/21/2026 Time 10:07:46 AM | Sheet 1 of 6 | Size B

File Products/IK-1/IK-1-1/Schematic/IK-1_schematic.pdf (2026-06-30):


GPX-1 GNSS or IMX-6 Module

G6/Rx1/MOSI G7/Tx1/MISO G5/SCLK G8/CS G9/SPI_EN

VUSB Pad USB.VBUS

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

Project IK Breadboard Adapter | IS-IK-r1-1 PCB | 3000 S. Sierra Vista Way Provo, UT 84606 info@interialsense.com

Sheet Connectors | Assy IS-IK-r1.1.0-GPX-1-0

Date 6/22/2026 Time 11:35:58 AM | Sheet 1 of 6 | Size B

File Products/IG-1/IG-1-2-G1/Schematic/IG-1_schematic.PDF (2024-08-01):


Pins 1-14 assignments must match on U4 and H1

G6/Rx1/MOSI G5/SCLK/STROBE G8/CS/STROBE G3/Tx0 G4/Rx0 G2/Tx2TxCAN/SCL/STROBE G1/Rx2/RxCAN/SDA

G6/Rx1/MOSI G5/SCLK/STROBE G8/CS/STROBE G2/Tx2TxCAN/SCL/STROBE G1/Rx2/RxCAN/SDA G9/SPI_EN/STROBE G7/Tx1/MISO GPS.TIMEPULSE G3/Tx0 G4/Rx0

1 1
GND 21

G13/DRDY/XSDA

SPI-EN GPS.TP


C:\_IS\hdw\IS-hdw\Products\IG-1-2-G1\Altium\Source Files\GPS.SchDoc

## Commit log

2022-07-22 Update uIG5 model files
    [uINS-5p0.step]
2022-07-23 Add EVB-2 project files
    [BOM Purchase-EVB_r2-1(IS-EVB-r2.1.2-G2-R).xlsx, CAN.SchDoc, CON-USB.SchDoc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]
2022-07-23 Renamed directories with minor version number
    [BOM Purchase-EVB_r2-1(IS-EVB-r2.1.2-G2-R).xlsx, CAN.SchDoc, CON-USB.SchDoc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]
2022-07-23 Removed uINS-4 and added minor version to uIG-5
    [uINS-4-1.step]
2022-07-23 Renamed folder
    [Project Design - EVB.xlsx]
2022-07-23 Renamed directories
    [CAN.SchDoc, Project Design - EVB.xlsx, uINS.SchDoc]
2022-07-23 Added uIG5 project
    [GPS.SchDoc, Main.SchDoc, Project Design - EVB.xlsx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]
2022-07-23 Created integrated libraries
    [EVB_r2-1.PrjPCB, uIG5_r0.PrjPCB]
2022-07-23 Updated uIG5 project
    [EVB_r2-1.PrjPCB, IS-EVB-2.PcbLib, IS-EVB-2.SchLib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]
2022-07-23 Revert uIG5 directory rename
    [GPS.SchDoc, Main.SchDoc, uIG5_r0.PrjPCB]
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2022-07-23 Renamed library file
    [IS-uIG5-0.PcbLib, IS-uIG5-0.SchLib]
2022-07-23 Update schematic
    [Main.SchDoc]
2022-07-23 Renaming directories
    [uINS-3p1-G2.step, uINS-3p2-G2.step]
2022-07-23 Renamed directories. Added features to uINS-5
    [uINS-5p0.step]
2022-07-25 Update accuracy spec
    [uIG5_r0.PrjPCB]
2022-07-26 Update uINS-5.0 library file
    [IS-uINS-5.PcbLib, uINS-5p0.step]
2022-07-29 Rename uIG5 to uIG-1 and move GPS_RESET to free up SPI DRDY (#2)
    * Update footprint in uIG5
    * Rename uIG5 to uIG-1
    * Renamed uIG5 to uIG-1
    * More renaming
    * Updating uIG5 design
    * Added files
    * Moved GPS reset line to make SPI DRDY available on uIG-1
    * Revert "Rename uIG5 to uIG-1 and move GPS_RESET to free up SPI DRDY"
2022-07-29 Squash merge rename_uIG5_to_uIG-1
    [EVB_r2-1.PrjPCB, GPS.SchDoc, IS-uIG-1.PcbLib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]
2022-07-29 Added missing step files
    [uINS-5.0.step]
2022-07-29 Added pads to step modules
    [IS-EVB-2.PcbLib, IS-EVB-2.SchLib, IS-uIG-1.PcbLib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]
2022-07-29 Update uINS-5.0 model
    [uINS-5.0.4.step]
2022-07-29 Renamed uIG5 to uIG-1
    [uIG_r1-0.PrjPCB]
2022-07-29 Update uIG-1 draftsman docs and README.md
    [uIG_r1-0.PrjPCB]
2022-07-30 Zip step files to prevent corruption
    [uINS-3p1-G2.step, uINS-3p2-G2.step, uINS-5.0.4.step]
2022-08-01 Added missing pad to uIG step model
    [uIG_r1-0.PrjPCB]
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2022-08-05 Rename uins5 to imx5 (#3)
    * Renamed uINS-5 to IMX-5
    * Renamed uINS to IMX
    * Renamed uIG to IG
    * Renamed uIG to IG
    [GPS.SchDoc, IG_r1-0.PrjPCB, IS-IG-1.PcbLib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]
2022-08-17 Update IG project
    [IS-IMX-5.PcbLib, Main.SchDoc]
2022-08-18 Updated IMX-5 step model
    [IS-IG-1.PcbLib, IS-IMX-5.PcbLib]
2022-08-20 Revised IG-1.0 to IG-1.1
    [GPS.SchDoc, IG_r1-0.PrjPCB, IG_r1-1.PrjPCB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]
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2022-08-31 Fixed case
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2022-10-23 Switch IG-1 U4 to standard no BOM
    [Main.SchDoc]
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2022-12-02 Working on GPX-1 footprint
    [IS-GPX-1.PcbLib, IS-GPX-1.SchLib, IS_PCB_Libraries.PrjPcb]
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2022-12-03 More documentation for GPX-1
    [IS-GPX-1.PcbLib, IS-GPX-1.SchLib, IS-IMX-5.PcbLib]
2022-12-03 Moved Example_IMX5_GPX1 project into IS-hdw
    [Example_IMX5_GPX1.PcbDoc, Example_IMX5_GPX1.PrjPcb, IS-GPX-1.PcbLib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]
2022-12-03 More work on Example_IMX5_GPX1 interface
    [Example_IMX5_GPX1.PcbDoc, Example_IMX5_GPX1.PrjPcb, Main.SchDoc]
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2022-12-07 Add VCC_RF to GPX-1 pinout
    [Example_IMX5_GPX1.PcbDoc, Example_IMX5_GPX1.PrjPcb, IS-GPX-1.PcbLib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]
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2022-12-22 Updated IG-2 with changes
    [IS-GPX-1.SchLib, Main.SchDoc]
2022-12-22 Update IG-2 for ordering
    [IG_r2-0.PrjPCB, Main.SchDoc]
2022-12-23 Removed SWD connectors from BOM. Added part numbers for D1 D2
    [IG_r2-0.PrjPCB, Main.SchDoc]
2023-01-07 Update shield with generic version number
    [IS-GPX-1.PcbLib, IS-IMX-5.PcbLib]
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2023-04-06 Add dimensions to GPX and IMX footprints.
    [Example_IMX5_GPX1.PcbDoc, IS-GPX-1.PcbLib, IS-IMX-5.PcbLib]
2023-04-06 Development (#5)
    * Created GPX-1 project
    * Working on GPX-1 footprint
    * Updated GPX-1 library
    * More documentation for GPX-1
    * Moved Example_IMX5_GPX1 project into IS-hdw
    * More work on Example_IMX5_GPX1 interface
    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
    [Example_IMX5_GPX1.PcbDoc, Example_IMX5_GPX1.PrjPcb, Figure.SchDoc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]
2023-04-25 Tied VBAT to 3.3V through diode for IG1 and IG2 when USB is used for power.
    [IG_r1-1-G1.PrjPCB, IG_r1-1-G2.PrjPCB, IG_r2-0.PrjPCB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]
2023-05-05 Update 3D step models
    [IS-GPX-1.PcbLib, IS-IG-2.PcbLib, IS-IMX-5.PcbLib]
2023-05-05 Center CAN on IMX-5
    [IS-IMX-5.PcbLib]
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2024-07-03 Added P-CAD footprint for IG-2
    [IS-IG-2.PcbLib]
2024-07-04 Add IG-1-G1 dimension information
    [IS-IG-1-G1.PcbLib, IS-IG-1-G2.PcbLib, IS-IG-1.PcbLib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]
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2024-07-25 added ik-r1.0.0 to repo
    [Connectors.SchLib, General.SchLib, IK_r1-0.PrjPCB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]
2024-08-01 IG-1.2 revision (#12)
    * WIP
    * Fix more version numbers
    * Fix IG-1 pinout
    * Fix IG-1 pinout
    [GPS.SchDoc, IG_r1-1-G1.PrjPCB, IG_r1-1-G2.PrjPCB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]
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2024-08-01 Fix year
    [Connectors.SchLib, General.SchLib, IS-GPX-1.PcbLib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]
2024-08-01 Adjust RF traces for 50 ohm impedance
    [IK_r1-0.PrjPCB]
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2024-08-01 Fix merge and revise header layout in schematic
    [IK_r1-0.PrjPCB, Main.SchDoc]
2024-08-08 Exclude U4 from IG-1 BOM (#13)
    [Main.SchDoc]
2024-08-08 Add directory version (#14)
    * More rename
    * Move IK-1-0
    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
    [BOM Purchase-EVB_r2-1(IS-EVB-r2.1.2-G2-R).xlsx, CAN.SchDoc, CON-USB.SchDoc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]
2024-08-08 Fix IK-1 image and rotage PCB 90
2024-08-23 Fix IG-2 R2 description
    [Main.SchDoc]
2024-09-05 Added solder paste to IMX GPX footprints
    [IS-GPX-1.PcbLib, IS-IG-1-G1.PcbLib, IS-IG-1-G2.PcbLib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]
2024-11-05 Update IK for manufacturing (#15)
    [IK_r1-0.PrjPCB, Main.SchDoc]
2024-12-09 fix r3 on gpx-ik
    [Main.SchDoc]
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2026-04-01 Created IG-2.1 with IMX-6
    [IG-2.PCBDOC, IG_r2-1.PrjPCB, IS-IG-2.PcbLib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]
2026-04-02 Adding USB-C to IK-1.1
    [IK-1.PCBDOC, IK_r1-0.PrjPCB, Main.SchDoc]
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2026-04-02 Finished IK-1.1.0 w/ IMX-6
    [IK-1.PCBDOC, IK-r1-0.step, IK-r1-1.step]
2026-06-23 fix ik output
    [IK_r1-1.PrjPCB]
2026-06-25 more ik issues
    [IK-1.PCBDOC, IK_r1-1.PrjPCB, Main.SchDoc]
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2026-08-21 Fixed IK-1.2 ground plane
    [IK-1.PCBDOC]
2026-09-15 Renamed IMX-6.0 to IMX-6.1 and updated spec
    [IMX-6.step, IS-IMX-6.PcbLib, IS-IMX-6.SchLib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]
2026-09-21 Minor PCB fix to IK-1 board
    [IK-1.PCBDOC, IK_r1-2.PrjPCB]
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2026-10-08 add new project setting
    [IG_r3-0-G.PrjPCB]
2026-10-08 ig3 and ik1.2 updates
    [IG-3.PCBDOC, IG_r3-0-G.PrjPCB, IK-1.PCBDOC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]
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2026-10-24 Ig3 add mounting holes (#26)
    * hole changes
    * update lga schematic
    * IG-3g ready for review
    * Fix mounting holes
    ---------
    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
2026-11-03 Fixed IMX-5 footprint pin numbering
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
